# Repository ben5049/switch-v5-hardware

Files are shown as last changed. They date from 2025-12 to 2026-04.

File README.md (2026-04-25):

# Switch v5 Hardware (WIP)

KiCad design files for the 5th iteration of my single pair Ethernet (SPE) switch. It is similar to [v4](https://github.com/ben5049/switch-v4-hardware) but with more ports and an RJ45 connector so an external media converter isn't needed to connect to regular Ethernet networks.

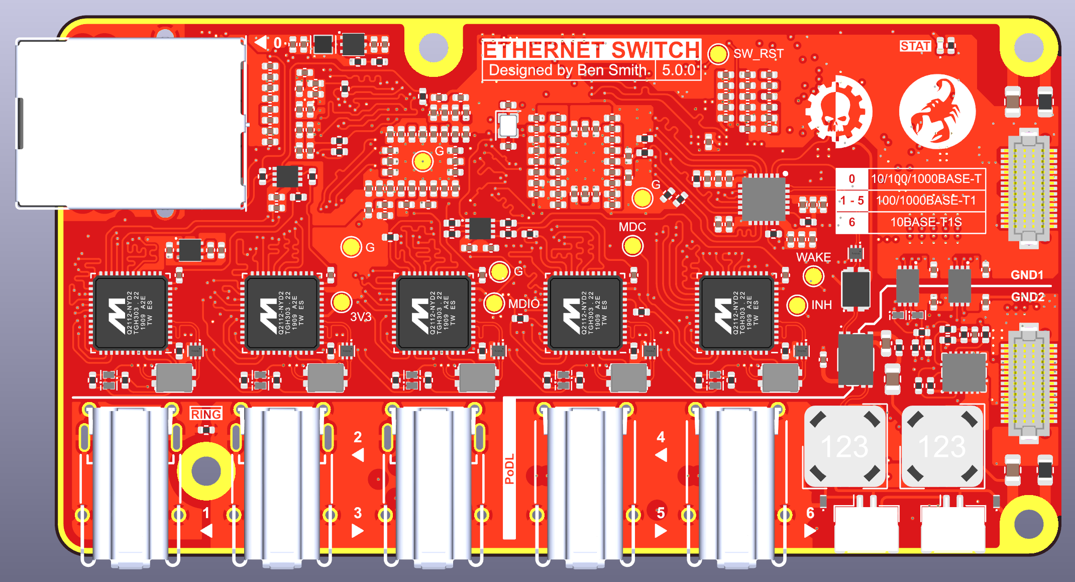
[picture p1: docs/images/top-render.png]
top-render


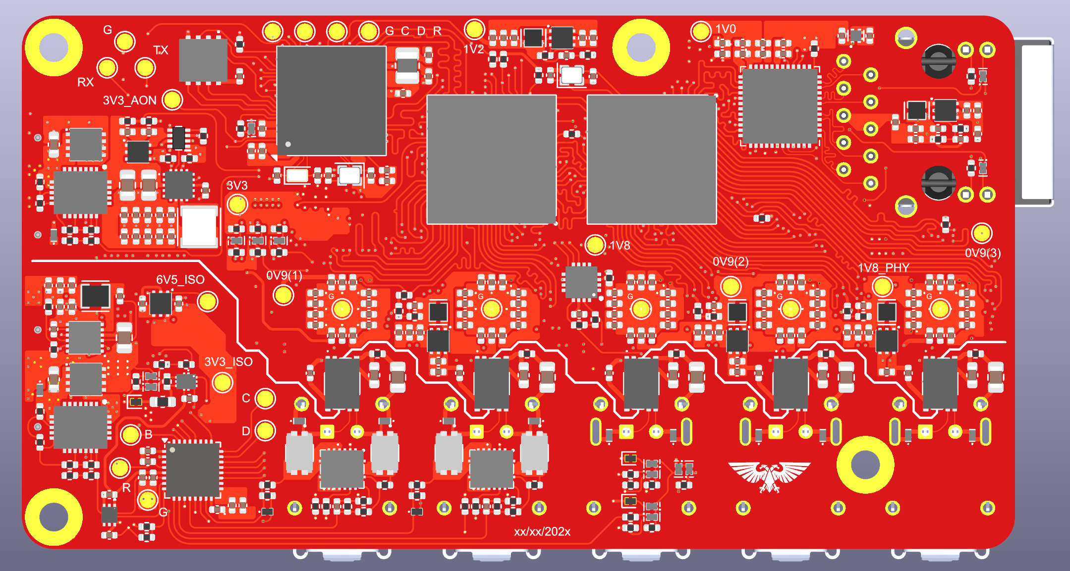
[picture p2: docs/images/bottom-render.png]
bottom-render


## Versions

| Version | Description |
| --- | --- |
| v5.1.0  | Fixed bugs from first revision |
| v5.0.0  | First release |

See the [errata](docs/errata.md) for details on bugs.

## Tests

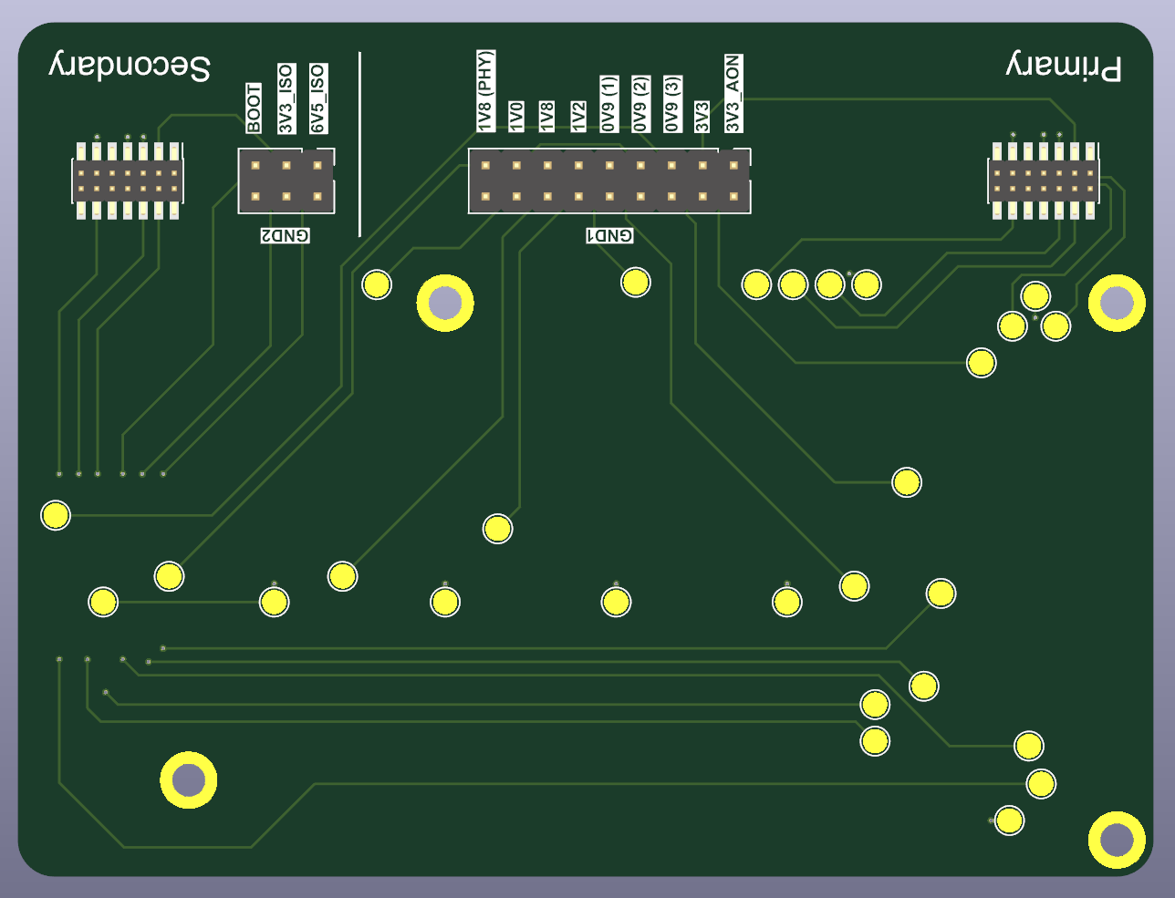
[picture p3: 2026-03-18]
docs/images/test-rig.png

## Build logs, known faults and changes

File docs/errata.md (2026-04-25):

# Switch v5 Errata

## Contents

- [1 Switch v5](#1-switch-v5)
    - [1.1 Wrong IO voltage on switch 1 ports 3 & 4](#11-wrong-io-voltage-on-switch-1-ports-3--4)

## Key

- A = limitation present, workaround available
- N = limitation present, no workaround available
- P = limitation present, partial workaround available
- "-" = limitation absent

## 1 Switch v5

| **Bug** | **5.0.0** | **5.1.0** |
|---|---|---|
| [Wrong IO voltage on switch 1 ports 3 & 4](#11-wrong-io-voltage-on-switch-1-ports-3--4) | A | - |

### 1.1 Wrong IO Voltage on Switch 1 Ports 3 & 4

The IO voltage on the SJA1105Q switch chip 1 ports 3 and 4 is incorrectly set to 3.3V when it should be set to 1.8V. This means PHY 3 doesn't work, and no data can be transferred between the left half of the switch (PHYs 0-3) and the right half of the switch (PHYs 4-6 and the host MCU). By cutting two planes and soldering on a wire between the port 3 & 4 supply capacitors and 1.8V, it is possible to fix this issue. However, PHY3 and switch 0 may be damaged if the device was turned on and traffic was sent at 3.3V.

To fix this issue two cuts need to be made. One from the top going down to inner layer 2, and one simpler one from the bottom. Both are shown in green in the images below:

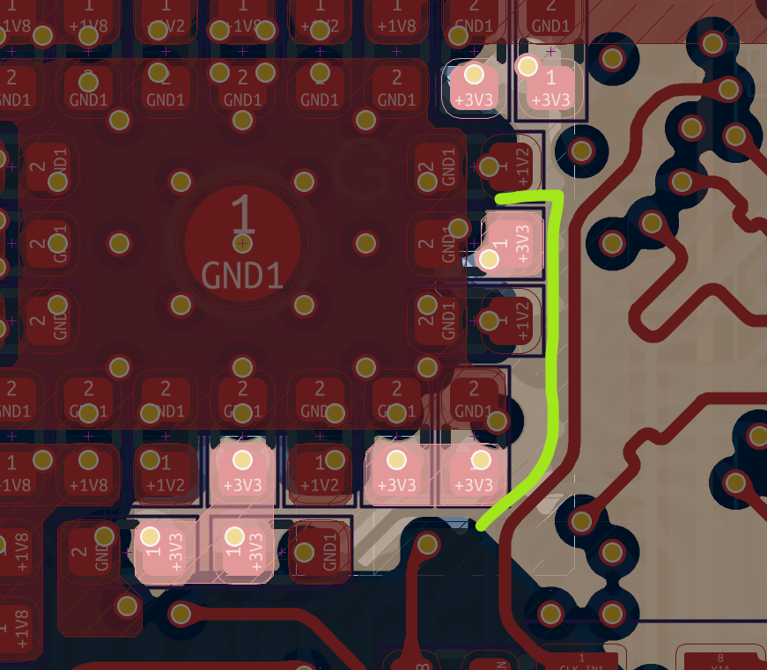
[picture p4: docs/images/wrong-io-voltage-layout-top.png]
wrong-io-voltage-layout-top

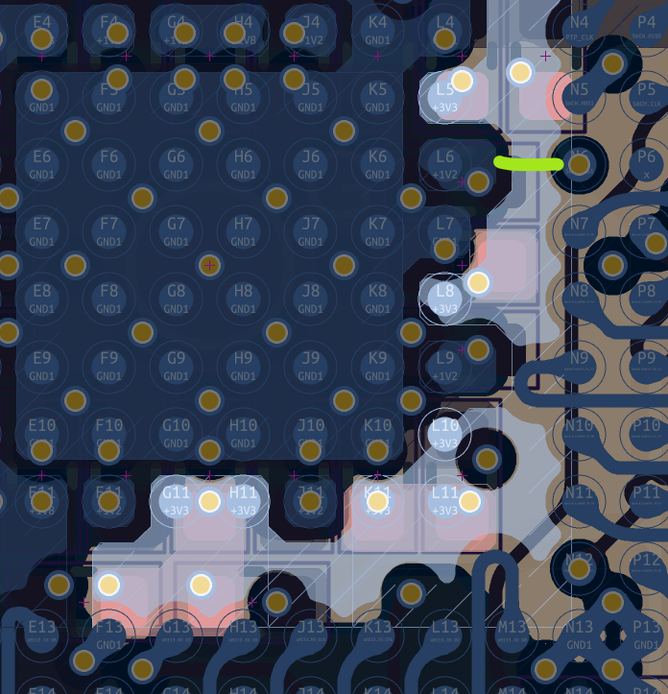
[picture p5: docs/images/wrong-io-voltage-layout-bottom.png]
wrong-io-voltage-layout-bottom


After doing these cuts, a wire needs to be soldered to connect the now floating VDDIO_MII pins to 1.8V. The final bodge can be seen below:

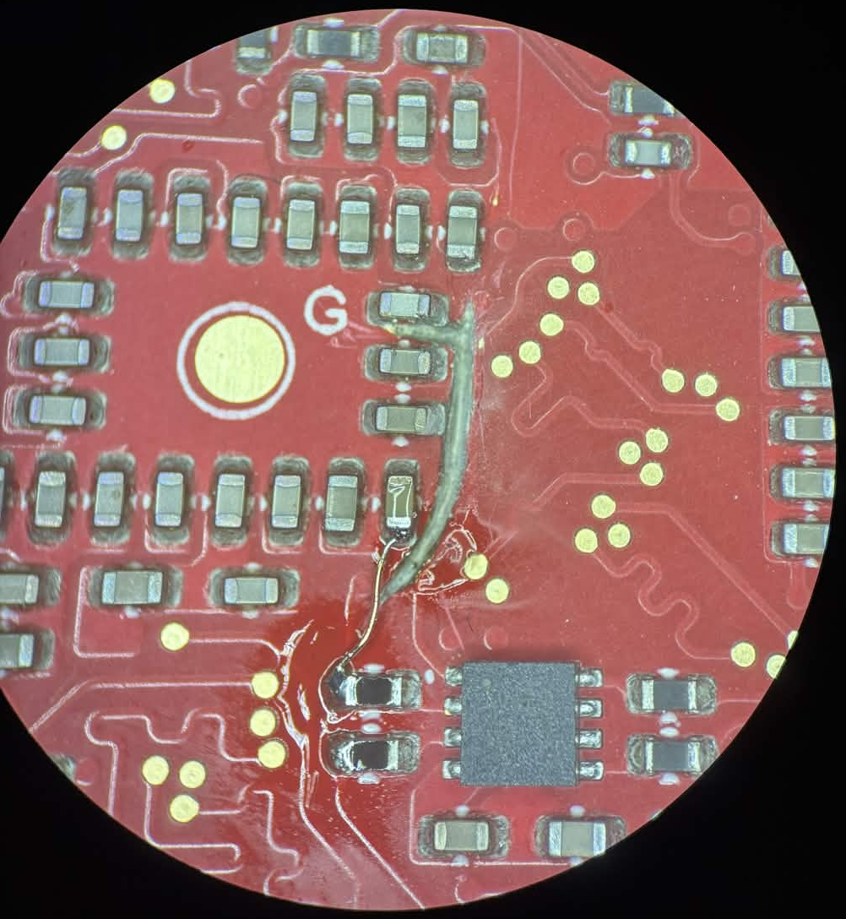
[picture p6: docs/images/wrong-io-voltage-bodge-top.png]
wrong-io-voltage-bodge-top

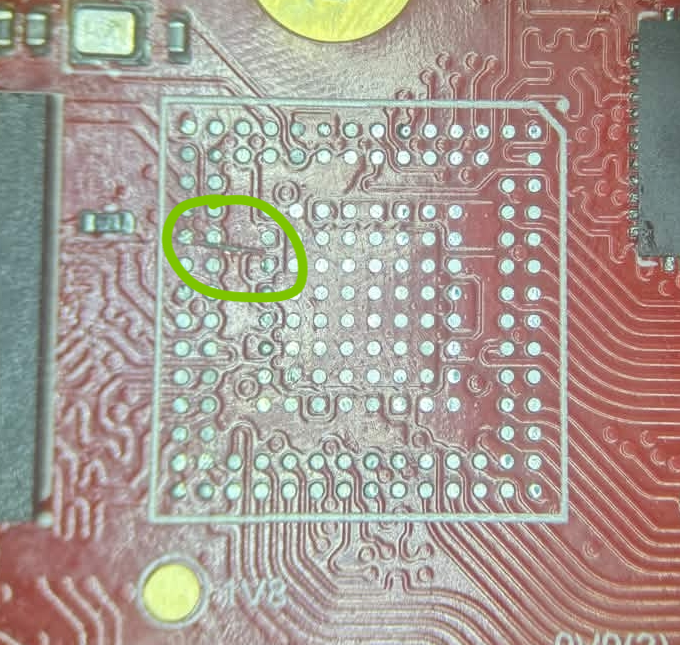
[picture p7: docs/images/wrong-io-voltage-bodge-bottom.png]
wrong-io-voltage-bodge-bottom


Note that care must be taken not to damage the trace running parallel to the top cut since it is a 50MHz clock that drives PHYs 3 to 5.

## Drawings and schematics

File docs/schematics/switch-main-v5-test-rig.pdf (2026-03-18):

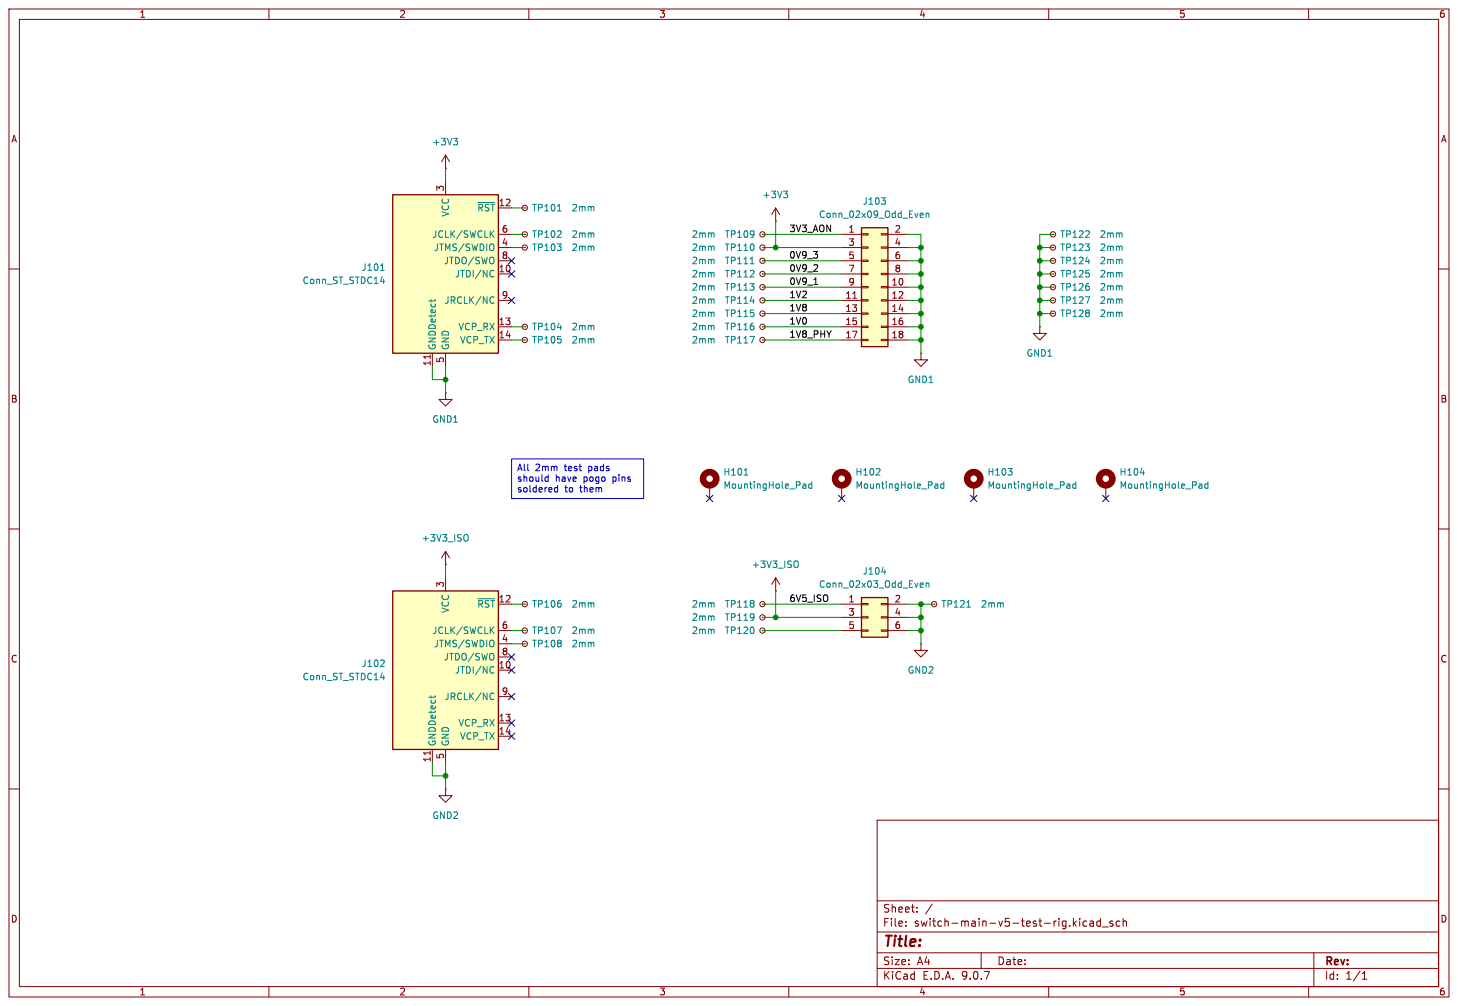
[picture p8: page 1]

All 2mm test pads
should have pogo pins

Id: 1/1 Title: File: switch-main-v5-test-rig.kicad_sch Sheet: /

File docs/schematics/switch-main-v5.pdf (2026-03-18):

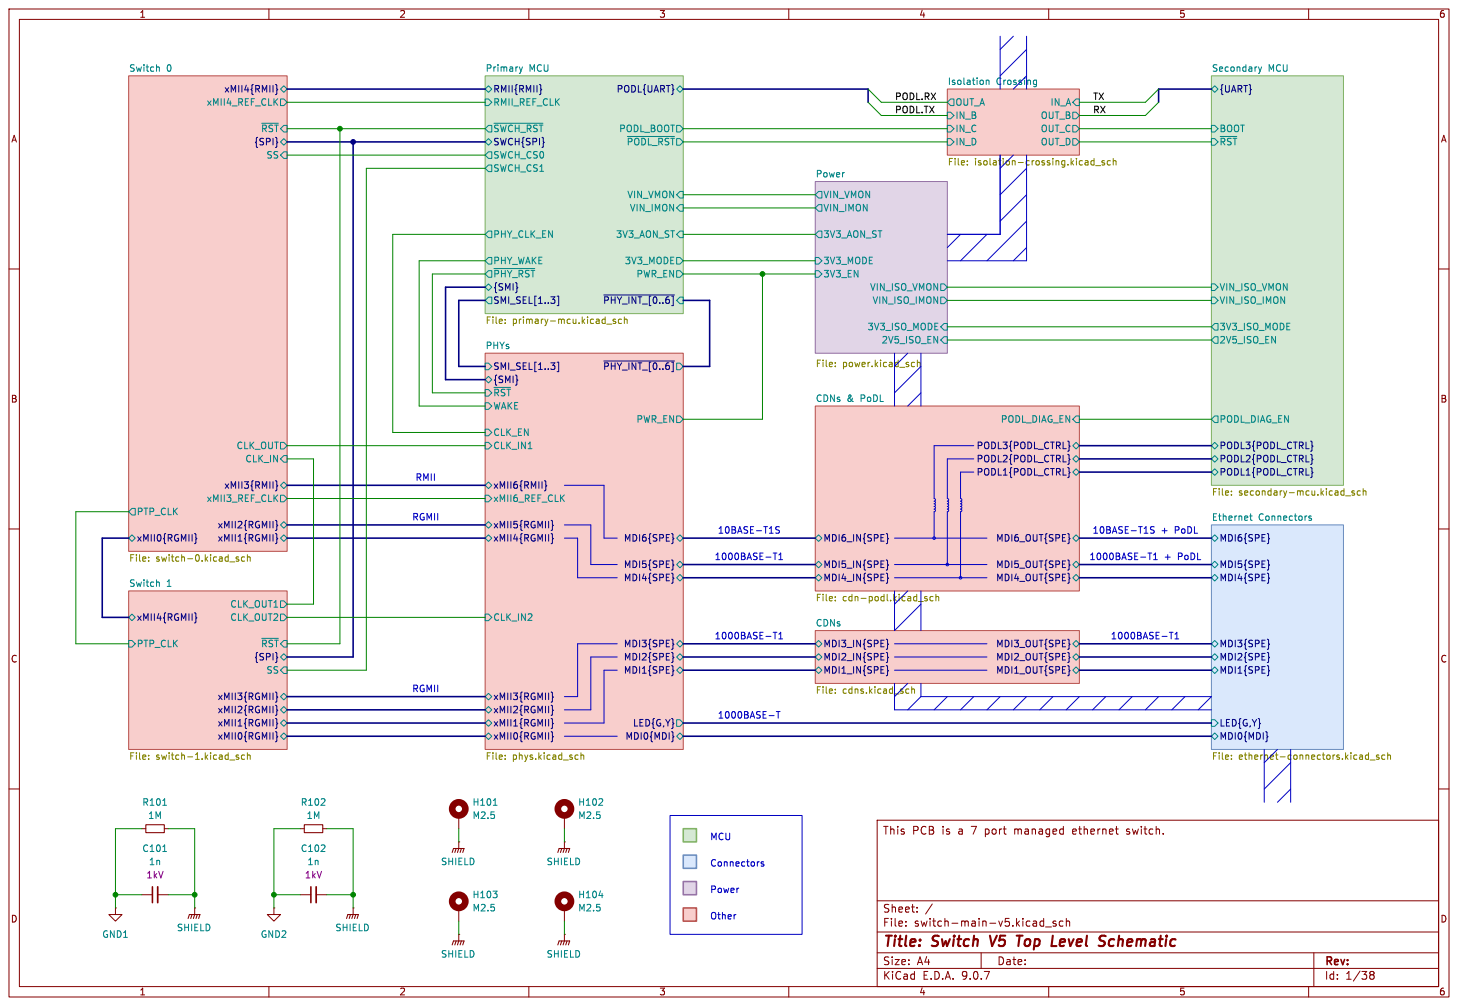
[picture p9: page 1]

LED{G,Y} Ethernet Connectors File: ethernet-connectors.kicad_sch

Id: 1/38 Title: Switch V5 Top Level Schematic

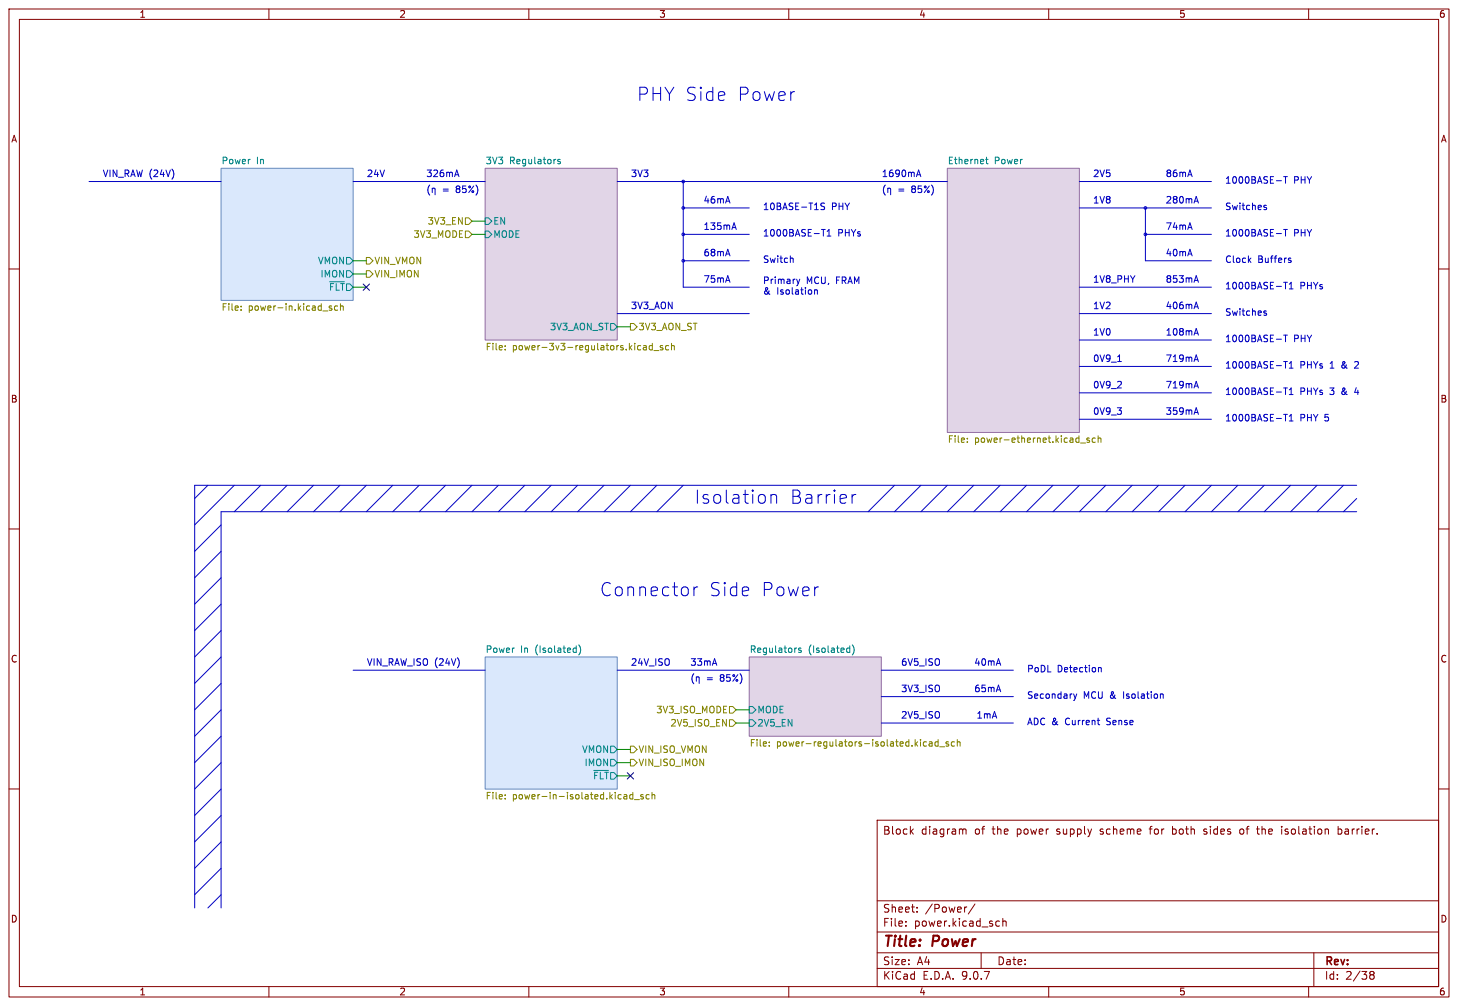
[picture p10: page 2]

46mA PHY Side Power
Ethernet Power File: power-ethernet.kicad_sch

Power In File: power-in.kicad_sch

3V3 Regulators File: power-3v3-regulators.kicad_sch

Power In (Isolated) File: power-in-isolated.kicad_sch

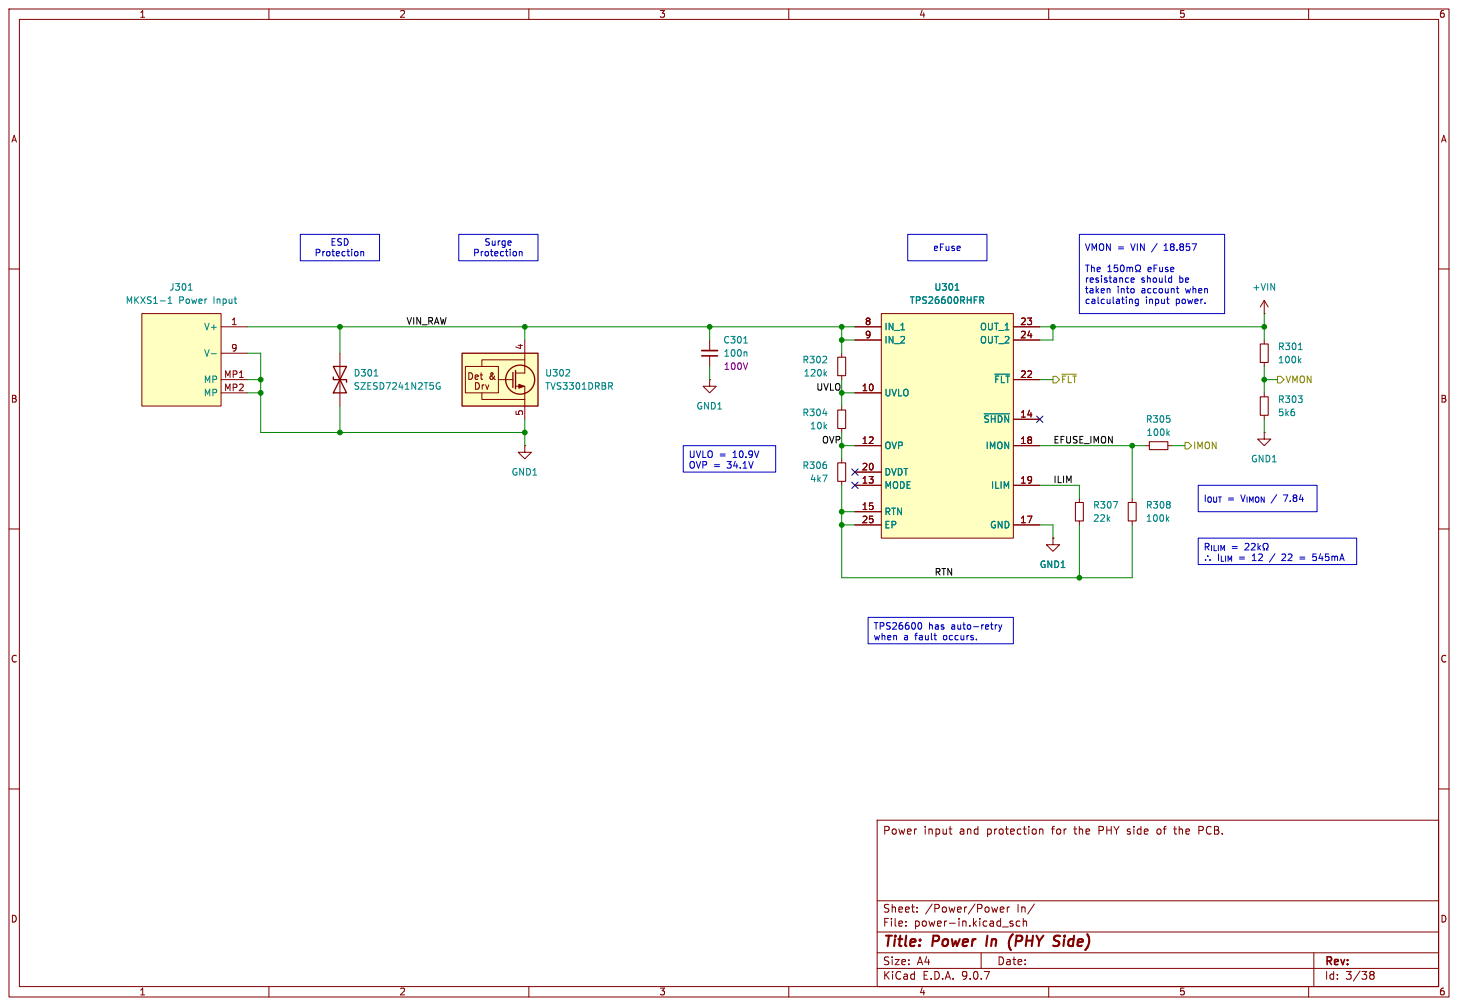
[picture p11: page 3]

I_{OUT} = V_{IMON} / 7.84 VMON = VIN / 18.857 The þÿ150m©eFuse

taken into account when

þÿ"4I_{LIM}= 12 / 22 = 545mA UVLO = 10.9V OVP = 34.1V

3V3_AON switchover
to use most efficient supply.

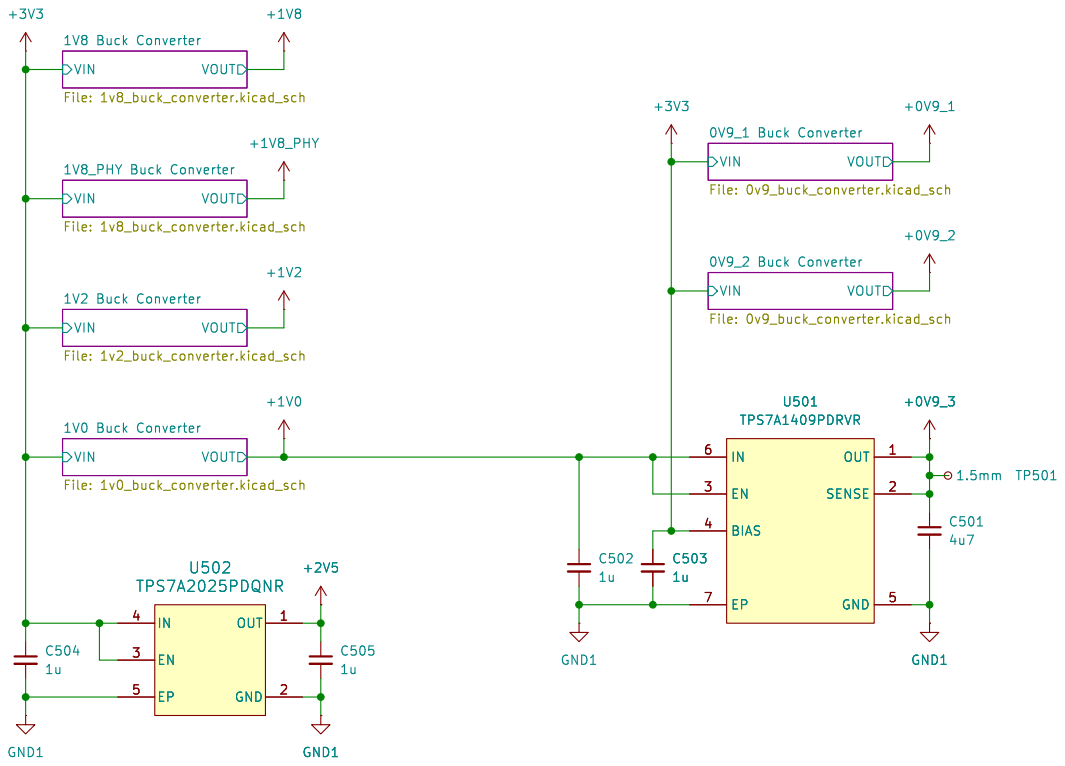
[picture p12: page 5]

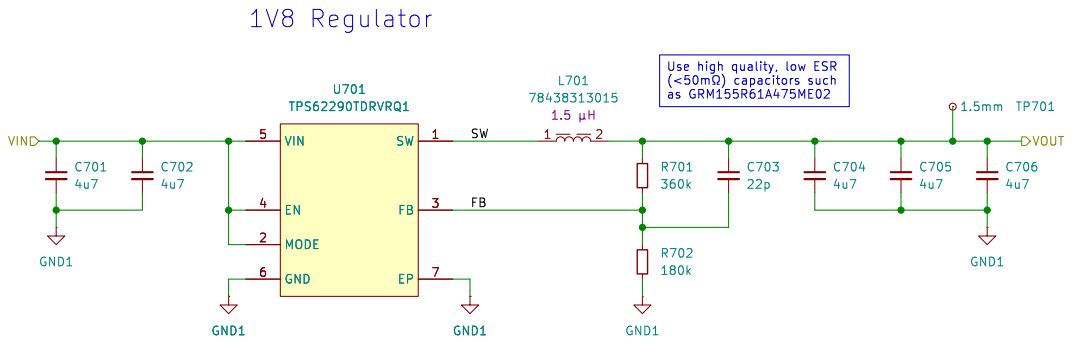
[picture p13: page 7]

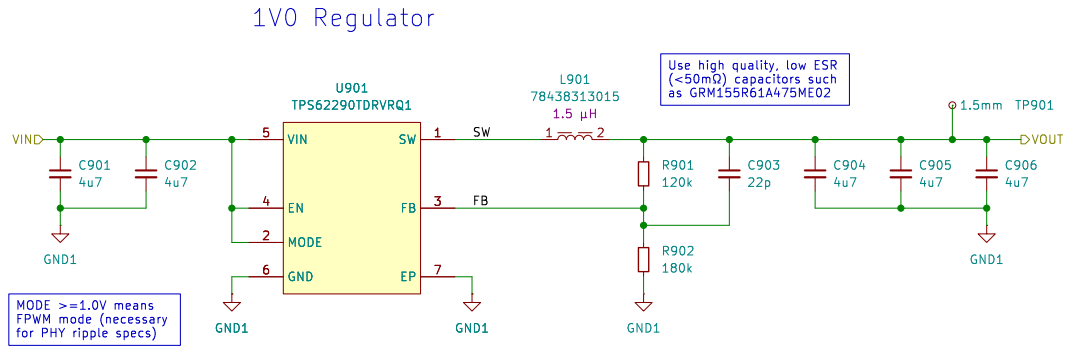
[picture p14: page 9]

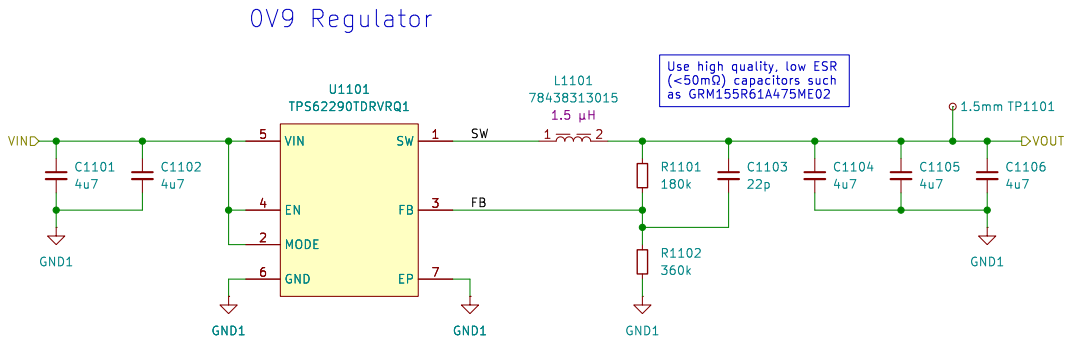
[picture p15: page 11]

taken into account when

I_{OUT} = V_{IMON} / 1.125 Can be done with integers:

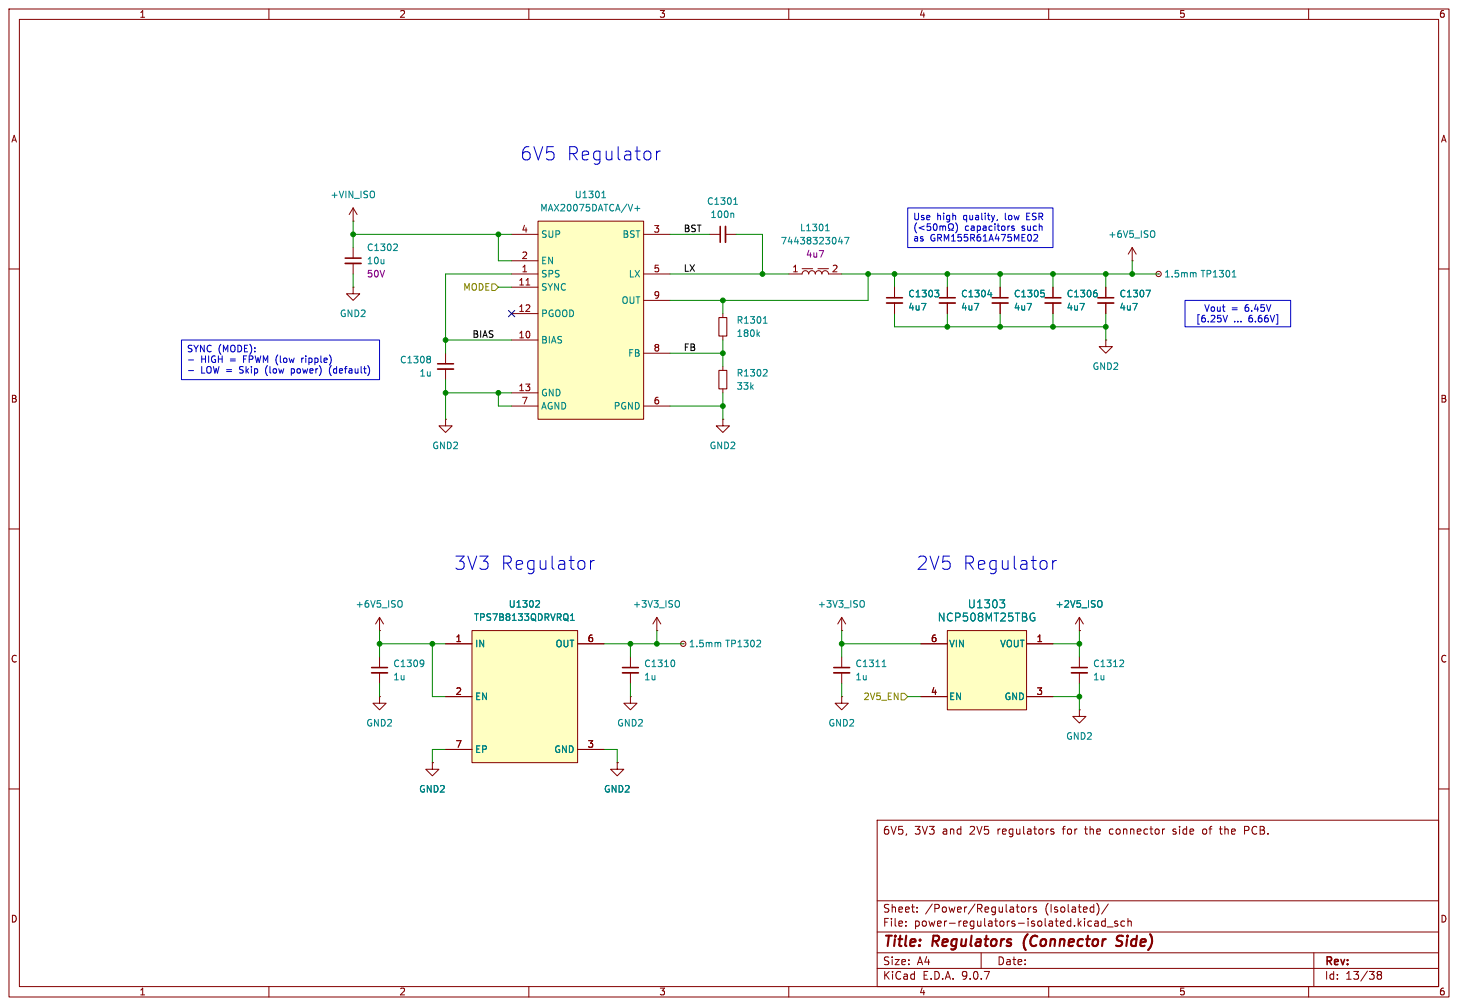
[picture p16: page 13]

[6.25V ... 6.66V] SYNC (MODE): - HIGH = FPWM (low ripple)

- LOW = Skip (low power) (default)

Id: 14/38 Title: Primary MCU

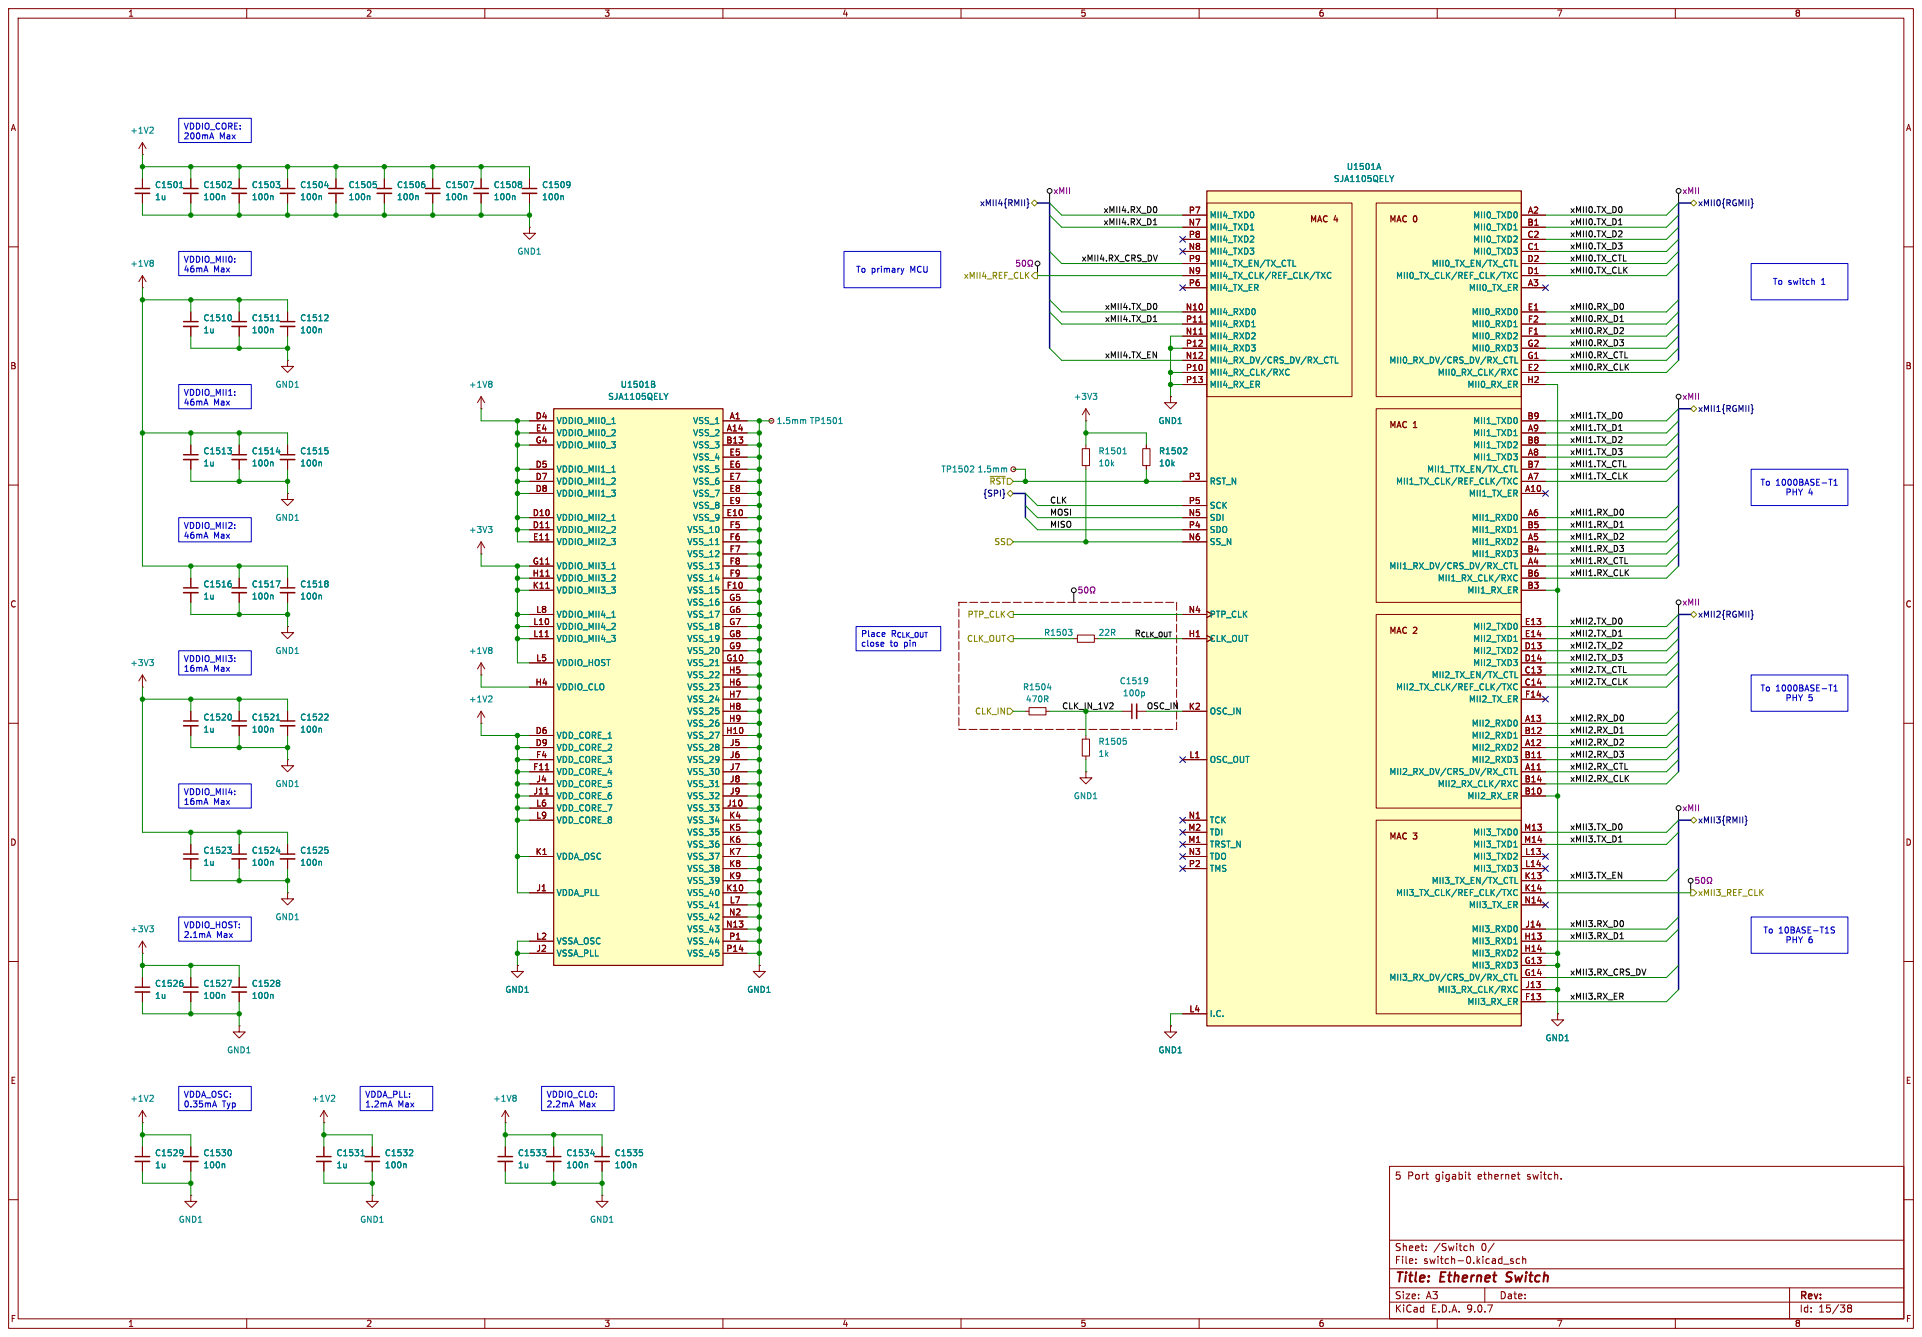
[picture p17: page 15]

Place R_{CLK_OUT} close to pin

Id: 15/38 Title: Ethernet Switch

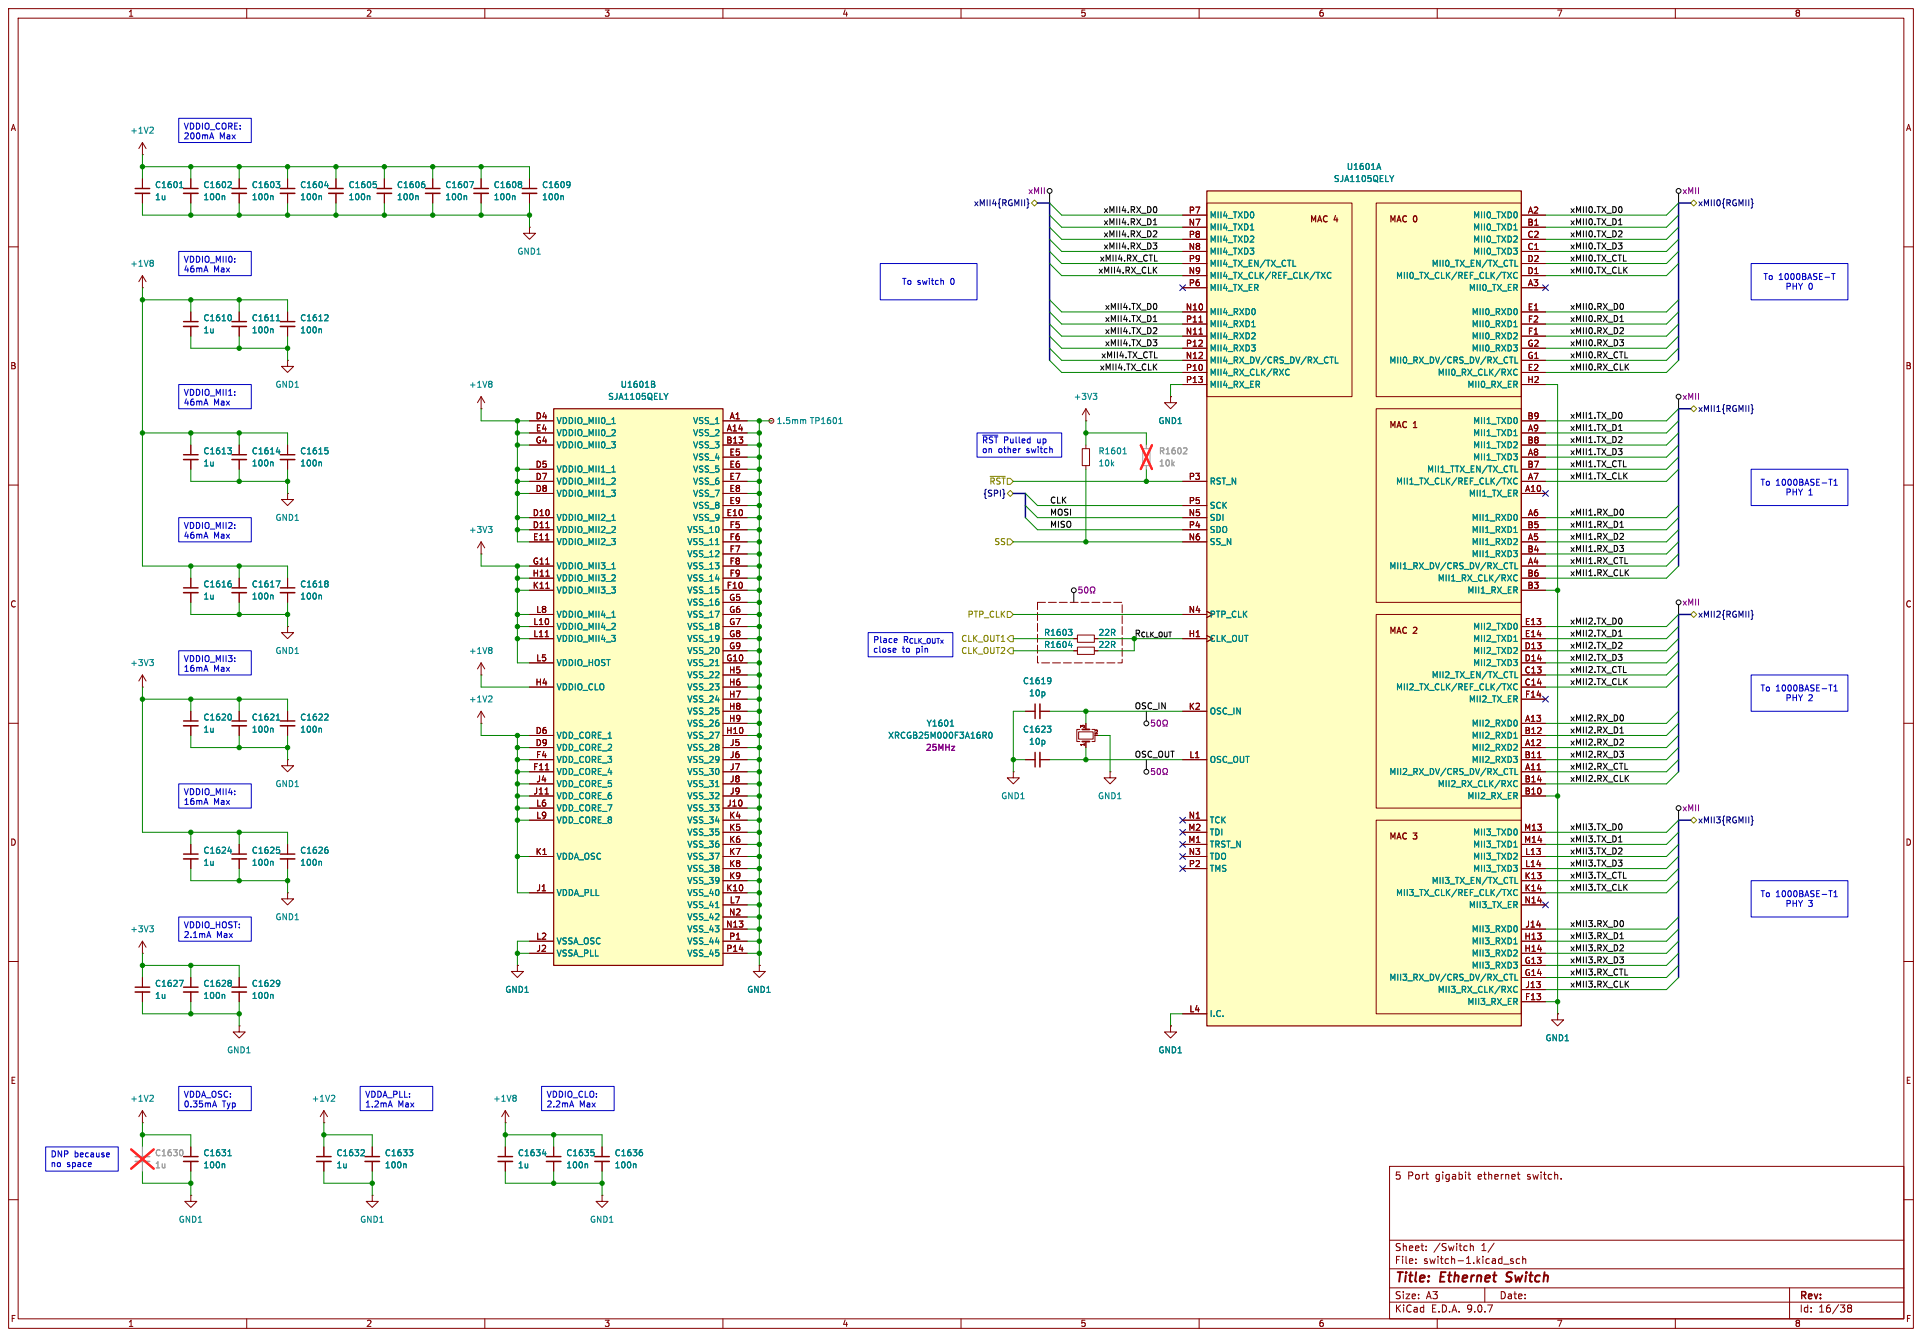
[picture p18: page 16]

Id: 16/38 Title: Ethernet Switch

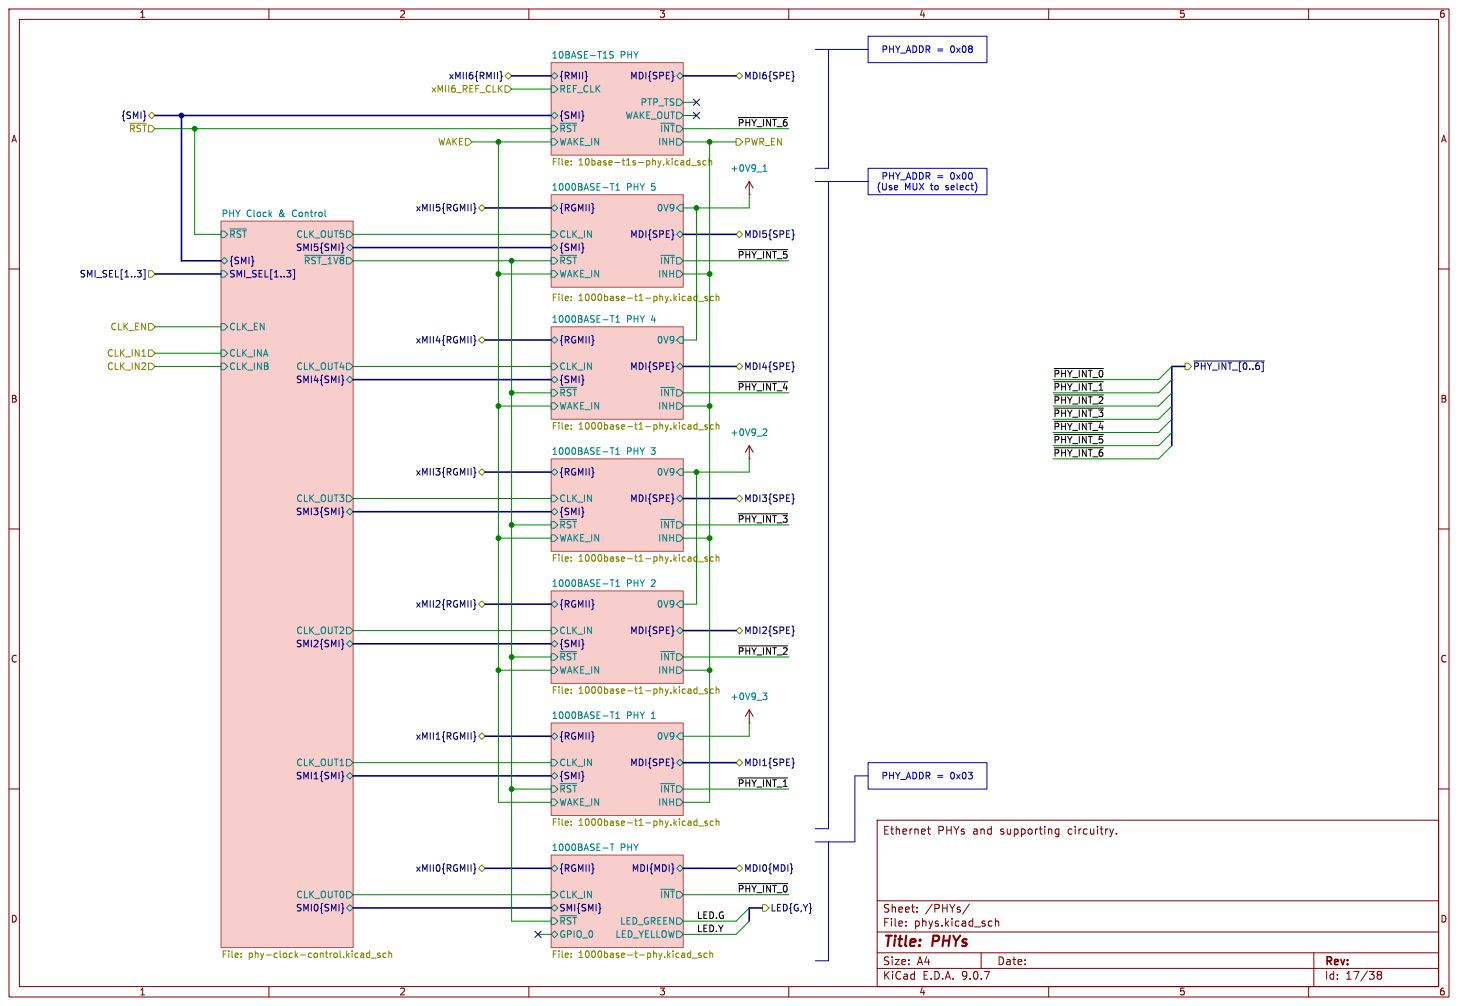
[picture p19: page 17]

PHY_ADDR = 0x00
(Use MUX to select)

File: phy-clock-control.kicad_sch


taken effect (~180ns for 3pF bus) before communicating. Source termination
1.5mm TP1803 GND1

(place close to buffer) Source termination

Id: 18/38 Title: SMI Level Shifting


MDI.TD_A_P MDI.TD_B_P MDI.TD_C_P MDI.TD_A_N

0x00. MODE[1:0] = 0x00 means
the PHY will start as a


0x00. MODE[1:0] = 0x00 means
the PHY will start as a


0x00. MODE[1:0] = 0x00 means
the PHY will start as a

0x00. MODE[1:0] = 0x00 means
the PHY will start as a


0x00. MODE[1:0] = 0x00 means
the PHY will start as a


Id: 26/38 Title: CDNs and PoDL



If the output is shorted
the current is still limited

Each channel can be enabled
devices. Since the outputs share
a current source, only one
channel can be checked at a

be withing 2.5V ADC range.

Id: 30/38 Title: PoDL Detection, Switching and Monitoring

voltage drop across the 1

IMON can go up to
limits this to be withing 2.5V ADC range.

Id: 31/38 Title: MPoE Detection, Switching and Monitoring




Id: 36/38 Title: Ethernet Connectors


Id: 37/38 Title: Isolation Crossing


open drain signal (without

Invert BOOT so it is LOW

Id: 38/38 Title: Secondary MCU

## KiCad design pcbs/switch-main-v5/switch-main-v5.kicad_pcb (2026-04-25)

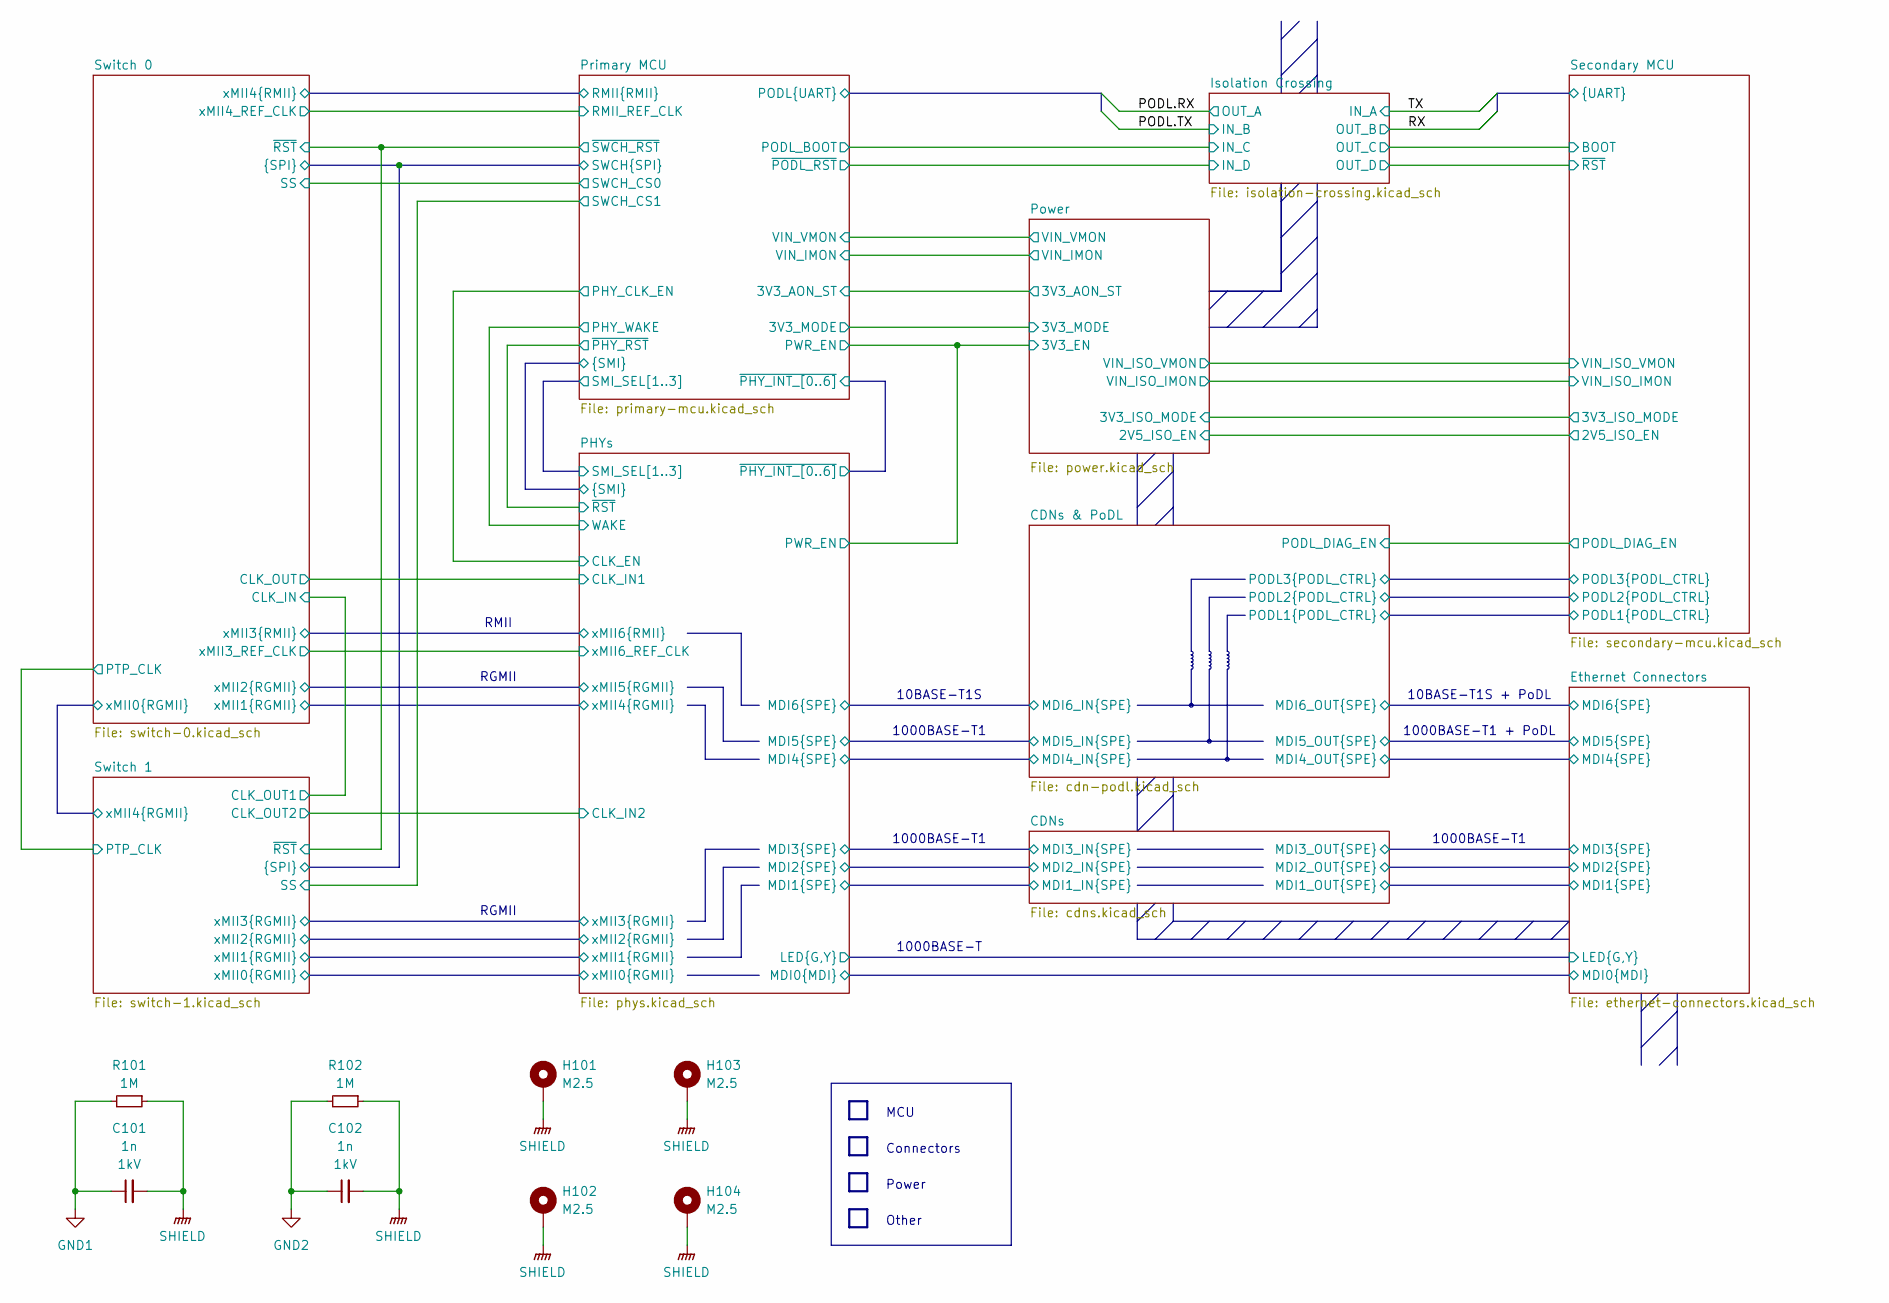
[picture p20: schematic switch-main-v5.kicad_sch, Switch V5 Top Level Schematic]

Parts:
C101, C102: 1n; C_0805; Voltage 1kV
H101, H102, H103, H104: M2.5; MountingHole_2.7mm_M2.5_Pad
R101, R102: 1M; R_0805

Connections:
GND1: C101.1, R101.2; also elsewhere on the board
GND2: C102.1, R102.2; also elsewhere on the board
SHIELD: C101.2, C102.2, H101.1 (1_1), H102.1 (1_1), H103.1 (1_1), H104.1 (1_1), R101.1, R102.1; also elsewhere on the board

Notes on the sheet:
10BASE-T1S
1000BASE-T1
Power
RGMII
Other
1000BASE-T
RMII
Connectors
1000BASE-T1 + PoDL
MCU
10BASE-T1S + PoDL

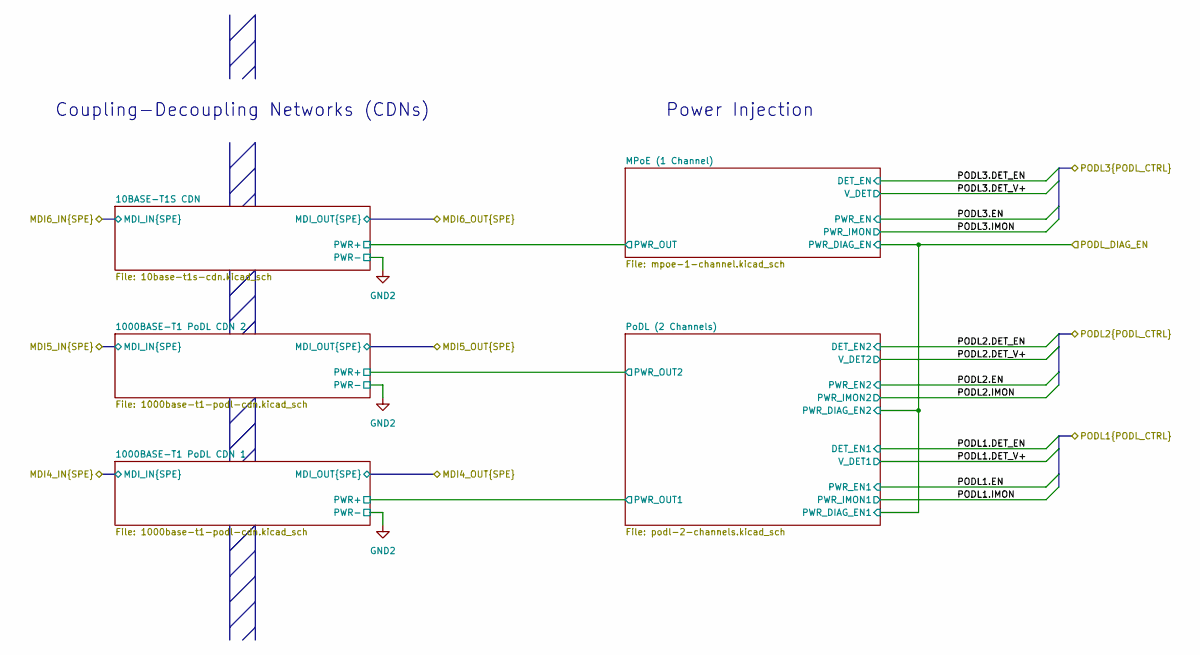
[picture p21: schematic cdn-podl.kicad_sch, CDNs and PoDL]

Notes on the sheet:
Power Injection
Coupling-Decoupling Networks (CDNs)

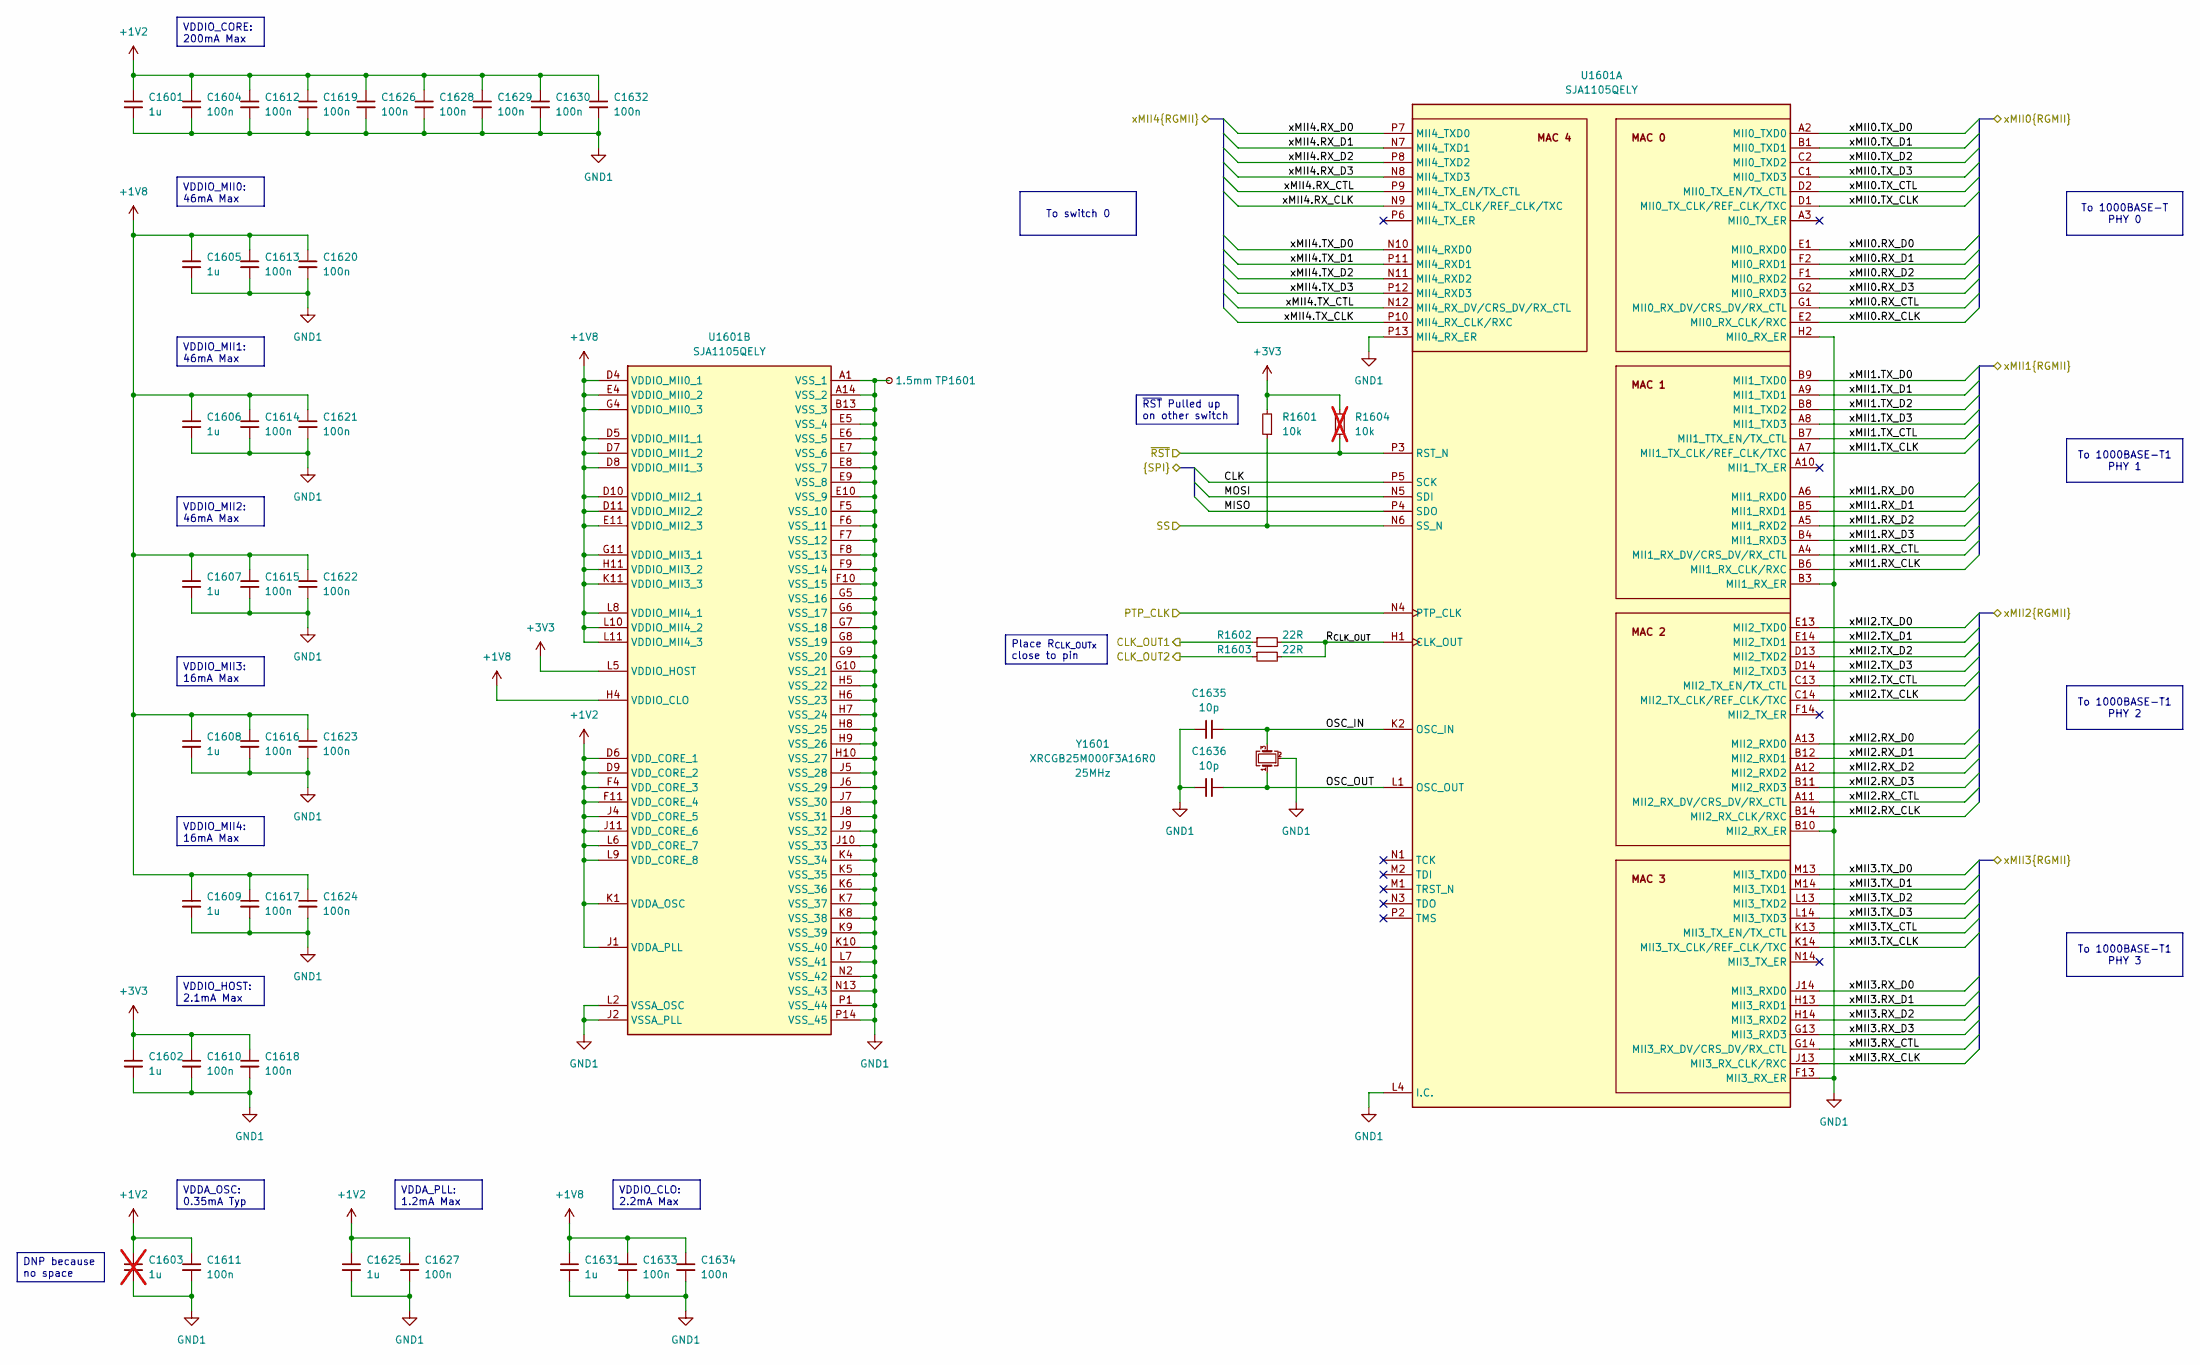
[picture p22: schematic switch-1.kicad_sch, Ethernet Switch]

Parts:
C1601, C1602, C1605, C1606, C1607, C1608, C1609, C1625, C1631: 1u; C_0402
C1603: 1u; C_0402_1005Metric; not fitted
C1604, C1610, C1611, C1612, C1613, C1614, C1615, C1616, C1617, C1618, C1619, C1620, C1621, C1622, C1623, C1624, C1626, C1627, C1628, C1629, C1630, C1632, C1633, C1634: 100n; C_0402
C1635, C1636: 10p; C_0402
R1601: 10k; R_0402
R1602, R1603: 22R; R_0402
R1604: 10k; R_0402_1005Metric; not fitted
TP1601: 1.5mm; TestPoint_Pad_D1.5mm
U1601: SJA1105QELY; BGA159C80P14X14_1200X1200X150; Mouser Part Number 771-SJA1105QELY
Y1601: XRCGB25M000F3A16R0

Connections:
+1V2: C1601.1, C1603.1, C1604.1, C1611.1, C1612.1, C1619.1, C1625.1, C1626.1, C1627.1, C1628.1, C1629.1, C1630.1, C1632.1, U1601.D6 (VDD_CORE_1), U1601.D9 (VDD_CORE_2), U1601.F4 (VDD_CORE_3), U1601.F11 (VDD_CORE_4), U1601.J1 (VDDA_PLL), U1601.J4 (VDD_CORE_5), U1601.J11 (VDD_CORE_6), U1601.K1 (VDDA_OSC), U1601.L6 (VDD_CORE_7), U1601.L9 (VDD_CORE_8); also elsewhere on the board
+1V8: C1605.1, C1606.1, C1607.1, C1608.1, C1609.1, C1613.1, C1614.1, C1615.1, C1616.1, C1617.1, C1620.1, C1621.1, C1622.1, C1623.1, C1624.1, C1631.1, C1633.1, C1634.1, U1601.D4 (VDDIO_MII0_1), U1601.D5 (VDDIO_MII1_1), U1601.D7 (VDDIO_MII1_2), U1601.D8 (VDDIO_MII1_3), U1601.D10 (VDDIO_MII2_1), U1601.D11 (VDDIO_MII2_2), U1601.E4 (VDDIO_MII0_2), U1601.E11 (VDDIO_MII2_3), U1601.G4 (VDDIO_MII0_3), U1601.G11 (VDDIO_MII3_1), U1601.H4 (VDDIO_CLO), U1601.H11 (VDDIO_MII3_2), U1601.K11 (VDDIO_MII3_3), U1601.L8 (VDDIO_MII4_1), U1601.L10 (VDDIO_MII4_2), U1601.L11 (VDDIO_MII4_3); also elsewhere on the board
+3V3: C1602.1, C1610.1, C1618.1, R1601.2, R1604.2, U1601.L5 (VDDIO_HOST); also elsewhere on the board
/PHYs/CLK_IN2: R1603.1; also elsewhere on the board
/PHYs/xMII0.RX_CLK: U1601.E2 (MII0_RX_CLK/RXC); also elsewhere on the board
/PHYs/xMII0.RX_CTL: U1601.G1 (MII0_RX_DV/CRS_DV/RX_CTL); also elsewhere on the board
/PHYs/xMII0.RX_D0: U1601.E1 (MII0_RXD0); also elsewhere on the board
/PHYs/xMII0.RX_D1: U1601.F2 (MII0_RXD1); also elsewhere on the board
/PHYs/xMII0.RX_D2: U1601.F1 (MII0_RXD2); also elsewhere on the board
/PHYs/xMII0.RX_D3: U1601.G2 (MII0_RXD3); also elsewhere on the board
/PHYs/xMII0.TX_CLK: U1601.D1 (MII0_TX_CLK/REF_CLK/TXC); also elsewhere on the board
/PHYs/xMII0.TX_CTL: U1601.D2 (MII0_TX_EN/TX_CTL); also elsewhere on the board
/PHYs/xMII0.TX_D0: U1601.A2 (MII0_TXD0); also elsewhere on the board
/PHYs/xMII0.TX_D1: U1601.B1 (MII0_TXD1); also elsewhere on the board
/PHYs/xMII0.TX_D2: U1601.C2 (MII0_TXD2); also elsewhere on the board
/PHYs/xMII0.TX_D3: U1601.C1 (MII0_TXD3); also elsewhere on the board
/PHYs/xMII1.RX_CLK: U1601.B6 (MII1_RX_CLK/RXC); also elsewhere on the board
/PHYs/xMII1.RX_CTL: U1601.A4 (MII1_RX_DV/CRS_DV/RX_CTL); also elsewhere on the board
/PHYs/xMII1.RX_D0: U1601.A6 (MII1_RXD0); also elsewhere on the board
/PHYs/xMII1.RX_D1: U1601.B5 (MII1_RXD1); also elsewhere on the board
/PHYs/xMII1.RX_D2: U1601.A5 (MII1_RXD2); also elsewhere on the board
/PHYs/xMII1.RX_D3: U1601.B4 (MII1_RXD3); also elsewhere on the board
/PHYs/xMII1.TX_CLK: U1601.A7 (MII1_TX_CLK/REF_CLK/TXC); also elsewhere on the board
/PHYs/xMII1.TX_CTL: U1601.B7 (MII1_TTX_EN/TX_CTL); also elsewhere on the board
/PHYs/xMII1.TX_D0: U1601.B9 (MII1_TXD0); also elsewhere on the board
/PHYs/xMII1.TX_D1: U1601.A9 (MII1_TXD1); also elsewhere on the board
/PHYs/xMII1.TX_D2: U1601.B8 (MII1_TXD2); also elsewhere on the board
/PHYs/xMII1.TX_D3: U1601.A8 (MII1_TXD3); also elsewhere on the board
/PHYs/xMII2.RX_CLK: U1601.B14 (MII2_RX_CLK/RXC); also elsewhere on the board
/PHYs/xMII2.RX_CTL: U1601.A11 (MII2_RX_DV/CRS_DV/RX_CTL); also elsewhere on the board
/PHYs/xMII2.RX_D0: U1601.A13 (MII2_RXD0); also elsewhere on the board
/PHYs/xMII2.RX_D1: U1601.B12 (MII2_RXD1); also elsewhere on the board
/PHYs/xMII2.RX_D2: U1601.A12 (MII2_RXD2); also elsewhere on the board
/PHYs/xMII2.RX_D3: U1601.B11 (MII2_RXD3); also elsewhere on the board
/PHYs/xMII2.TX_CLK: U1601.C14 (MII2_TX_CLK/REF_CLK/TXC); also elsewhere on the board
/PHYs/xMII2.TX_CTL: U1601.C13 (MII2_TX_EN/TX_CTL); also elsewhere on the board
/PHYs/xMII2.TX_D0: U1601.E13 (MII2_TXD0); also elsewhere on the board
/PHYs/xMII2.TX_D1: U1601.E14 (MII2_TXD1); also elsewhere on the board
/PHYs/xMII2.TX_D2: U1601.D13 (MII2_TXD2); also elsewhere on the board
/PHYs/xMII2.TX_D3: U1601.D14 (MII2_TXD3); also elsewhere on the board
/PHYs/xMII3.RX_CLK: U1601.J13 (MII3_RX_CLK/RXC); also elsewhere on the board
/PHYs/xMII3.RX_CTL: U1601.G14 (MII3_RX_DV/CRS_DV/RX_CTL); also elsewhere on the board
/PHYs/xMII3.RX_D0: U1601.J14 (MII3_RXD0); also elsewhere on the board
/PHYs/xMII3.RX_D1: U1601.H13 (MII3_RXD1); also elsewhere on the board
/PHYs/xMII3.RX_D2: U1601.H14 (MII3_RXD2); also elsewhere on the board
/PHYs/xMII3.RX_D3: U1601.G13 (MII3_RXD3); also elsewhere on the board
/PHYs/xMII3.TX_CLK: U1601.K14 (MII3_TX_CLK/REF_CLK/TXC); also elsewhere on the board
/PHYs/xMII3.TX_CTL: U1601.K13 (MII3_TX_EN/TX_CTL); also elsewhere on the board
/PHYs/xMII3.TX_D0: U1601.M13 (MII3_TXD0); also elsewhere on the board
/PHYs/xMII3.TX_D1: U1601.M14 (MII3_TXD1); also elsewhere on the board
/PHYs/xMII3.TX_D2: U1601.L13 (MII3_TXD2); also elsewhere on the board
/PHYs/xMII3.TX_D3: U1601.L14 (MII3_TXD3); also elsewhere on the board
/Primary MCU/SWCH.CLK: U1601.P5 (SCK); also elsewhere on the board
/Primary MCU/SWCH.MISO: U1601.P4 (SDO); also elsewhere on the board
/Primary MCU/SWCH.MOSI: U1601.N5 (SDI); also elsewhere on the board
/Primary MCU/SWCH_CS1: R1601.1, U1601.N6 (SS_N); also elsewhere on the board
/Primary MCU/~SWCH_RST: R1604.1, U1601.P3 (RST_N); also elsewhere on the board
/Switch 0/CLK_IN: R1602.1; also elsewhere on the board
/Switch 0/PTP_CLK: U1601.N4 (PTP_CLK); also elsewhere on the board
/Switch 0/xMII0.RX_CLK: U1601.N9 (MII4_TX_CLK/REF_CLK/TXC); also elsewhere on the board
/Switch 0/xMII0.RX_CTL: U1601.P9 (MII4_TX_EN/TX_CTL); also elsewhere on the board
/Switch 0/xMII0.RX_D0: U1601.P7 (MII4_TXD0); also elsewhere on the board
/Switch 0/xMII0.RX_D1: U1601.N7 (MII4_TXD1); also elsewhere on the board
/Switch 0/xMII0.RX_D2: U1601.P8 (MII4_TXD2); also elsewhere on the board
/Switch 0/xMII0.RX_D3: U1601.N8 (MII4_TXD3); also elsewhere on the board
/Switch 0/xMII0.TX_CLK: U1601.P10 (MII4_RX_CLK/RXC); also elsewhere on the board
/Switch 0/xMII0.TX_CTL: U1601.N12 (MII4_RX_DV/CRS_DV/RX_CTL); also elsewhere on the board
/Switch 0/xMII0.TX_D0: U1601.N10 (MII4_RXD0); also elsewhere on the board
/Switch 0/xMII0.TX_D1: U1601.P11 (MII4_RXD1); also elsewhere on the board
/Switch 0/xMII0.TX_D2: U1601.N11 (MII4_RXD2); also elsewhere on the board
/Switch 0/xMII0.TX_D3: U1601.P12 (MII4_RXD3); also elsewhere on the board
/Switch 1/OSC_IN: C1635.2, U1601.K2 (OSC_IN), Y1601.3
/Switch 1/OSC_OUT: C1636.2, U1601.L1 (OSC_OUT), Y1601.1
/Switch 1/R_{CLK_OUT}: R1602.2, R1603.2, U1601.H1 (CLK_OUT)
GND1: C1601.2, C1602.2, C1603.2, C1604.2, C1605.2, C1606.2, C1607.2, C1608.2, C1609.2, C1610.2, C1611.2, C1612.2, C1613.2, C1614.2, C1615.2, C1616.2, C1617.2, C1618.2, C1619.2, C1620.2, C1621.2, C1622.2, C1623.2, C1624.2, C1625.2, C1626.2, C1627.2, C1628.2, C1629.2, C1630.2, C1631.2, C1632.2, C1633.2, C1634.2, C1635.1, C1636.1, TP1601.1 (1_1), U1601.A1 (VSS_1), U1601.A14 (VSS_2), U1601.B3 (MII1_RX_ER), U1601.B10 (MII2_RX_ER), U1601.B13 (VSS_3), U1601.E5 (VSS_4), U1601.E6 (VSS_5), U1601.E7 (VSS_6), U1601.E8 (VSS_7), U1601.E9 (VSS_8), U1601.E10 (VSS_9), U1601.F5 (VSS_10), U1601.F6 (VSS_11), U1601.F7 (VSS_12), U1601.F8 (VSS_13), U1601.F9 (VSS_14), U1601.F10 (VSS_15), U1601.F13 (MII3_RX_ER), U1601.G5 (VSS_16), U1601.G6 (VSS_17), U1601.G7 (VSS_18), U1601.G8 (VSS_19), U1601.G9 (VSS_20), U1601.G10 (VSS_21), U1601.H2 (MII0_RX_ER), U1601.H5 (VSS_22), U1601.H6 (VSS_23), U1601.H7 (VSS_24), U1601.H8 (VSS_25), U1601.H9 (VSS_26), U1601.H10 (VSS_27), U1601.J2 (VSSA_PLL), U1601.J5 (VSS_28), U1601.J6 (VSS_29), U1601.J7 (VSS_30), U1601.J8 (VSS_31), U1601.J9 (VSS_32), U1601.J10 (VSS_33), U1601.K4 (VSS_34), U1601.K5 (VSS_35), U1601.K6 (VSS_36), U1601.K7 (VSS_37), U1601.K8 (VSS_38), U1601.K9 (VSS_39), U1601.K10 (VSS_40), U1601.L2 (VSSA_OSC), U1601.L4 (I.C.), U1601.L7 (VSS_41), U1601.N2 (VSS_42), U1601.N13 (VSS_43), U1601.P1 (VSS_44), U1601.P13 (MII4_RX_ER), U1601.P14 (VSS_45), Y1601.2 (G), Y1601.4 (G); also elsewhere on the board

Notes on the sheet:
To 1000BASE-T1 PHY 1
To 1000BASE-T1 PHY 2
VDDIO_MII3: 16mA Max
~{RST} Pulled up on other switch
To 1000BASE-T1 PHY 3
VDDIO_CLO: 2.2mA Max
VDDIO_MII2: 46mA Max
VDDIO_HOST: 2.1mA Max
VDDA_OSC: 0.35mA Typ
DNP because no space
VDDIO_MII0: 46mA Max
To switch 0
VDDA_PLL: 1.2mA Max
VDDIO_CORE: 200mA Max
Place R_{CLK_OUTx} close to pin
To 1000BASE-T PHY 0
VDDIO_MII4: 16mA Max
VDDIO_MII1: 46mA Max

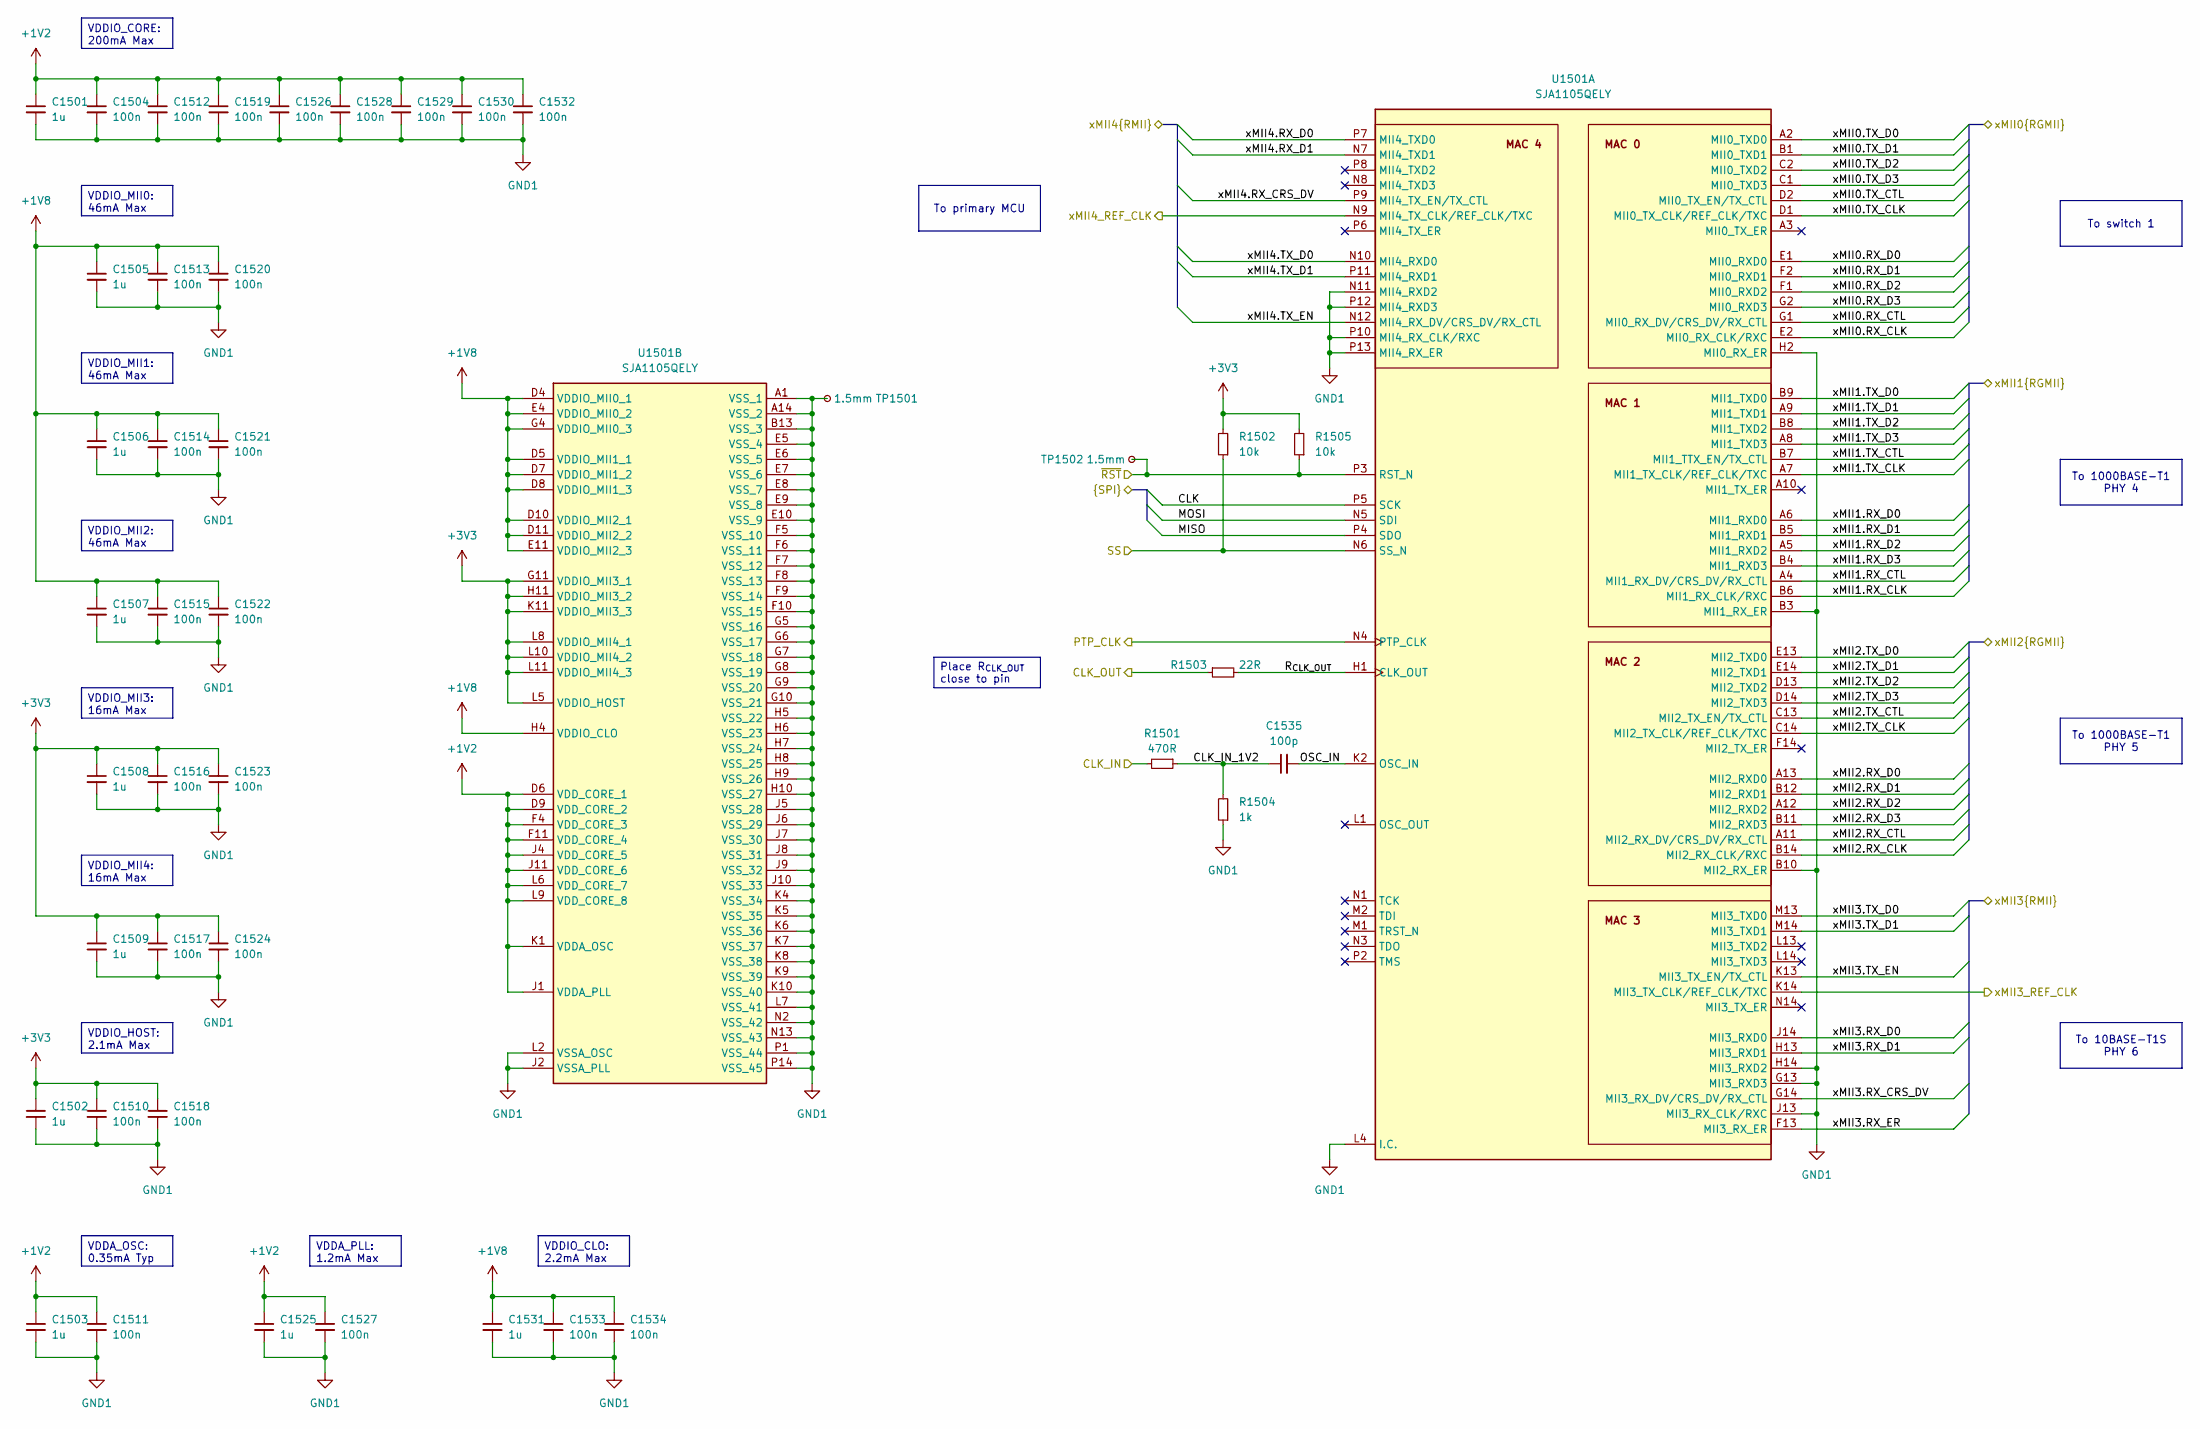
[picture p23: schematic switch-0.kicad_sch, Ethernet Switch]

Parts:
C1501, C1502, C1503, C1505, C1506, C1507, C1508, C1509, C1525, C1531: 1u; C_0402
C1504, C1510, C1511, C1512, C1513, C1514, C1515, C1516, C1517, C1518, C1519, C1520, C1521, C1522, C1523, C1524, C1526, C1527, C1528, C1529, C1530, C1532, C1533, C1534: 100n; C_0402
C1535: 100p; C_0402
R1501: 470R; R_0402
R1502, R1505: 10k; R_0402
R1503: 22R; R_0402
R1504: 1k; R_0402
TP1501, TP1502: 1.5mm; TestPoint_Pad_D1.5mm
U1501: SJA1105QELY; BGA159C80P14X14_1200X1200X150; Mouser Part Number 771-SJA1105QELY

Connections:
+1V2: C1501.1, C1503.1, C1504.1, C1511.1, C1512.1, C1519.1, C1525.1, C1526.1, C1527.1, C1528.1, C1529.1, C1530.1, C1532.1, U1501.D6 (VDD_CORE_1), U1501.D9 (VDD_CORE_2), U1501.F4 (VDD_CORE_3), U1501.F11 (VDD_CORE_4), U1501.J1 (VDDA_PLL), U1501.J4 (VDD_CORE_5), U1501.J11 (VDD_CORE_6), U1501.K1 (VDDA_OSC), U1501.L6 (VDD_CORE_7), U1501.L9 (VDD_CORE_8); also elsewhere on the board
+1V8: C1505.1, C1506.1, C1507.1, C1513.1, C1514.1, C1515.1, C1520.1, C1521.1, C1522.1, C1531.1, C1533.1, C1534.1, U1501.D4 (VDDIO_MII0_1), U1501.D5 (VDDIO_MII1_1), U1501.D7 (VDDIO_MII1_2), U1501.D8 (VDDIO_MII1_3), U1501.D10 (VDDIO_MII2_1), U1501.D11 (VDDIO_MII2_2), U1501.E4 (VDDIO_MII0_2), U1501.E11 (VDDIO_MII2_3), U1501.G4 (VDDIO_MII0_3), U1501.H4 (VDDIO_CLO); also elsewhere on the board
+3V3: C1502.1, C1508.1, C1509.1, C1510.1, C1516.1, C1517.1, C1518.1, C1523.1, C1524.1, R1502.2, R1505.2, U1501.G11 (VDDIO_MII3_1), U1501.H11 (VDDIO_MII3_2), U1501.K11 (VDDIO_MII3_3), U1501.L5 (VDDIO_HOST), U1501.L8 (VDDIO_MII4_1), U1501.L10 (VDDIO_MII4_2), U1501.L11 (VDDIO_MII4_3); also elsewhere on the board
/PHYs/CLK_IN1: R1503.1; also elsewhere on the board
/PHYs/xMII4.RX_CLK: U1501.B6 (MII1_RX_CLK/RXC); also elsewhere on the board
/PHYs/xMII4.RX_CTL: U1501.A4 (MII1_RX_DV/CRS_DV/RX_CTL); also elsewhere on the board
/PHYs/xMII4.RX_D0: U1501.A6 (MII1_RXD0); also elsewhere on the board
/PHYs/xMII4.RX_D1: U1501.B5 (MII1_RXD1); also elsewhere on the board
/PHYs/xMII4.RX_D2: U1501.A5 (MII1_RXD2); also elsewhere on the board
/PHYs/xMII4.RX_D3: U1501.B4 (MII1_RXD3); also elsewhere on the board
/PHYs/xMII4.TX_CLK: U1501.A7 (MII1_TX_CLK/REF_CLK/TXC); also elsewhere on the board
/PHYs/xMII4.TX_CTL: U1501.B7 (MII1_TTX_EN/TX_CTL); also elsewhere on the board
/PHYs/xMII4.TX_D0: U1501.B9 (MII1_TXD0); also elsewhere on the board
/PHYs/xMII4.TX_D1: U1501.A9 (MII1_TXD1); also elsewhere on the board
/PHYs/xMII4.TX_D2: U1501.B8 (MII1_TXD2); also elsewhere on the board
/PHYs/xMII4.TX_D3: U1501.A8 (MII1_TXD3); also elsewhere on the board
/PHYs/xMII5.RX_CLK: U1501.B14 (MII2_RX_CLK/RXC); also elsewhere on the board
/PHYs/xMII5.RX_CTL: U1501.A11 (MII2_RX_DV/CRS_DV/RX_CTL); also elsewhere on the board
/PHYs/xMII5.RX_D0: U1501.A13 (MII2_RXD0); also elsewhere on the board
/PHYs/xMII5.RX_D1: U1501.B12 (MII2_RXD1); also elsewhere on the board
/PHYs/xMII5.RX_D2: U1501.A12 (MII2_RXD2); also elsewhere on the board
/PHYs/xMII5.RX_D3: U1501.B11 (MII2_RXD3); also elsewhere on the board
/PHYs/xMII5.TX_CLK: U1501.C14 (MII2_TX_CLK/REF_CLK/TXC); also elsewhere on the board
/PHYs/xMII5.TX_CTL: U1501.C13 (MII2_TX_EN/TX_CTL); also elsewhere on the board
/PHYs/xMII5.TX_D0: U1501.E13 (MII2_TXD0); also elsewhere on the board
/PHYs/xMII5.TX_D1: U1501.E14 (MII2_TXD1); also elsewhere on the board
/PHYs/xMII5.TX_D2: U1501.D13 (MII2_TXD2); also elsewhere on the board
/PHYs/xMII5.TX_D3: U1501.D14 (MII2_TXD3); also elsewhere on the board
/PHYs/xMII6.RX_CRS_DV: U1501.G14 (MII3_RX_DV/CRS_DV/RX_CTL); also elsewhere on the board
/PHYs/xMII6.RX_D0: U1501.J14 (MII3_RXD0); also elsewhere on the board
/PHYs/xMII6.RX_D1: U1501.H13 (MII3_RXD1); also elsewhere on the board
/PHYs/xMII6.RX_ER: U1501.F13 (MII3_RX_ER); also elsewhere on the board
/PHYs/xMII6.TX_D0: U1501.M13 (MII3_TXD0); also elsewhere on the board
/PHYs/xMII6.TX_D1: U1501.M14 (MII3_TXD1); also elsewhere on the board
/PHYs/xMII6.TX_EN: U1501.K13 (MII3_TX_EN/TX_CTL); also elsewhere on the board
/PHYs/xMII6_REF_CLK: U1501.K14 (MII3_TX_CLK/REF_CLK/TXC); also elsewhere on the board
/Primary MCU/RMII.RX_CRS_DV: U1501.P9 (MII4_TX_EN/TX_CTL); also elsewhere on the board
/Primary MCU/RMII.RX_D0: U1501.P7 (MII4_TXD0); also elsewhere on the board
/Primary MCU/RMII.RX_D1: U1501.N7 (MII4_TXD1); also elsewhere on the board
/Primary MCU/RMII.TX_D0: U1501.N10 (MII4_RXD0); also elsewhere on the board
/Primary MCU/RMII.TX_D1: U1501.P11 (MII4_RXD1); also elsewhere on the board
/Primary MCU/RMII.TX_EN: U1501.N12 (MII4_RX_DV/CRS_DV/RX_CTL); also elsewhere on the board
/Primary MCU/RMII_REF_CLK: U1501.N9 (MII4_TX_CLK/REF_CLK/TXC); also elsewhere on the board
/Primary MCU/SWCH.CLK: U1501.P5 (SCK); also elsewhere on the board
/Primary MCU/SWCH.MISO: U1501.P4 (SDO); also elsewhere on the board
/Primary MCU/SWCH.MOSI: U1501.N5 (SDI); also elsewhere on the board
/Primary MCU/SWCH_CS0: R1502.1, U1501.N6 (SS_N); also elsewhere on the board
/Primary MCU/~SWCH_RST: R1505.1, TP1502.1 (1_1), U1501.P3 (RST_N); also elsewhere on the board
/Switch 0/CLK_IN: R1501.2; also elsewhere on the board
/Switch 0/CLK_IN_1V2: C1535.1, R1501.1, R1504.2
/Switch 0/OSC_IN: C1535.2, U1501.K2 (OSC_IN)
/Switch 0/PTP_CLK: U1501.N4 (PTP_CLK); also elsewhere on the board
/Switch 0/R_{CLK_OUT}: R1503.2, U1501.H1 (CLK_OUT)
/Switch 0/xMII0.RX_CLK: U1501.E2 (MII0_RX_CLK/RXC); also elsewhere on the board
/Switch 0/xMII0.RX_CTL: U1501.G1 (MII0_RX_DV/CRS_DV/RX_CTL); also elsewhere on the board
/Switch 0/xMII0.RX_D0: U1501.E1 (MII0_RXD0); also elsewhere on the board
/Switch 0/xMII0.RX_D1: U1501.F2 (MII0_RXD1); also elsewhere on the board
/Switch 0/xMII0.RX_D2: U1501.F1 (MII0_RXD2); also elsewhere on the board
/Switch 0/xMII0.RX_D3: U1501.G2 (MII0_RXD3); also elsewhere on the board
/Switch 0/xMII0.TX_CLK: U1501.D1 (MII0_TX_CLK/REF_CLK/TXC); also elsewhere on the board
/Switch 0/xMII0.TX_CTL: U1501.D2 (MII0_TX_EN/TX_CTL); also elsewhere on the board
/Switch 0/xMII0.TX_D0: U1501.A2 (MII0_TXD0); also elsewhere on the board
/Switch 0/xMII0.TX_D1: U1501.B1 (MII0_TXD1); also elsewhere on the board
/Switch 0/xMII0.TX_D2: U1501.C2 (MII0_TXD2); also elsewhere on the board
/Switch 0/xMII0.TX_D3: U1501.C1 (MII0_TXD3); also elsewhere on the board
GND1: C1501.2, C1502.2, C1503.2, C1504.2, C1505.2, C1506.2, C1507.2, C1508.2, C1509.2, C1510.2, C1511.2, C1512.2, C1513.2, C1514.2, C1515.2, C1516.2, C1517.2, C1518.2, C1519.2, C1520.2, C1521.2, C1522.2, C1523.2, C1524.2, C1525.2, C1526.2, C1527.2, C1528.2, C1529.2, C1530.2, C1531.2, C1532.2, C1533.2, C1534.2, R1504.1, TP1501.1 (1_1), U1501.A1 (VSS_1), U1501.A14 (VSS_2), U1501.B3 (MII1_RX_ER), U1501.B10 (MII2_RX_ER), U1501.B13 (VSS_3), U1501.E5 (VSS_4), U1501.E6 (VSS_5), U1501.E7 (VSS_6), U1501.E8 (VSS_7), U1501.E9 (VSS_8), U1501.E10 (VSS_9), U1501.F5 (VSS_10), U1501.F6 (VSS_11), U1501.F7 (VSS_12), U1501.F8 (VSS_13), U1501.F9 (VSS_14), U1501.F10 (VSS_15), U1501.G5 (VSS_16), U1501.G6 (VSS_17), U1501.G7 (VSS_18), U1501.G8 (VSS_19), U1501.G9 (VSS_20), U1501.G10 (VSS_21), U1501.G13 (MII3_RXD3), U1501.H2 (MII0_RX_ER), U1501.H5 (VSS_22), U1501.H6 (VSS_23), U1501.H7 (VSS_24), U1501.H8 (VSS_25), U1501.H9 (VSS_26), U1501.H10 (VSS_27), U1501.H14 (MII3_RXD2), U1501.J2 (VSSA_PLL), U1501.J5 (VSS_28), U1501.J6 (VSS_29), U1501.J7 (VSS_30), U1501.J8 (VSS_31), U1501.J9 (VSS_32), U1501.J10 (VSS_33), U1501.J13 (MII3_RX_CLK/RXC), U1501.K4 (VSS_34), U1501.K5 (VSS_35), U1501.K6 (VSS_36), U1501.K7 (VSS_37), U1501.K8 (VSS_38), U1501.K9 (VSS_39), U1501.K10 (VSS_40), U1501.L2 (VSSA_OSC), U1501.L4 (I.C.), U1501.L7 (VSS_41), U1501.N2 (VSS_42), U1501.N11 (MII4_RXD2), U1501.N13 (VSS_43), U1501.P1 (VSS_44), U1501.P10 (MII4_RX_CLK/RXC), U1501.P12 (MII4_RXD3), U1501.P13 (MII4_RX_ER), U1501.P14 (VSS_45); also elsewhere on the board

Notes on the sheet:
To 1000BASE-T1 PHY 4
To 1000BASE-T1 PHY 5
VDDIO_MII3: 16mA Max
VDDIO_CLO: 2.2mA Max
VDDIO_MII2: 46mA Max
VDDIO_HOST: 2.1mA Max
VDDA_OSC: 0.35mA Typ
VDDIO_MII0: 46mA Max
To 10BASE-T1S PHY 6
VDDA_PLL: 1.2mA Max
VDDIO_CORE: 200mA Max
Place R_{CLK_OUT} close to pin
To switch 1
VDDIO_MII4: 16mA Max
To primary MCU
VDDIO_MII1: 46mA Max

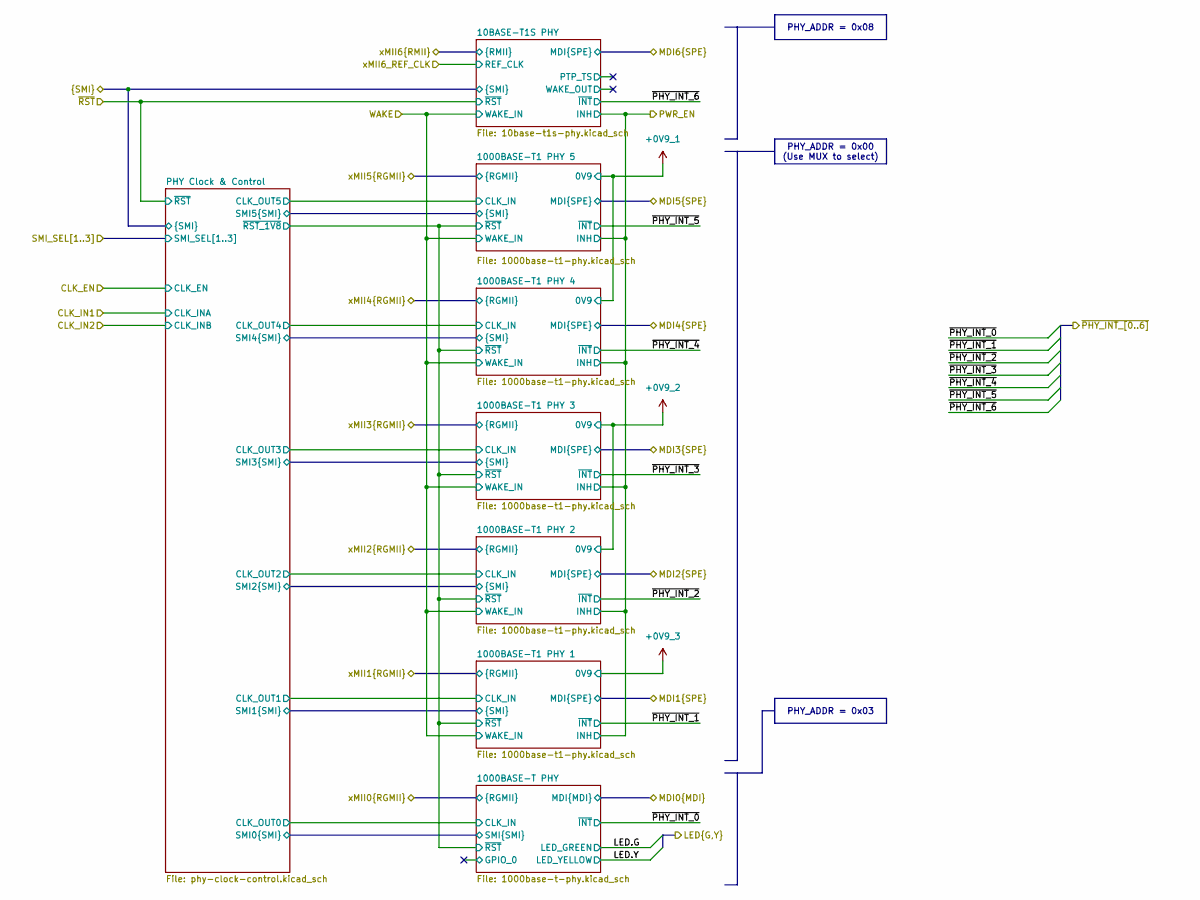
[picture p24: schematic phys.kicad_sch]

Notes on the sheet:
PHY_ADDR = 0x03
PHY_ADDR = 0x00 (Use MUX to select)
PHY_ADDR = 0x08

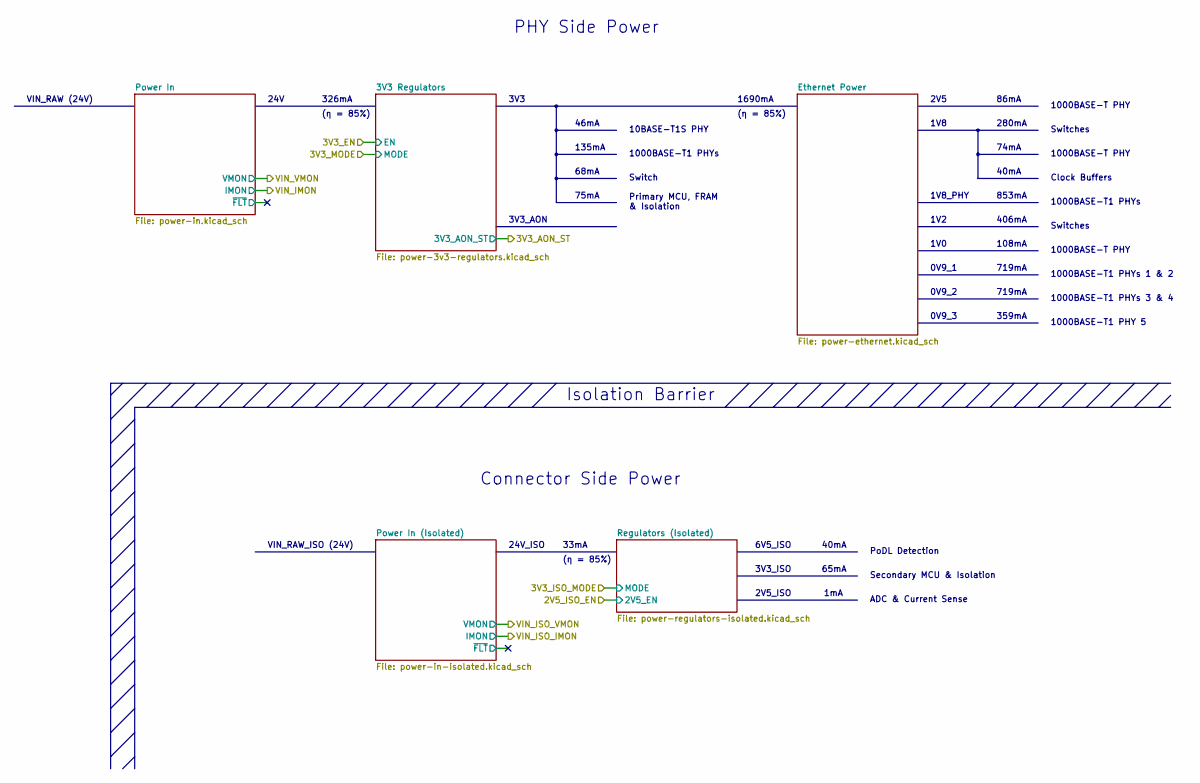
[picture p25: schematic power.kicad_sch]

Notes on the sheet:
1V2
Primary MCU, FRAM & Isolation
VIN_RAW_ISO (24V)
68mA
135mA
VIN_RAW (24V)
719mA
1V0
(η = 85%)
2V5
Clock Buffers
Switch
40mA
1V8
0V9_2
1000BASE-T PHY
10BASE-T1S PHY
3V3
853mA
280mA
24V_ISO
33mA
74mA
1mA
46mA
1000BASE-T1 PHYs
1000BASE-T1 PHYs 1 & 2
24V
Switches
1690mA
PHY Side Power
326mA
1V8_PHY
1000BASE-T1 PHY 5
6V5_ISO
359mA
Isolation Barrier
PoDL Detection
2V5_ISO
Connector Side Power

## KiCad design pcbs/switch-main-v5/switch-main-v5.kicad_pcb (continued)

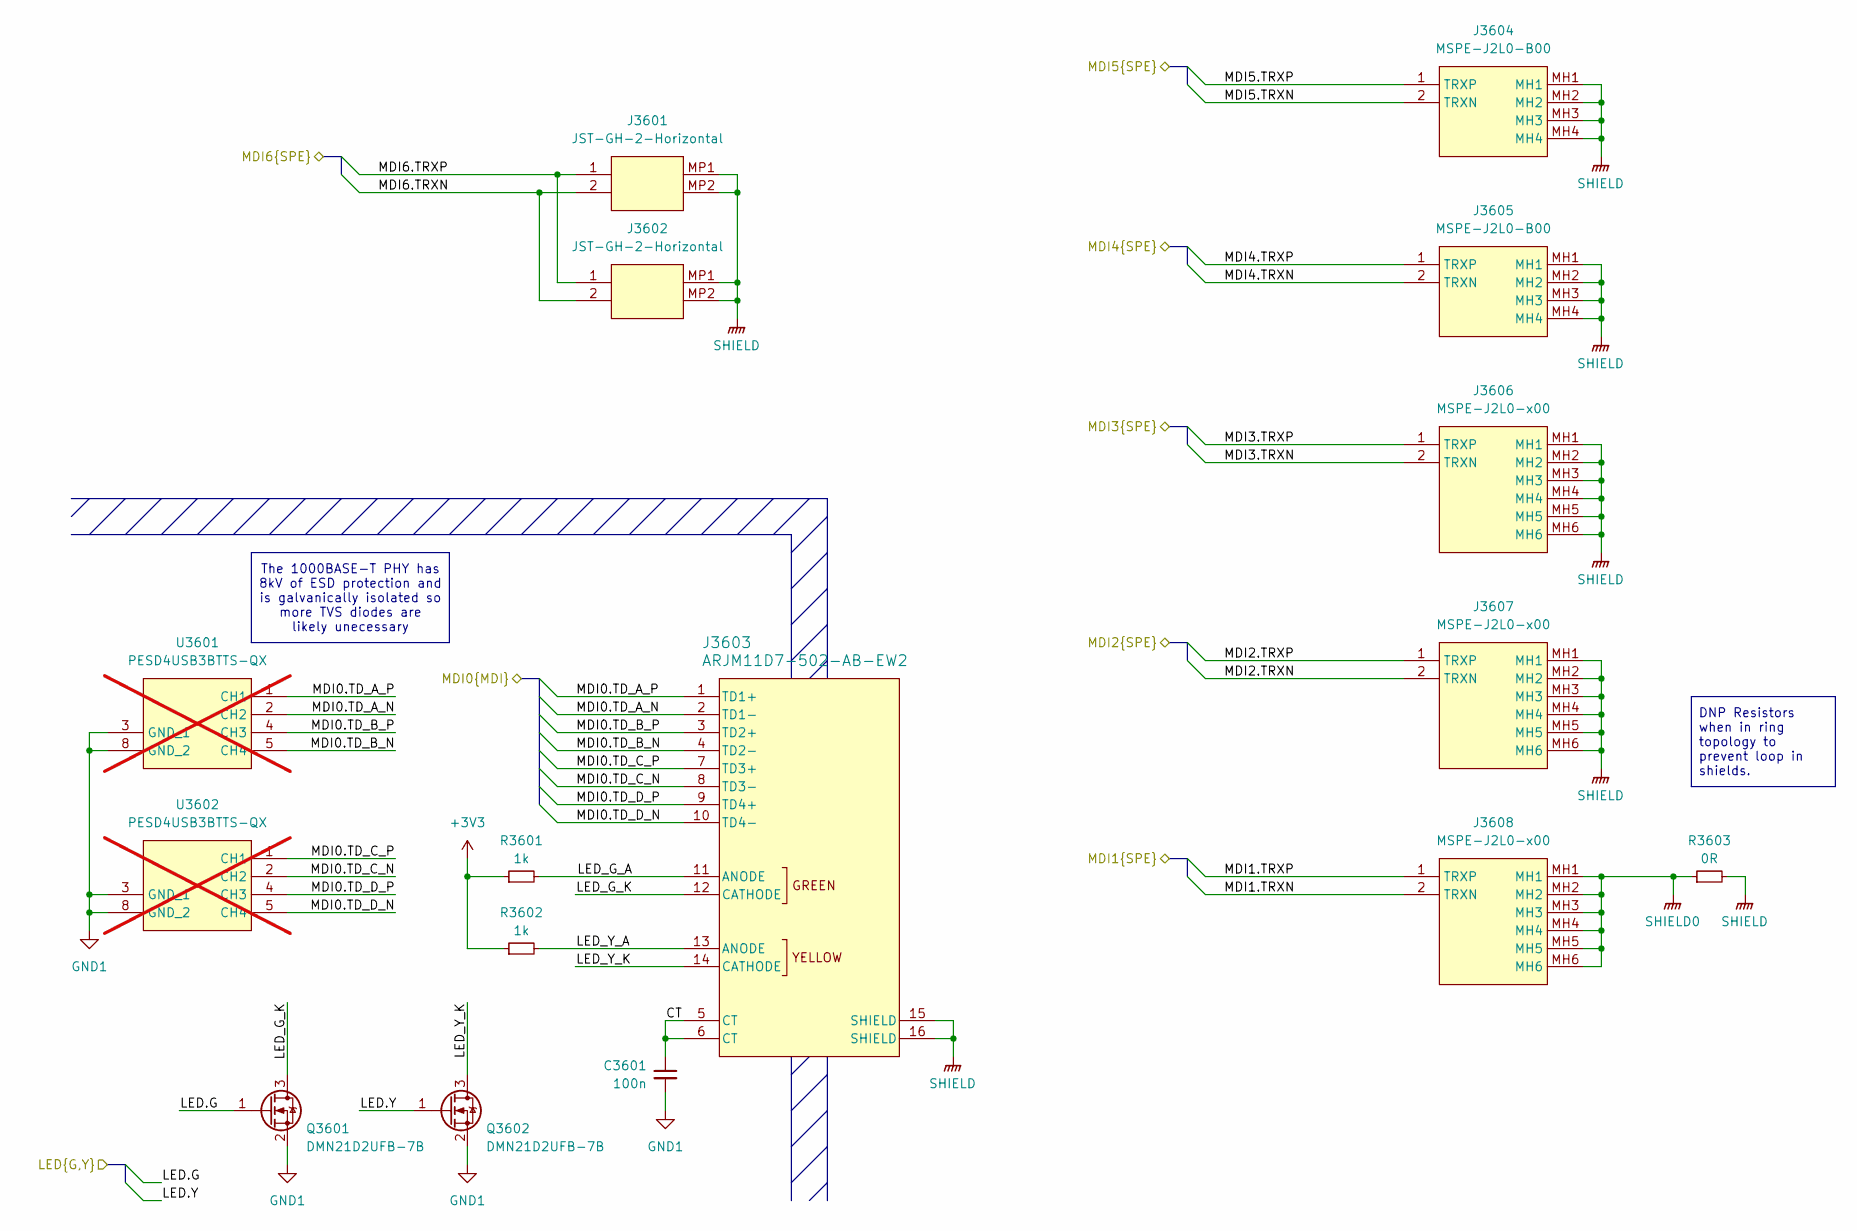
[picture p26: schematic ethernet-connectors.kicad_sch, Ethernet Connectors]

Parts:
C3601: 100n; C_0402
J3601, J3602: JST-GH-2-Horizontal; JST_GH_SM02B-GHS-TB_1x02-1MP_P1.25mm_Horizontal
J3603: ARJM11D7-502-AB-EW2; ARJM11D7-502-AB-EW2_ABR
J3604, J3605: MSPE-J2L0-B00; MSPEJ2L0B00; Mouser Part Number 523-MSPE-J2L0-B00
J3606, J3607, J3608: MSPE-J2L0-x00; MSPEJ2L0x00; Mouser Part Number 523-MSPE-J2L0-B00
Q3601, Q3602: DMN21D2UFB-7B; DMN21D2UFB7B; Mouser Part Number 621-DMN21D2UFB-7B
R3601, R3602: 1k; R_0402
R3603: 0R; R_0402
U3601, U3602: PESD4USB3BTTS-QX; PESD4USB3BTTSQX; Mouser Part Number 771-PESD4USB3BTTS-QX; not fitted

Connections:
+3V3: R3601.1, R3602.1; also elsewhere on the board
/CDNs & PoDL/MDI4_OUT.TRXN: J3605.2 (TRXN); also elsewhere on the board
/CDNs & PoDL/MDI4_OUT.TRXP: J3605.1 (TRXP); also elsewhere on the board
/CDNs & PoDL/MDI5_OUT.TRXN: J3604.2 (TRXN); also elsewhere on the board
/CDNs & PoDL/MDI5_OUT.TRXP: J3604.1 (TRXP); also elsewhere on the board
/CDNs & PoDL/MDI6_OUT.TRXN: J3601.2, J3602.2; also elsewhere on the board
/CDNs & PoDL/MDI6_OUT.TRXP: J3601.1, J3602.1; also elsewhere on the board
/CDNs/MDI1_OUT.TRXN: J3608.2 (TRXN); also elsewhere on the board
/CDNs/MDI1_OUT.TRXP: J3608.1 (TRXP); also elsewhere on the board
/CDNs/MDI2_OUT.TRXN: J3607.2 (TRXN); also elsewhere on the board
/CDNs/MDI2_OUT.TRXP: J3607.1 (TRXP); also elsewhere on the board
/CDNs/MDI3_OUT.TRXN: J3606.2 (TRXN); also elsewhere on the board
/CDNs/MDI3_OUT.TRXP: J3606.1 (TRXP); also elsewhere on the board
/Ethernet Connectors/CT: C3601.1, J3603.5 (CT), J3603.6 (CT)
/Ethernet Connectors/LED.G: Q3601.1 (G); also elsewhere on the board
/Ethernet Connectors/LED.Y: Q3602.1 (G); also elsewhere on the board
/Ethernet Connectors/LED_G_A: J3603.11 (ANODE), R3601.2
/Ethernet Connectors/LED_G_K: J3603.12 (CATHODE), Q3601.3 (D)
/Ethernet Connectors/LED_Y_A: J3603.13 (ANODE), R3602.2
/Ethernet Connectors/LED_Y_K: J3603.14 (CATHODE), Q3602.3 (D)
/Ethernet Connectors/MDI0.TD_A_N: J3603.2 (TD1-), U3601.2 (CH2), U3601.9 (NC); also elsewhere on the board
/Ethernet Connectors/MDI0.TD_A_P: J3603.1 (TD1+), U3601.1 (CH1), U3601.10 (NC); also elsewhere on the board
/Ethernet Connectors/MDI0.TD_B_N: J3603.4 (TD2-), U3601.5 (CH4), U3601.6 (NC); also elsewhere on the board
/Ethernet Connectors/MDI0.TD_B_P: J3603.3 (TD2+), U3601.4 (CH3), U3601.7 (NC); also elsewhere on the board
/Ethernet Connectors/MDI0.TD_C_N: J3603.8 (TD3-), U3602.2 (CH2), U3602.9 (NC); also elsewhere on the board
/Ethernet Connectors/MDI0.TD_C_P: J3603.7 (TD3+), U3602.1 (CH1), U3602.10 (NC); also elsewhere on the board
/Ethernet Connectors/MDI0.TD_D_N: J3603.10 (TD4-), U3602.5 (CH4), U3602.6 (NC); also elsewhere on the board
/Ethernet Connectors/MDI0.TD_D_P: J3603.9 (TD4+), U3602.4 (CH3), U3602.7 (NC); also elsewhere on the board
GND1: C3601.2, Q3601.2 (S), Q3602.2 (S), U3601.3 (GND_1), U3601.8 (GND_2), U3602.3 (GND_1), U3602.8 (GND_2); also elsewhere on the board
SHIELD: J3601.MP1, J3601.MP2, J3602.MP1, J3602.MP2, J3603.15 (SHIELD), J3603.16 (SHIELD), J3604.MH1, J3604.MH2, J3604.MH3, J3604.MH4, J3605.MH1, J3605.MH2, J3605.MH3, J3605.MH4, J3606.MH1, J3606.MH2, J3606.MH3, J3606.MH4, J3606.MH5, J3606.MH6, J3607.MH1, J3607.MH2, J3607.MH3, J3607.MH4, J3607.MH5, J3607.MH6, R3603.2; also elsewhere on the board
SHIELD0: J3608.MH1, J3608.MH2, J3608.MH3, J3608.MH4, J3608.MH5, J3608.MH6, R3603.1; also elsewhere on the board

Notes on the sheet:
The 1000BASE-T PHY has 8kV of ESD protection and is galvanically isolated so more TVS diodes are likely unecessary
DNP Resistors when in ring topology to prevent loop in shields.

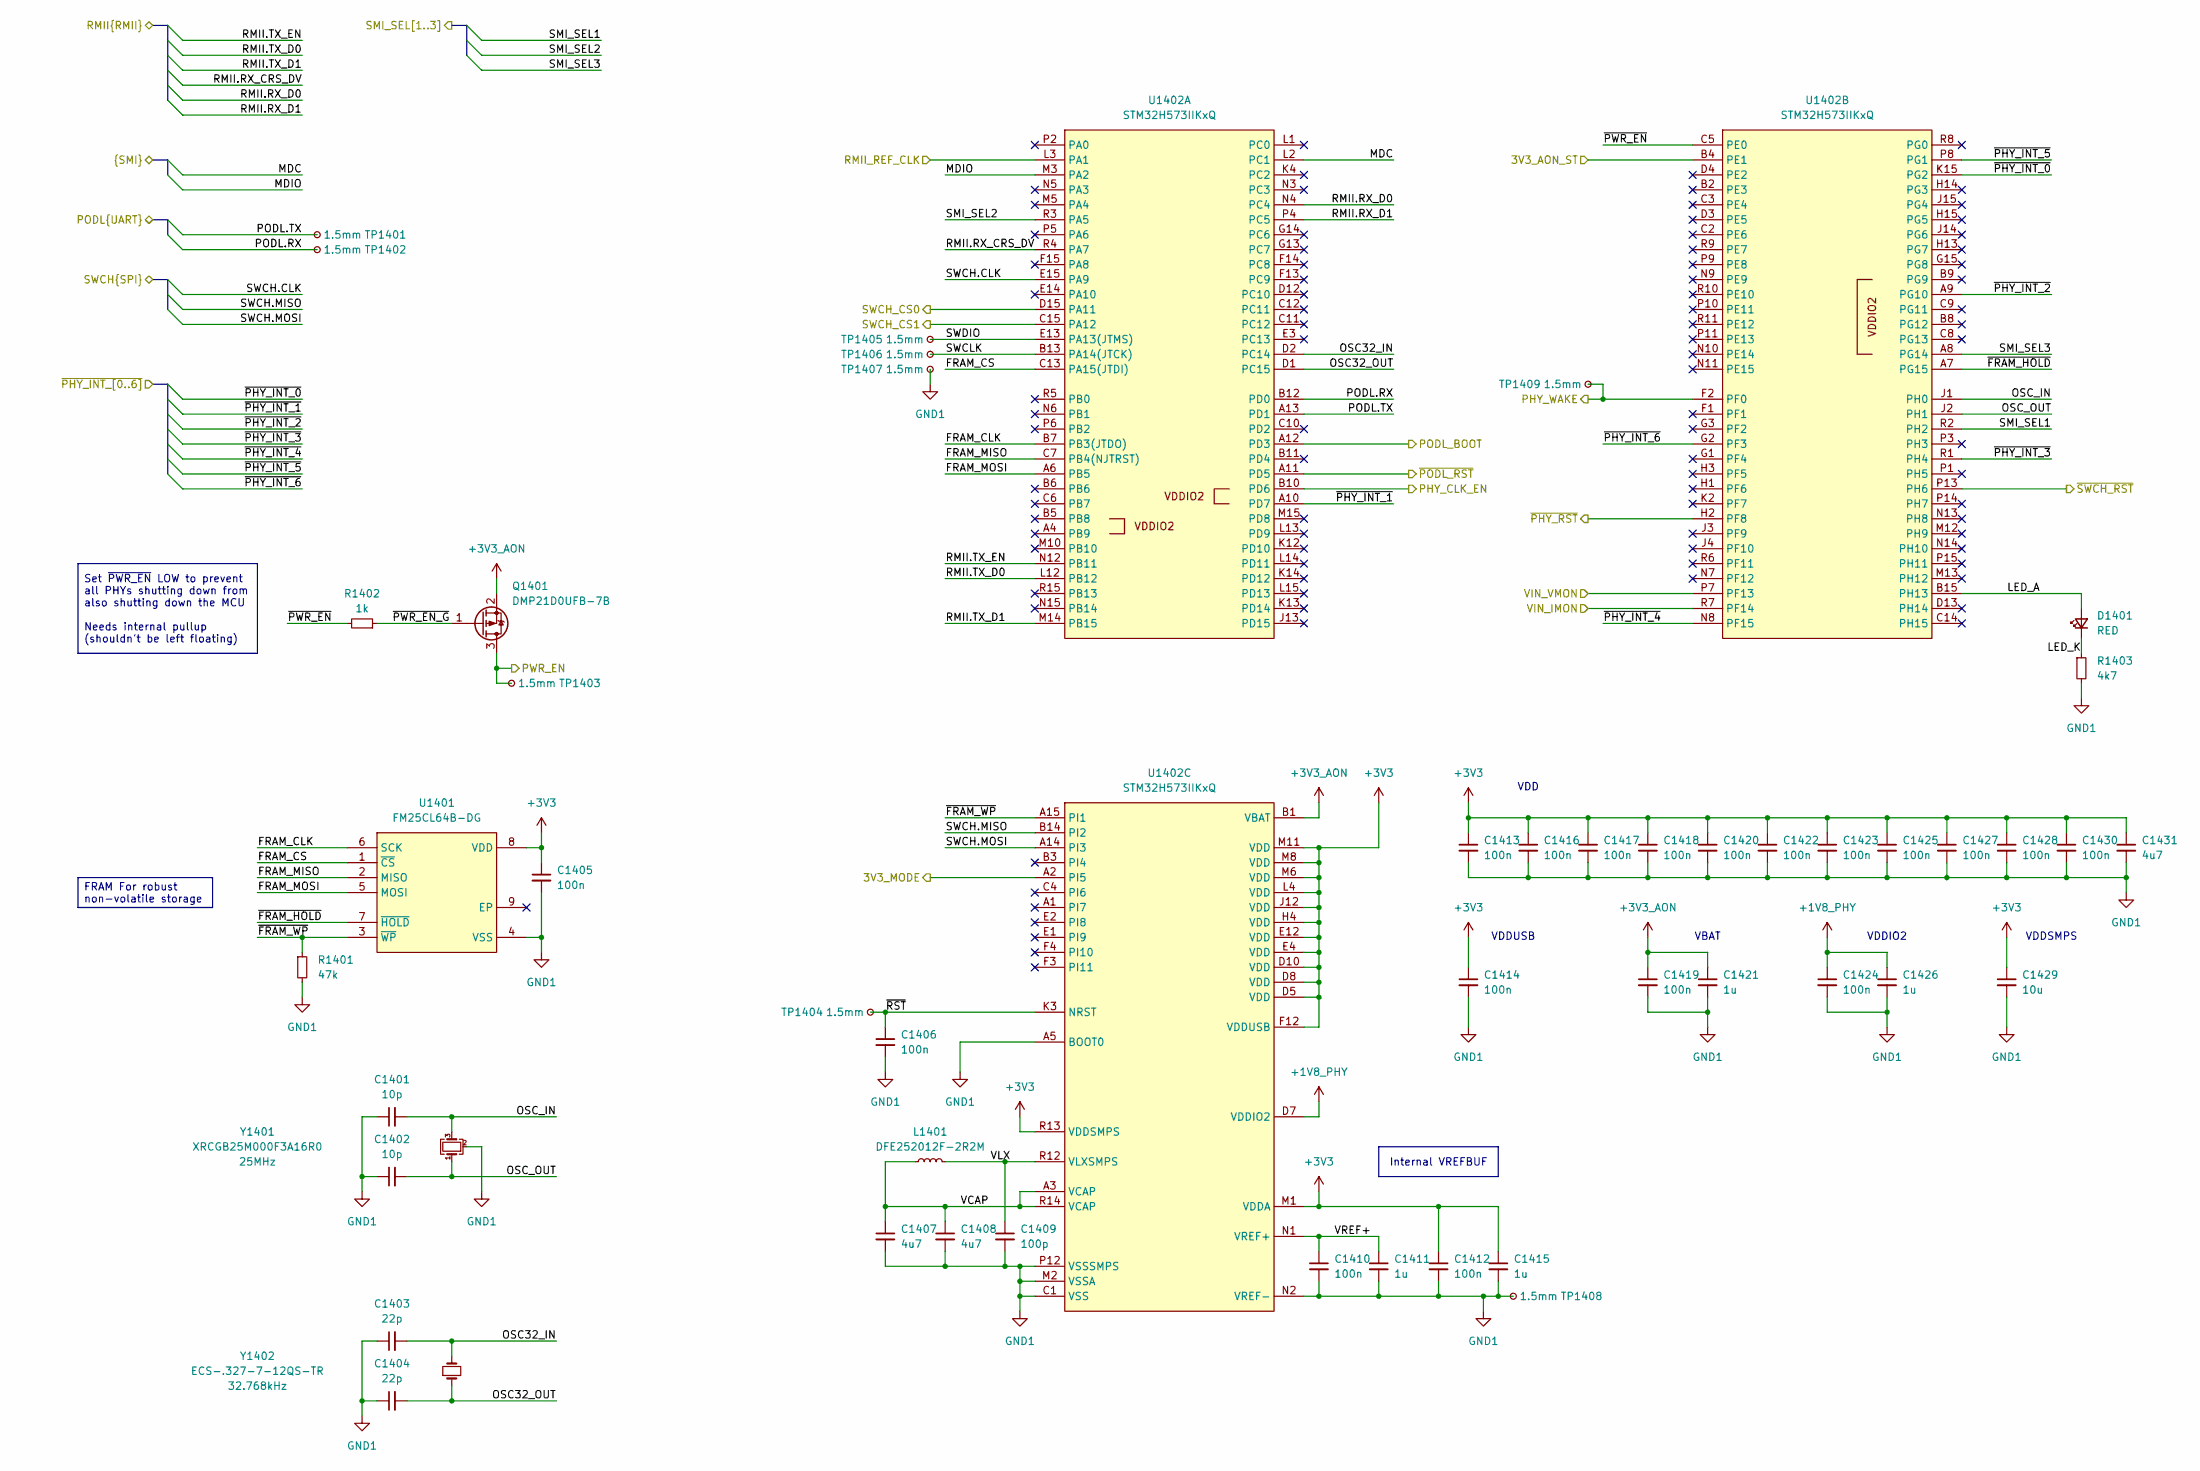
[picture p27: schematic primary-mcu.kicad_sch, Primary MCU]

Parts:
C1401, C1402: 10p; C_0402
C1403, C1404: 22p; C_0402
C1405, C1406, C1410, C1412, C1413, C1414, C1416, C1417, C1418, C1419, C1420, C1422, C1423, C1424, C1425, C1427, C1428, C1430: 100n; C_0402
C1407, C1408, C1431: 4u7; C_0402
C1409: 100p; C_0402
C1411, C1415, C1421, C1426: 1u; C_0402
C1429: 10u; C_0402
D1401: RED; LED_0402_1005Metric
L1401: DFE252012F-2R2M; L_1008_2520Metric
Q1401: DMP21D0UFB-7B; DMP21D0UFB7B; Mouser Part Number 621-DMP21D0UFB-7B
R1401: 47k; R_0402
R1402: 1k; R_0402
R1403: 4k7; R_0402
TP1401, TP1402, TP1403, TP1404, TP1405, TP1406, TP1407, TP1408, TP1409: 1.5mm; TestPoint_Pad_D1.5mm
U1401: FM25CL64B-DG; SON95P400X450X80-9N; Mouser Part Number 877-FM25CL64B-DG
U1402: STM32H573IIKxQ; UFBGA-201_10x10mm_Layout15x15_P0.65mm
Y1401: XRCGB25M000F3A16R0
Y1402: ECS-.327-7-12QS-TR

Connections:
+1V8_PHY: C1424.1, C1426.1, U1402.D7 (VDDIO2); also elsewhere on the board
+3V3: C1405.1, C1412.1, C1413.1, C1414.1, C1415.1, C1416.1, C1417.1, C1418.1, C1420.1, C1422.1, C1423.1, C1425.1, C1427.1, C1428.1, C1429.1, C1430.1, C1431.1, U1401.8 (VDD), U1402.D5 (VDD), U1402.D8 (VDD), U1402.D10 (VDD), U1402.E4 (VDD), U1402.E12 (VDD), U1402.F12 (VDDUSB), U1402.H4 (VDD), U1402.J12 (VDD), U1402.L4 (VDD), U1402.M1 (VDDA), U1402.M6 (VDD), U1402.M8 (VDD), U1402.M11 (VDD), U1402.R13 (VDDSMPS); also elsewhere on the board
+3V3_AON: C1419.1, C1421.1, Q1401.2 (S), U1402.B1 (VBAT); also elsewhere on the board
/Isolation Crossing/IN_C: U1402.A12 (PD3); also elsewhere on the board
/Isolation Crossing/IN_D: U1402.A11 (PD5); also elsewhere on the board
/PHYs/CLK_EN: U1402.B10 (PD6); also elsewhere on the board
/PHYs/MDC: U1402.L2 (PC1); also elsewhere on the board
/PHYs/MDIO: U1402.M3 (PA2); also elsewhere on the board
/PHYs/PWR_EN: Q1401.3 (D), TP1403.1 (1_1); also elsewhere on the board
/PHYs/SMI_SEL1: U1402.R2 (PH2); also elsewhere on the board
/PHYs/SMI_SEL2: U1402.R3 (PA5); also elsewhere on the board
/PHYs/SMI_SEL3: U1402.A8 (PG14); also elsewhere on the board
/PHYs/WAKE: TP1409.1 (1_1), U1402.F2 (PF0); also elsewhere on the board
/PHYs/~PHY_INT_0: U1402.K15 (PG2); also elsewhere on the board
/PHYs/~PHY_INT_1: U1402.A10 (PD7); also elsewhere on the board
/PHYs/~PHY_INT_2: U1402.A9 (PG10); also elsewhere on the board
/PHYs/~PHY_INT_3: U1402.R1 (PH4); also elsewhere on the board
/PHYs/~PHY_INT_4: U1402.N8 (PF15); also elsewhere on the board
/PHYs/~PHY_INT_5: U1402.P8 (PG1); also elsewhere on the board
/PHYs/~PHY_INT_6: U1402.G2 (PF3); also elsewhere on the board
/PHYs/~RST: U1402.H2 (PF8); also elsewhere on the board
/Power/3V3_AON_ST: U1402.B4 (PE1); also elsewhere on the board
/Power/3V3_MODE: U1402.A2 (PI5); also elsewhere on the board
/Power/VIN_IMON: U1402.R7 (PF14); also elsewhere on the board
/Power/VIN_VMON: U1402.P7 (PF13); also elsewhere on the board
/Primary MCU/FRAM_CLK: U1401.6 (SCK), U1402.B7 (PB3(JTDO))
/Primary MCU/FRAM_CS: U1401.1 (~CS), U1402.C13 (PA15(JTDI))
/Primary MCU/FRAM_MISO: U1401.2 (MISO), U1402.C7 (PB4(NJTRST))
/Primary MCU/FRAM_MOSI: U1401.5 (MOSI), U1402.A6 (PB5)
/Primary MCU/LED_A: D1401.2 (A), U1402.B15 (PH13)
/Primary MCU/LED_K: D1401.1 (K), R1403.1
/Primary MCU/OSC32_IN: C1403.2, U1402.D2 (PC14), Y1402.2
/Primary MCU/OSC32_OUT: C1404.2, U1402.D1 (PC15), Y1402.1
/Primary MCU/OSC_IN: C1401.2, U1402.J1 (PH0), Y1401.3
/Primary MCU/OSC_OUT: C1402.2, U1402.J2 (PH1), Y1401.1
/Primary MCU/PODL.RX: TP1402.1 (1_1), U1402.B12 (PD0); also elsewhere on the board
/Primary MCU/PODL.TX: TP1401.1 (1_1), U1402.A13 (PD1); also elsewhere on the board
/Primary MCU/RMII.RX_CRS_DV: U1402.R4 (PA7); also elsewhere on the board
/Primary MCU/RMII.RX_D0: U1402.N4 (PC4); also elsewhere on the board
/Primary MCU/RMII.RX_D1: U1402.P4 (PC5); also elsewhere on the board
/Primary MCU/RMII.TX_D0: U1402.L12 (PB12); also elsewhere on the board
/Primary MCU/RMII.TX_D1: U1402.M14 (PB15); also elsewhere on the board
/Primary MCU/RMII.TX_EN: U1402.N12 (PB11); also elsewhere on the board
/Primary MCU/RMII_REF_CLK: U1402.L3 (PA1); also elsewhere on the board
/Primary MCU/SWCH.CLK: U1402.E15 (PA9); also elsewhere on the board
/Primary MCU/SWCH.MISO: U1402.B14 (PI2); also elsewhere on the board
/Primary MCU/SWCH.MOSI: U1402.A14 (PI3); also elsewhere on the board
/Primary MCU/SWCH_CS0: U1402.D15 (PA11); also elsewhere on the board
/Primary MCU/SWCH_CS1: U1402.C15 (PA12); also elsewhere on the board
/Primary MCU/SWCLK: TP1406.1 (1_1), U1402.B13 (PA14(JTCK))
/Primary MCU/SWDIO: TP1405.1 (1_1), U1402.E13 (PA13(JTMS))
/Primary MCU/VCAP: C1407.1, C1408.1, L1401.2, U1402.A3 (VCAP), U1402.R14 (VCAP)
/Primary MCU/VLX: C1409.1, L1401.1, U1402.R12 (VLXSMPS)
/Primary MCU/VREF+: C1410.1, C1411.1, U1402.N1 (VREF+)
/Primary MCU/~FRAM_HOLD: U1401.7 (~HOLD), U1402.A7 (PG15)
/Primary MCU/~FRAM_WP: R1401.1, U1401.3 (~WP), U1402.A15 (PI1)
/Primary MCU/~PWR_EN_G: Q1401.1 (G), R1402.1
/Primary MCU/~PWR_EN: R1402.2, U1402.C5 (PE0)
/Primary MCU/~RST: C1406.1, TP1404.1 (1_1), U1402.K3 (NRST)
/Primary MCU/~SWCH_RST: U1402.P13 (PH6); also elsewhere on the board
GND1: C1401.1, C1402.1, C1403.1, C1404.1, C1405.2, C1406.2, C1407.2, C1408.2, C1409.2, C1410.2, C1411.2, C1412.2, C1413.2, C1414.2, C1415.2, C1416.2, C1417.2, C1418.2, C1419.2, C1420.2, C1421.2, C1422.2, C1423.2, C1424.2, C1425.2, C1426.2, C1427.2, C1428.2, C1429.2, C1430.2, C1431.2, R1401.2, R1403.2, TP1407.1 (1_1), TP1408.1 (1_1), U1401.4 (VSS), U1402.A5 (BOOT0), U1402.C1 (VSS), U1402.D6 (VSS), U1402.D9 (VSS), U1402.D11 (VSS), U1402.D14 (VSS), U1402.F6 (VSS), U1402.F7 (VSS), U1402.F8 (VSS), U1402.F9 (VSS), U1402.F10 (VSS), U1402.G4 (VSS), U1402.G6 (VSS), U1402.G7 (VSS), U1402.G8 (VSS), U1402.G9 (VSS), U1402.G10 (VSS), U1402.G12 (VSS), U1402.H6 (VSS), U1402.H7 (VSS), U1402.H8 (VSS), U1402.H9 (VSS), U1402.H10 (VSS), U1402.H12 (VSS), U1402.J6 (VSS), U1402.J7 (VSS), U1402.J8 (VSS), U1402.J9 (VSS), U1402.J10 (VSS), U1402.K1 (VSS), U1402.K6 (VSS), U1402.K7 (VSS), U1402.K8 (VSS), U1402.K9 (VSS), U1402.K10 (VSS), U1402.M2 (VSSA), U1402.M4 (VSS), U1402.M7 (VSS), U1402.M9 (VSS), U1402.N2 (VREF-), U1402.P12 (VSSSMPS), Y1401.2 (G), Y1401.4 (G); also elsewhere on the board

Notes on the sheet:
VBAT
VDDSMPS
VDDIO2
VDDUSB
VDD
FRAM For robust non-volatile storage
Internal VREFBUF
Set ~{PWR_EN} LOW to prevent all PHYs shutting down from also shutting down the MCU Needs internal pullup (shouldn't be left floating)

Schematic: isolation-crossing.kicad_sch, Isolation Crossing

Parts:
C3701, C3702, C3703, C3704: 100n; C_0402
U3701: ISO6521REUR; SON50P300X200X105-8N-D; Mouser Part Number 595-ISO6521REUR
U3702: ISO6520REUR; SON50P300X200X105-8N-D

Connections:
+3V3: C3701.1, C3702.1, U3701.1 (VCC1), U3702.1 (VCC1); also elsewhere on the board
+3V3_ISO: C3703.1, C3704.1, U3701.8 (VCC2), U3702.8 (VCC2); also elsewhere on the board
/Isolation Crossing/IN_C: U3702.2 (INA); also elsewhere on the board
/Isolation Crossing/IN_D: U3702.3 (INB); also elsewhere on the board
/Isolation Crossing/OUT_C: U3702.7 (OUTA); also elsewhere on the board
/Isolation Crossing/OUT_D: U3702.6 (OUTB); also elsewhere on the board
/Primary MCU/PODL.RX: U3701.2 (OUTA); also elsewhere on the board
/Primary MCU/PODL.TX: U3701.3 (INB); also elsewhere on the board
/Secondary MCU/RX: U3701.6 (OUTB); also elsewhere on the board
/Secondary MCU/TX: U3701.7 (INA); also elsewhere on the board
GND1: C3701.2, C3702.2, U3701.4 (GND1), U3702.4 (GND1); also elsewhere on the board
GND2: C3703.2, C3704.2, U3701.5 (GND2), U3702.5 (GND2); also elsewhere on the board

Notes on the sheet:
Channels C & D are default HIGH output Secondary MCU will run automatically (BOOT is inverted later)
Channels A & B are default HIGH output Prevents accidental UART transmission

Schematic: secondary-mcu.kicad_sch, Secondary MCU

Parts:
C3801, C3802, C3803, C3804: 100n; C_0402
C3805, C3806, C3807: 4u7; C_0402
Q3801, Q3802: DMN21D2UFB-7B; DMN21D2UFB7B; Mouser Part Number 621-DMN21D2UFB-7B
R3801: 47k; R_0402
R3802, R3803: 4k7; R_0402
TP3801, TP3802, TP3803, TP3804, TP3805: 1.5mm; TestPoint_Pad_D1.5mm
U3801: STM32H503KBUx; QFN-32-1EP_5x5mm_P0.5mm_EP3.45x3.45mm

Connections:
+2V5_ISO: C3803.1, C3805.1, U3801.5 (VDDA); also elsewhere on the board
+3V3_ISO: C3802.1, C3804.1, C3806.1, Q3802.1 (G), R3801.2, R3802.2, U3801.1 (VDD), U3801.17 (VDD); also elsewhere on the board
/CDNs & PoDL/PODL1.DET_EN: U3801.20 (PA9); also elsewhere on the board
/CDNs & PoDL/PODL1.DET_V+: U3801.10 (PA4); also elsewhere on the board
/CDNs & PoDL/PODL1.EN: U3801.19 (PA8); also elsewhere on the board
/CDNs & PoDL/PODL1.IMON: U3801.9 (PA3); also elsewhere on the board
/CDNs & PoDL/PODL2.DET_EN: U3801.2 (PC14); also elsewhere on the board
/CDNs & PoDL/PODL2.DET_V+: U3801.15 (PB1); also elsewhere on the board
/CDNs & PoDL/PODL2.EN: U3801.22 (PA12); also elsewhere on the board
/CDNs & PoDL/PODL2.IMON: U3801.12 (PA6); also elsewhere on the board
/CDNs & PoDL/PODL3.DET_EN: U3801.29 (PB6); also elsewhere on the board
/CDNs & PoDL/PODL3.DET_V+: U3801.14 (PB0); also elsewhere on the board
/CDNs & PoDL/PODL3.EN: U3801.30 (PB7); also elsewhere on the board
/CDNs & PoDL/PODL3.IMON: U3801.13 (PA7); also elsewhere on the board
/CDNs & PoDL/PODL_DIAG_EN: U3801.21 (PA11); also elsewhere on the board
/Isolation Crossing/OUT_C: Q3801.1 (G); also elsewhere on the board
/Isolation Crossing/OUT_D: Q3802.3 (D); also elsewhere on the board
/Power/2V5_ISO_EN: U3801.7 (PA1); also elsewhere on the board
/Power/3V3_ISO_MODE: U3801.28 (PB5); also elsewhere on the board
/Power/VIN_ISO_IMON: U3801.6 (PA0); also elsewhere on the board
/Power/VIN_ISO_VMON: U3801.8 (PA2); also elsewhere on the board
/Secondary MCU/NRST: C3801.1, R3803.1, TP3804.1 (1_1), U3801.4 (NRST)
/Secondary MCU/RX: U3801.25 (PA15(JTDI)); also elsewhere on the board
/Secondary MCU/SWCLK: TP3802.1 (1_1), U3801.24 (PA14(JTCK))
/Secondary MCU/SWDIO: TP3801.1 (1_1), U3801.23 (PA13(JTMS))
/Secondary MCU/TX: U3801.11 (PA5); also elsewhere on the board
/Secondary MCU/VCAP: C3807.1, U3801.16 (VCAP)
/Secondary MCU/~BOOT: Q3801.3 (D), R3801.1, TP3805.1 (1_1), U3801.31 (BOOT0)
/Secondary MCU/~RST_OD: Q3802.2 (S), R3802.1, R3803.2
GND2: C3801.2, C3802.2, C3803.2, C3804.2, C3805.2, C3806.2, C3807.2, Q3801.2 (S), TP3803.1 (1_1), U3801.33 (VSS); also elsewhere on the board

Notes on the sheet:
Invert BOOT so it is LOW by default (flash boot)
Convert ~{RST} from a push-pull signal to an open drain signal (without inversion)

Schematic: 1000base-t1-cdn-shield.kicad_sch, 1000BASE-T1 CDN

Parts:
C3301: 100n; C_0402
C3302: 100n; C_0603; Voltage 100V
C3303: 1n; C_0805; Voltage 1kV
D3301: 824012823; Mouser Part Number 710-824012823
D3302, D3303: SZESD7241N2T5G; SZESD7462N2T5G; Mouser Part Number 863-SZESD7241N2T5G
FL3301: ACT1210G-800-2P-TL10; ACT1210G; Mouser Part Number 810-ACT1210G8002PTL1
R3301: 100R; R_0402
T3301: 74930100

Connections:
/CDNs/1000BASE-T1 CDN 1/CTP: C3301.1, T3301.5 (PM)
/CDNs/1000BASE-T1 CDN 1/CTS1: C3302.2, T3301.4 (OUT1B)
/CDNs/1000BASE-T1 CDN 1/CTS2: C3302.1, R3301.2, T3301.3 (OUT2A)
/CDNs/1000BASE-T1 CDN 1/TERM: C3303.1, R3301.1
/CDNs/1000BASE-T1 CDN 1/TRXN: FL3301.2, T3301.2 (IN-)
/CDNs/1000BASE-T1 CDN 1/TRXP: FL3301.1, T3301.1 (IN+)
/CDNs/MDI1_IN.TRXN: D3301.1, D3301.6, FL3301.3; also elsewhere on the board
/CDNs/MDI1_IN.TRXP: D3301.2, D3301.5, FL3301.4; also elsewhere on the board
/CDNs/MDI1_OUT.TRXN: D3303.2 (A2), T3301.7 (OUT2B); also elsewhere on the board
/CDNs/MDI1_OUT.TRXP: D3302.2 (A2), T3301.6 (OUT1A); also elsewhere on the board
GND1: C3301.2, D3301.3, D3301.4; also elsewhere on the board
SHIELD0: C3303.2, D3302.1 (A1), D3303.1 (A1); also elsewhere on the board

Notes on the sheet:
Termination
ESD Protection
CMC

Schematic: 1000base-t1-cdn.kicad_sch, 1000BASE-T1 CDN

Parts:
C3401: 100n; C_0402
C3402: 100n; C_0603; Voltage 100V
C3403: 1n; C_0805; Voltage 1kV
D3401: 824012823; Mouser Part Number 710-824012823
D3402, D3403: SZESD7241N2T5G; SZESD7462N2T5G; Mouser Part Number 863-SZESD7241N2T5G
FL3401: ACT1210G-800-2P-TL10; ACT1210G; Mouser Part Number 810-ACT1210G8002PTL1
R3401: 100R; R_0402
T3401: 74930100

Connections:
/CDNs/1000BASE-T1 CDN 2/CTP: C3401.1, T3401.5 (PM)
/CDNs/1000BASE-T1 CDN 2/CTS1: C3402.2, T3401.4 (OUT1B)
/CDNs/1000BASE-T1 CDN 2/CTS2: C3402.1, R3401.2, T3401.3 (OUT2A)
/CDNs/1000BASE-T1 CDN 2/TERM: C3403.1, R3401.1
/CDNs/1000BASE-T1 CDN 2/TRXN: FL3401.2, T3401.2 (IN-)
/CDNs/1000BASE-T1 CDN 2/TRXP: FL3401.1, T3401.1 (IN+)
/CDNs/MDI2_IN.TRXN: D3401.1, D3401.6, FL3401.3; also elsewhere on the board
/CDNs/MDI2_IN.TRXP: D3401.2, D3401.5, FL3401.4; also elsewhere on the board
/CDNs/MDI2_OUT.TRXN: D3403.2 (A2), T3401.7 (OUT2B); also elsewhere on the board
/CDNs/MDI2_OUT.TRXP: D3402.2 (A2), T3401.6 (OUT1A); also elsewhere on the board
GND1: C3401.2, D3401.3, D3401.4; also elsewhere on the board
SHIELD: C3403.2, D3402.1 (A1), D3403.1 (A1); also elsewhere on the board

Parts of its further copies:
C3501: 100n; C_0402
C3502: 100n; C_0603; Voltage 100V
C3503: 1n; C_0805; Voltage 1kV
D3501: 824012823; Mouser Part Number 710-824012823
D3502, D3503: SZESD7241N2T5G; SZESD7462N2T5G; Mouser Part Number 863-SZESD7241N2T5G
FL3501: ACT1210G-800-2P-TL10; ACT1210G; Mouser Part Number 810-ACT1210G8002PTL1
R3501: 100R; R_0402
T3501: 74930100

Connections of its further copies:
/CDNs/1000BASE-T1 CDN 3/CTP: C3501.1, T3501.5 (PM)
/CDNs/1000BASE-T1 CDN 3/CTS1: C3502.2, T3501.4 (OUT1B)
/CDNs/1000BASE-T1 CDN 3/CTS2: C3502.1, R3501.2, T3501.3 (OUT2A)
/CDNs/1000BASE-T1 CDN 3/TERM: C3503.1, R3501.1
/CDNs/1000BASE-T1 CDN 3/TRXN: FL3501.2, T3501.2 (IN-)
/CDNs/1000BASE-T1 CDN 3/TRXP: FL3501.1, T3501.1 (IN+)
/CDNs/MDI3_IN.TRXN: D3501.1, D3501.6, FL3501.3; also elsewhere on the board
/CDNs/MDI3_IN.TRXP: D3501.2, D3501.5, FL3501.4; also elsewhere on the board
/CDNs/MDI3_OUT.TRXN: D3503.2 (A2), T3501.7 (OUT2B); also elsewhere on the board
/CDNs/MDI3_OUT.TRXP: D3502.2 (A2), T3501.6 (OUT1A); also elsewhere on the board
GND1: C3501.2, D3501.3, D3501.4; also elsewhere on the board
SHIELD: C3503.2, D3502.1 (A1), D3503.1 (A1); also elsewhere on the board

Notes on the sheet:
Termination
ESD Protection
CMC

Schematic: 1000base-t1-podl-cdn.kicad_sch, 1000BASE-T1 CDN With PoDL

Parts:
C2701: 100n; C_0402
C2702: 100n; C_0603; Voltage 100V
C2703: 1n; C_0805; Voltage 1kV
D2701: 824012823; Mouser Part Number 710-824012823
D2702, D2703: SZESD7241N2T5G; SZESD7462N2T5G; Mouser Part Number 863-SZESD7241N2T5G
FL2701: ACT1210G-800-2P-TL10; ACT1210G; Mouser Part Number 810-ACT1210G8002PTL1
L2701, L2702: ADL3225VT-4R7M-TL000; ADL3225VT4R7MTL000; Mouser Part Number 810-ADL3225VT4R7MTL0
R2701: 100R; R_0402
T2701: 74930100

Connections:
/CDNs & PoDL/1000BASE-T1 PoDL CDN 1/CTP: C2701.1, T2701.5 (PM)
/CDNs & PoDL/1000BASE-T1 PoDL CDN 1/CTS1: C2702.2, T2701.4 (OUT1B)
/CDNs & PoDL/1000BASE-T1 PoDL CDN 1/CTS2: C2702.1, R2701.2, T2701.3 (OUT2A)
/CDNs & PoDL/1000BASE-T1 PoDL CDN 1/PWR+: L2702.3, L2702.4; also elsewhere on the board
/CDNs & PoDL/1000BASE-T1 PoDL CDN 1/TERM: C2703.1, R2701.1
/CDNs & PoDL/1000BASE-T1 PoDL CDN 1/TRXN: FL2701.2, T2701.2 (IN-)
/CDNs & PoDL/1000BASE-T1 PoDL CDN 1/TRXP: FL2701.1, T2701.1 (IN+)
/CDNs & PoDL/MDI4_IN.TRXN: D2701.1, D2701.6, FL2701.3; also elsewhere on the board
/CDNs & PoDL/MDI4_IN.TRXP: D2701.2, D2701.5, FL2701.4; also elsewhere on the board
/CDNs & PoDL/MDI4_OUT.TRXN: D2703.2 (A2), L2701.1, L2701.2, T2701.7 (OUT2B); also elsewhere on the board
/CDNs & PoDL/MDI4_OUT.TRXP: D2702.2 (A2), L2702.1, L2702.2, T2701.6 (OUT1A); also elsewhere on the board
GND1: C2701.2, D2701.3, D2701.4; also elsewhere on the board
GND2: L2701.3, L2701.4; also elsewhere on the board
SHIELD: C2703.2, D2702.1 (A1), D2703.1 (A1); also elsewhere on the board

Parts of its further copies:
C2801: 100n; C_0402
C2802: 100n; C_0603; Voltage 100V
C2803: 1n; C_0805; Voltage 1kV
D2801: 824012823; Mouser Part Number 710-824012823
D2802, D2803: SZESD7241N2T5G; SZESD7462N2T5G; Mouser Part Number 863-SZESD7241N2T5G
FL2801: ACT1210G-800-2P-TL10; ACT1210G; Mouser Part Number 810-ACT1210G8002PTL1
L2801, L2802: ADL3225VT-4R7M-TL000; ADL3225VT4R7MTL000; Mouser Part Number 810-ADL3225VT4R7MTL0
R2801: 100R; R_0402
T2801: 74930100

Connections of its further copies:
/CDNs & PoDL/1000BASE-T1 PoDL CDN 2/CTP: C2801.1, T2801.5 (PM)
/CDNs & PoDL/1000BASE-T1 PoDL CDN 2/CTS1: C2802.2, T2801.4 (OUT1B)
/CDNs & PoDL/1000BASE-T1 PoDL CDN 2/CTS2: C2802.1, R2801.2, T2801.3 (OUT2A)
/CDNs & PoDL/1000BASE-T1 PoDL CDN 2/PWR+: L2802.3, L2802.4; also elsewhere on the board
/CDNs & PoDL/1000BASE-T1 PoDL CDN 2/TERM: C2803.1, R2801.1
/CDNs & PoDL/1000BASE-T1 PoDL CDN 2/TRXN: FL2801.2, T2801.2 (IN-)
/CDNs & PoDL/1000BASE-T1 PoDL CDN 2/TRXP: FL2801.1, T2801.1 (IN+)
/CDNs & PoDL/MDI5_IN.TRXN: D2801.1, D2801.6, FL2801.3; also elsewhere on the board
/CDNs & PoDL/MDI5_IN.TRXP: D2801.2, D2801.5, FL2801.4; also elsewhere on the board
/CDNs & PoDL/MDI5_OUT.TRXN: D2803.2 (A2), L2801.1, L2801.2, T2801.7 (OUT2B); also elsewhere on the board
/CDNs & PoDL/MDI5_OUT.TRXP: D2802.2 (A2), L2802.1, L2802.2, T2801.6 (OUT1A); also elsewhere on the board
GND1: C2801.2, D2801.3, D2801.4; also elsewhere on the board
GND2: L2801.3, L2801.4; also elsewhere on the board
SHIELD: C2803.2, D2802.1 (A1), D2803.1 (A1); also elsewhere on the board

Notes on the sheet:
CMC
2x 100mΩ 720mA Max
Can also use LQH32NH3R3J23L
Termination
ESD Protection

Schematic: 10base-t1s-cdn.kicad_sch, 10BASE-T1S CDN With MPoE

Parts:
C2901: 100n; C_0402
C2902: 100n; C_0603; Voltage 100V
C2903: 1n; C_0805; Voltage 1kV
D2901: 824012823; Mouser Part Number 710-824012823
D2902, D2903: SZESD7241N2T5G; SZESD7462N2T5G; Mouser Part Number 863-SZESD7241N2T5G
FL2901: ACT1210E-131-2P-TL00; ACT1210E; Mouser Part Number 810-ACT1210E1312PTL0
L2901: MSD7342-333MLC_DM; MSD7342
L2902: MSD7342-333MLC; MSD7342
R2901: 3k3; R_0402
T2901: 74930100

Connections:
/CDNs & PoDL/10BASE-T1S CDN/CTP: C2901.1, T2901.5 (PM)
/CDNs & PoDL/10BASE-T1S CDN/CTS1: C2902.2, T2901.4 (OUT1B)
/CDNs & PoDL/10BASE-T1S CDN/CTS2: C2902.1, R2901.2, T2901.3 (OUT2A)
/CDNs & PoDL/10BASE-T1S CDN/MDI_PWR+: L2901.4 (2), L2902.3
/CDNs & PoDL/10BASE-T1S CDN/MDI_PWR-: L2901.1, L2902.4 (2)
/CDNs & PoDL/10BASE-T1S CDN/PWR+: L2902.1; also elsewhere on the board
/CDNs & PoDL/10BASE-T1S CDN/TERM: C2903.1, R2901.1
/CDNs & PoDL/10BASE-T1S CDN/TRXN: FL2901.2, T2901.2 (IN-)
/CDNs & PoDL/10BASE-T1S CDN/TRXP: FL2901.1, T2901.1 (IN+)
/CDNs & PoDL/MDI6_IN.TRXN: D2901.1, D2901.6, FL2901.3; also elsewhere on the board
/CDNs & PoDL/MDI6_IN.TRXP: D2901.2, D2901.5, FL2901.4; also elsewhere on the board
/CDNs & PoDL/MDI6_OUT.TRXN: D2903.2 (A2), L2901.3, T2901.7 (OUT2B); also elsewhere on the board
/CDNs & PoDL/MDI6_OUT.TRXP: D2902.2 (A2), L2901.2 (4), T2901.6 (OUT1A); also elsewhere on the board
GND1: C2901.2, D2901.3, D2901.4; also elsewhere on the board
GND2: L2902.2 (4); also elsewhere on the board
SHIELD: C2903.2, D2902.1 (A1), D2903.1 (A1); also elsewhere on the board

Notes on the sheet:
ESD Protection
Change termination resistor to 100Ω for end node
CMC
Termination
4x 270mΩ 760mA Max

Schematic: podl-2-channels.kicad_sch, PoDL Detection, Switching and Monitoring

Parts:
C3001, C3002: 100n; C_0402
D3001, D3002: PMEG4002EL-QYL
Q3001, Q3002, Q3004, Q3006: DMP21D0UFB-7B; DMP21D0UFB7B; Mouser Part Number 621-DMP21D0UFB-7B
Q3003, Q3005: DMN21D2UFB-7B; DMN21D2UFB7B; Mouser Part Number 621-DMN21D2UFB-7B
R3001, R3002, R3003, R3004, R3013, R3014, R3015, R3016: 4k7; R_0402
R3005: 470R; R_0402
R3006, R3010, R3017, R3021: 2k2; R_0402
R3007, R3009, R3012, R3018, R3020, R3023: 10k; R_0402
R3008, R3019: 1k; R_0402
R3011, R3022: 100k; R_0402
U3001, U3002: TPS27S100BRRK; TPS27S100ARRKR
Z3001, Z3002: BZX884-C3V3,315; BZX884; Mouser Part Number 771-BZX884-C3V9315

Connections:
+6V5_ISO: Q3001.2 (S), Q3002.2 (S), R3009.1, R3020.1; also elsewhere on the board
+VIN_ISO: U3001.9 (IN), U3001.10 (IN), U3001.11 (IN), U3001.12 (IN), U3002.9 (IN), U3002.10 (IN), U3002.11 (IN), U3002.12 (IN); also elsewhere on the board
/CDNs & PoDL/1000BASE-T1 PoDL CDN 1/PWR+: D3001.1 (K), R3011.1, U3001.5 (OUT), U3001.6 (OUT), U3001.7 (OUT), U3001.8 (OUT); also elsewhere on the board
/CDNs & PoDL/1000BASE-T1 PoDL CDN 2/PWR+: D3002.1 (K), R3022.1, U3002.5 (OUT), U3002.6 (OUT), U3002.7 (OUT), U3002.8 (OUT); also elsewhere on the board
/CDNs & PoDL/PODL1.DET_EN: R3007.1, R3008.1; also elsewhere on the board
/CDNs & PoDL/PODL1.DET_V+: R3011.2, R3012.1, Z3001.1 (K); also elsewhere on the board
/CDNs & PoDL/PODL1.EN: R3002.1; also elsewhere on the board
/CDNs & PoDL/PODL1.IMON: C3001.1, R3001.2, R3004.1; also elsewhere on the board
/CDNs & PoDL/PODL2.DET_EN: R3018.1, R3019.1; also elsewhere on the board
/CDNs & PoDL/PODL2.DET_V+: R3022.2, R3023.1, Z3002.1 (K); also elsewhere on the board
/CDNs & PoDL/PODL2.EN: R3014.1; also elsewhere on the board
/CDNs & PoDL/PODL2.IMON: C3002.1, R3013.2, R3016.1; also elsewhere on the board
/CDNs & PoDL/PODL_DIAG_EN: R3003.1, R3015.1; also elsewhere on the board
/CDNs & PoDL/PoDL (2 Channels)/CURRENT_MIRROR_GATE: Q3001.1 (G), Q3001.3 (D), Q3002.1 (G), R3005.1
/CDNs & PoDL/PoDL (2 Channels)/CURRENT_MIRROR_OUT: Q3002.3 (D), Q3004.2 (S), Q3006.2 (S)
/CDNs & PoDL/PoDL (2 Channels)/DIAG_EN1: R3003.2, U3001.14 (DIAG_EN)
/CDNs & PoDL/PoDL (2 Channels)/DIAG_EN2: R3015.2, U3002.14 (DIAG_EN)
/CDNs & PoDL/PoDL (2 Channels)/EN1: R3002.2, U3001.3 (EN)
/CDNs & PoDL/PoDL (2 Channels)/EN2: R3014.2, U3002.3 (EN)
/CDNs & PoDL/PoDL (2 Channels)/G1: Q3003.1 (G), R3008.2
/CDNs & PoDL/PoDL (2 Channels)/G2: Q3003.3 (D), Q3004.1 (G), R3009.2
/CDNs & PoDL/PoDL (2 Channels)/G3: Q3005.1 (G), R3019.2
/CDNs & PoDL/PoDL (2 Channels)/G4: Q3005.3 (D), Q3006.1 (G), R3020.2
/CDNs & PoDL/PoDL (2 Channels)/ILIM1: R3010.2, U3001.15 (ILIM)
/CDNs & PoDL/PoDL (2 Channels)/ILIM2: R3021.2, U3002.15 (ILIM)
/CDNs & PoDL/PoDL (2 Channels)/IMON1: R3004.2, R3006.2, U3001.16 (IMON)
/CDNs & PoDL/PoDL (2 Channels)/IMON2: R3016.2, R3017.2, U3002.16 (IMON)
/CDNs & PoDL/PoDL (2 Channels)/I_PODL1: D3001.2 (A), Q3004.3 (D)
/CDNs & PoDL/PoDL (2 Channels)/I_PODL2: D3002.2 (A), Q3006.3 (D)
GND2: C3001.2, C3002.2, Q3003.2 (S), Q3005.2 (S), R3001.1, R3005.2, R3006.1, R3007.2, R3010.1, R3012.2, R3013.1, R3017.1, R3018.2, R3021.1, R3023.2, U3001.2 (GND), U3001.17 (EP), U3002.2 (GND), U3002.17 (EP), Z3001.2 (A), Z3002.2 (A); also elsewhere on the board

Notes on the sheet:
Power Switch 2
Current Source (Mirror)
Current Switches
Power Switch 1
1.1A Maximum output current 1.1A Maximum measurable current
If the output is shorted the current is still limited to 14mA, and 91mW will be dissapated (in spec)
Each channel can be enabled individually to check for PoDL devices. Since the outputs share a current source, only one channel can be checked at a time.
I_{OUT} = 0.28046 * V_{MON}
6.5 / 470 = ~14mA Within the 9-16mA PoDL spec
1/11 Potential divider and zener clamp to protect the 3V3 microcontroller IO.
During the detection phase, 9-16mA is sent into TRXP and the resulting voltage is measured. If a PoDL compatible device is detected on the other end (indicated by a 4.05-4.55V zener diode) then the full 24V is enabled.
IMON can go up to 4.75V, potential divider limits this to be withing 2.5V ADC range.

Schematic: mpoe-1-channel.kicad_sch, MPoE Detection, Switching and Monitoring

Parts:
C3101, C3102: 100n; C_0402
D3101: PMEG4002EL-QYL
F3101: 0603L008YR; Fuse_0603_1608Metric
Q3101: DMN21D2UFB-7B; DMN21D2UFB7B; Mouser Part Number 621-DMN21D2UFB-7B
Q3102: DMP21D0UFB-7B; DMP21D0UFB7B; Mouser Part Number 621-DMP21D0UFB-7B
R3101: 10k; R_0402
R3102: 1k; R_0402
R3103: 100k; R_0402
R3104, R3106, R3107, R3108: 4k7; R_0402
R3105: 1R; R_0402
R3109, R3110: 2k2; R_0402
U3101: NCS213RMUTAG; Mouser Part Number 863-NCS213RMUTAG
U3102: TPS27S100BRRK; TPS27S100ARRKR

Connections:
+2V5_ISO: C3102.2, U3101.6 (VS); also elsewhere on the board
+6V5_ISO: Q3102.2 (S), R3103.2; also elsewhere on the board
+VIN_ISO: U3102.9 (IN), U3102.10 (IN), U3102.11 (IN), U3102.12 (IN); also elsewhere on the board
/CDNs & PoDL/10BASE-T1S CDN/PWR+: D3101.1 (K), U3102.5 (OUT), U3102.6 (OUT), U3102.7 (OUT), U3102.8 (OUT); also elsewhere on the board
/CDNs & PoDL/MPoE (1 Channel)/DET: Q3101.1 (G), R3102.1
/CDNs & PoDL/MPoE (1 Channel)/DET+: Q3102.3 (D), R3105.1, U3101.2 (IN+), U3101.3 (IN+)
/CDNs & PoDL/MPoE (1 Channel)/DET-: F3101.2, R3105.2, U3101.4 (IN-), U3101.5 (IN-)
/CDNs & PoDL/MPoE (1 Channel)/DET_FUSED: D3101.2 (A), F3101.1
/CDNs & PoDL/MPoE (1 Channel)/DIAG_EN: R3107.2, U3102.14 (DIAG_EN)
/CDNs & PoDL/MPoE (1 Channel)/EN: R3106.2, U3102.3 (EN)
/CDNs & PoDL/MPoE (1 Channel)/ILIM: R3110.2, U3102.15 (ILIM)
/CDNs & PoDL/MPoE (1 Channel)/IMON: R3108.2, R3109.2, U3102.16 (IMON)
/CDNs & PoDL/MPoE (1 Channel)/~DET: Q3101.3 (D), Q3102.1 (G), R3103.1
/CDNs & PoDL/PODL3.DET_EN: R3101.2, R3102.2; also elsewhere on the board
/CDNs & PoDL/PODL3.DET_V+: U3101.10 (OUT); also elsewhere on the board
/CDNs & PoDL/PODL3.EN: R3106.1; also elsewhere on the board
/CDNs & PoDL/PODL3.IMON: C3101.1, R3104.2, R3108.1; also elsewhere on the board
/CDNs & PoDL/PODL_DIAG_EN: R3107.1; also elsewhere on the board
GND2: C3101.2, C3102.1, Q3101.2 (S), R3101.1, R3104.1, R3109.1, R3110.1, U3101.8 (REF), U3101.9 (GND), U3102.2 (GND), U3102.17 (EP); also elsewhere on the board

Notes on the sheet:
IMON can go up to 4.75V, potential divider limits this to be withing 2.5V ADC range.
Fuse protects against short circuit output
During detection, the bus is powered at 6.5V, and each PD draws 1mA for every watt they require. This is detected as a voltage drop across the 1 ohm resistor.
1.1A Maximum output current 1.1A Maximum measurable current
I_{OUT} = 0.28046 * V_{MON}

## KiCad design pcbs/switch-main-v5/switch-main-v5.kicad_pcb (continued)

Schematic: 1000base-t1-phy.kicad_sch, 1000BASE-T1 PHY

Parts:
C2001, C2002, C2003, C2004, C2005, C2007, C2008, C2009, C2010, C2011, C2012, C2013, C2014: 100n; C_0402
C2006, C2015: 10u; C_0402
C2016: 10u; C_0402_1005Metric; not fitted
Q2001: DMN21D2UFB-7B; DMN21D2UFB7B; Mouser Part Number 621-DMN21D2UFB-7B
Q2002: DMP21D0UFB-7B; DMP21D0UFB7B; Mouser Part Number 621-DMP21D0UFB-7B
R2001: 10k; R_0402_1005Metric; not fitted
R2002: 4k7; R_0402
R2003: 4k7; R_0402_1005Metric; not fitted
R2004: 4k99; R_0402
R2005: 1k; R_0402
R2006: 47k; R_0402
TP2001: 1.5mm; TestPoint_Pad_D1.5mm
U2001: 88Q2112-A2-NYD2A000-P123; 88Q2112

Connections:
+0V9_3: C2010.1, C2012.1, C2014.1, U2001.17 (DVDD), U2001.43 (DVDD); also elsewhere on the board
+1V8_PHY: C2003.1, C2005.1, C2006.1, C2007.1, C2009.1, C2011.1, C2013.1, C2015.1, R2001.2, U2001.9 (AVDD18), U2001.24 (VDDO), U2001.33 (AVDD18), U2001.40 (VDDO); also elsewhere on the board
+3V3: C2002.1, C2004.1, U2001.6 (AVDD33); also elsewhere on the board
+3V3_AON: C2008.1, Q2002.2 (S), R2006.2, U2001.46 (VLPR); also elsewhere on the board
/CDNs/MDI1_IN.TRXN: U2001.5 (MDIN); also elsewhere on the board
/CDNs/MDI1_IN.TRXP: U2001.4 (MDIP); also elsewhere on the board
/PHYs/1000BASE-T1 PHY 1/CLK_IN: C2001.2; also elsewhere on the board
/PHYs/1000BASE-T1 PHY 1/GPIO: U2001.42 (GPIO/PHYAD2)
/PHYs/1000BASE-T1 PHY 1/INH_G: Q2001.1 (G), R2005.1
/PHYs/1000BASE-T1 PHY 1/INH_OUT: R2005.2, U2001.45 (INH)
/PHYs/1000BASE-T1 PHY 1/MDC: U2001.38 (MDC); also elsewhere on the board
/PHYs/1000BASE-T1 PHY 1/MDIO: U2001.39 (MDIO); also elsewhere on the board
/PHYs/1000BASE-T1 PHY 1/RSET: R2004.2, U2001.1 (RSET)
/PHYs/1000BASE-T1 PHY 1/XTAL_IN: C2001.1, U2001.12 (XTAL_IN)
/PHYs/1000BASE-T1 PHY 1/~INH: Q2001.3 (D), Q2002.1 (G), R2006.1
/PHYs/1000BASE-T PHY/~RST: U2001.36 (~RST); also elsewhere on the board
/PHYs/PWR_EN: Q2002.3 (D); also elsewhere on the board
/PHYs/WAKE: U2001.44 (WAKE_IN); also elsewhere on the board
/PHYs/xMII1.RX_CLK: U2001.23 (RCLK); also elsewhere on the board
/PHYs/xMII1.RX_CTL: R2002.2, U2001.22 (RXC); also elsewhere on the board
/PHYs/xMII1.RX_D0: U2001.21 (RXD0/PHYAD0); also elsewhere on the board
/PHYs/xMII1.RX_D1: U2001.20 (RXD1/PHYAD1); also elsewhere on the board
/PHYs/xMII1.RX_D2: U2001.19 (RXD2/MODE0); also elsewhere on the board
/PHYs/xMII1.RX_D3: U2001.18 (RXD3/MODE1); also elsewhere on the board
/PHYs/xMII1.TX_CLK: U2001.25 (TCLK); also elsewhere on the board
/PHYs/xMII1.TX_CTL: U2001.26 (TXC); also elsewhere on the board
/PHYs/xMII1.TX_D0: U2001.27 (TXD0); also elsewhere on the board
/PHYs/xMII1.TX_D1: U2001.28 (TXD1); also elsewhere on the board
/PHYs/xMII1.TX_D2: U2001.29 (TXD2); also elsewhere on the board
/PHYs/xMII1.TX_D3: U2001.30 (TXD3); also elsewhere on the board
/PHYs/~PHY_INT_1: U2001.37 (~INT); also elsewhere on the board
GND1: C2002.2, C2003.2, C2004.2, C2005.2, C2006.2, C2007.2, C2008.2, C2009.2, C2010.2, C2011.2, C2012.2, C2013.2, C2014.2, C2015.2, C2016.2, Q2001.2 (S), R2002.1, R2003.1, R2004.1, TP2001.1 (1_1), U2001.11 (VSSC), U2001.49 (VSS); also elsewhere on the board

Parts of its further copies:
C2101, C2102, C2103, C2104, C2105, C2107, C2108, C2109, C2110, C2111, C2112, C2113, C2114, C2201, C2202, C2203, C2204, C2205, C2207, C2208, C2209, C2210, C2211, C2212, C2213, C2214, C2301, C2302, C2303, C2304, C2305, C2307, C2308, C2309, C2310, C2311, C2312, C2313, C2314, C2401, C2402, C2403, C2404, C2405, C2407, C2408, C2409, C2410, C2411, C2412, C2413, C2414: 100n; C_0402
C2106, C2115, C2206, C2215, C2306, C2315, C2406, C2415: 10u; C_0402
Q2101, Q2201, Q2301, Q2401: DMN21D2UFB-7B; DMN21D2UFB7B; Mouser Part Number 621-DMN21D2UFB-7B
Q2102, Q2202, Q2302, Q2402: DMP21D0UFB-7B; DMP21D0UFB7B; Mouser Part Number 621-DMP21D0UFB-7B
R2102, R2202, R2302, R2402: 4k7; R_0402
R2104, R2204, R2304, R2404: 4k99; R_0402
R2105, R2205, R2305, R2405: 1k; R_0402
R2106, R2206, R2306, R2406: 47k; R_0402
TP2101, TP2201, TP2301, TP2401: 1.5mm; TestPoint_Pad_D1.5mm
U2101, U2201, U2301, U2401: 88Q2112-A2-NYD2A000-P123; 88Q2112

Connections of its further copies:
+0V9_1: C2310.1, C2312.1, C2314.1, C2410.1, C2412.1, C2414.1, U2301.17 (DVDD), U2301.43 (DVDD), U2401.17 (DVDD), U2401.43 (DVDD); also elsewhere on the board
+0V9_2: C2110.1, C2112.1, C2114.1, C2210.1, C2212.1, C2214.1, U2101.17 (DVDD), U2101.43 (DVDD), U2201.17 (DVDD), U2201.43 (DVDD); also elsewhere on the board
+1V8_PHY: C2103.1, C2105.1, C2106.1, C2107.1, C2109.1, C2111.1, C2113.1, C2115.1, C2203.1, C2205.1, C2206.1, C2207.1, C2209.1, C2211.1, C2213.1, C2215.1, C2303.1, C2305.1, C2306.1, C2307.1, C2309.1, C2311.1, C2313.1, C2315.1, C2403.1, C2405.1, C2406.1, C2407.1, C2409.1, C2411.1, C2413.1, C2415.1, U2101.9 (AVDD18), U2101.24 (VDDO), U2101.33 (AVDD18), U2101.40 (VDDO), U2201.9 (AVDD18), U2201.24 (VDDO), U2201.33 (AVDD18), U2201.40 (VDDO), U2301.9 (AVDD18), U2301.24 (VDDO), U2301.33 (AVDD18), U2301.40 (VDDO), U2401.9 (AVDD18), U2401.24 (VDDO), U2401.33 (AVDD18), U2401.40 (VDDO); also elsewhere on the board
+3V3: C2102.1, C2104.1, C2202.1, C2204.1, C2302.1, C2304.1, C2402.1, C2404.1, U2101.6 (AVDD33), U2201.6 (AVDD33), U2301.6 (AVDD33), U2401.6 (AVDD33); also elsewhere on the board
+3V3_AON: C2108.1, C2208.1, C2308.1, C2408.1, Q2102.2 (S), Q2202.2 (S), Q2302.2 (S), Q2402.2 (S), R2106.2, R2206.2, R2306.2, R2406.2, U2101.46 (VLPR), U2201.46 (VLPR), U2301.46 (VLPR), U2401.46 (VLPR); also elsewhere on the board
/CDNs & PoDL/MDI4_IN.TRXN: U2301.5 (MDIN); also elsewhere on the board
/CDNs & PoDL/MDI4_IN.TRXP: U2301.4 (MDIP); also elsewhere on the board
/CDNs & PoDL/MDI5_IN.TRXN: U2401.5 (MDIN); also elsewhere on the board
/CDNs & PoDL/MDI5_IN.TRXP: U2401.4 (MDIP); also elsewhere on the board
/CDNs/MDI2_IN.TRXN: U2101.5 (MDIN); also elsewhere on the board
/CDNs/MDI2_IN.TRXP: U2101.4 (MDIP); also elsewhere on the board
/CDNs/MDI3_IN.TRXN: U2201.5 (MDIN); also elsewhere on the board
/CDNs/MDI3_IN.TRXP: U2201.4 (MDIP); also elsewhere on the board
/PHYs/1000BASE-T1 PHY 2/CLK_IN: C2101.2; also elsewhere on the board
/PHYs/1000BASE-T1 PHY 2/GPIO: U2101.42 (GPIO/PHYAD2)
/PHYs/1000BASE-T1 PHY 2/INH_G: Q2101.1 (G), R2105.1
/PHYs/1000BASE-T1 PHY 2/INH_OUT: R2105.2, U2101.45 (INH)
/PHYs/1000BASE-T1 PHY 2/MDC: U2101.38 (MDC); also elsewhere on the board
/PHYs/1000BASE-T1 PHY 2/MDIO: U2101.39 (MDIO); also elsewhere on the board
/PHYs/1000BASE-T1 PHY 2/RSET: R2104.2, U2101.1 (RSET)
/PHYs/1000BASE-T1 PHY 2/XTAL_IN: C2101.1, U2101.12 (XTAL_IN)
/PHYs/1000BASE-T1 PHY 2/~INH: Q2101.3 (D), Q2102.1 (G), R2106.1
/PHYs/1000BASE-T1 PHY 3/CLK_IN: C2201.2; also elsewhere on the board
/PHYs/1000BASE-T1 PHY 3/GPIO: U2201.42 (GPIO/PHYAD2)
/PHYs/1000BASE-T1 PHY 3/INH_G: Q2201.1 (G), R2205.1
/PHYs/1000BASE-T1 PHY 3/INH_OUT: R2205.2, U2201.45 (INH)
/PHYs/1000BASE-T1 PHY 3/MDC: U2201.38 (MDC); also elsewhere on the board
/PHYs/1000BASE-T1 PHY 3/MDIO: U2201.39 (MDIO); also elsewhere on the board
/PHYs/1000BASE-T1 PHY 3/RSET: R2204.2, U2201.1 (RSET)
/PHYs/1000BASE-T1 PHY 3/XTAL_IN: C2201.1, U2201.12 (XTAL_IN)
/PHYs/1000BASE-T1 PHY 3/~INH: Q2201.3 (D), Q2202.1 (G), R2206.1
/PHYs/1000BASE-T1 PHY 4/CLK_IN: C2301.2; also elsewhere on the board
/PHYs/1000BASE-T1 PHY 4/GPIO: U2301.42 (GPIO/PHYAD2)
/PHYs/1000BASE-T1 PHY 4/INH_G: Q2301.1 (G), R2305.1
/PHYs/1000BASE-T1 PHY 4/INH_OUT: R2305.2, U2301.45 (INH)
/PHYs/1000BASE-T1 PHY 4/MDC: U2301.38 (MDC); also elsewhere on the board
/PHYs/1000BASE-T1 PHY 4/MDIO: U2301.39 (MDIO); also elsewhere on the board
/PHYs/1000BASE-T1 PHY 4/RSET: R2304.2, U2301.1 (RSET)
/PHYs/1000BASE-T1 PHY 4/XTAL_IN: C2301.1, U2301.12 (XTAL_IN)
/PHYs/1000BASE-T1 PHY 4/~INH: Q2301.3 (D), Q2302.1 (G), R2306.1
/PHYs/1000BASE-T1 PHY 5/CLK_IN: C2401.2; also elsewhere on the board
/PHYs/1000BASE-T1 PHY 5/GPIO: U2401.42 (GPIO/PHYAD2)
/PHYs/1000BASE-T1 PHY 5/INH_G: Q2401.1 (G), R2405.1
/PHYs/1000BASE-T1 PHY 5/INH_OUT: R2405.2, U2401.45 (INH)
/PHYs/1000BASE-T1 PHY 5/MDC: U2401.38 (MDC); also elsewhere on the board
/PHYs/1000BASE-T1 PHY 5/MDIO: U2401.39 (MDIO); also elsewhere on the board
/PHYs/1000BASE-T1 PHY 5/RSET: R2404.2, U2401.1 (RSET)
/PHYs/1000BASE-T1 PHY 5/XTAL_IN: C2401.1, U2401.12 (XTAL_IN)
/PHYs/1000BASE-T1 PHY 5/~INH: Q2401.3 (D), Q2402.1 (G), R2406.1
/PHYs/1000BASE-T PHY/~RST: U2101.36 (~RST), U2201.36 (~RST), U2301.36 (~RST), U2401.36 (~RST); also elsewhere on the board
/PHYs/PWR_EN: Q2102.3 (D), Q2202.3 (D), Q2302.3 (D), Q2402.3 (D); also elsewhere on the board
/PHYs/WAKE: U2101.44 (WAKE_IN), U2201.44 (WAKE_IN), U2301.44 (WAKE_IN), U2401.44 (WAKE_IN); also elsewhere on the board
/PHYs/xMII2.RX_CLK: U2101.23 (RCLK); also elsewhere on the board
/PHYs/xMII2.RX_CTL: R2102.2, U2101.22 (RXC); also elsewhere on the board
/PHYs/xMII2.RX_D0: U2101.21 (RXD0/PHYAD0); also elsewhere on the board
/PHYs/xMII2.RX_D1: U2101.20 (RXD1/PHYAD1); also elsewhere on the board
/PHYs/xMII2.RX_D2: U2101.19 (RXD2/MODE0); also elsewhere on the board
/PHYs/xMII2.RX_D3: U2101.18 (RXD3/MODE1); also elsewhere on the board
/PHYs/xMII2.TX_CLK: U2101.25 (TCLK); also elsewhere on the board
/PHYs/xMII2.TX_CTL: U2101.26 (TXC); also elsewhere on the board
/PHYs/xMII2.TX_D0: U2101.27 (TXD0); also elsewhere on the board
/PHYs/xMII2.TX_D1: U2101.28 (TXD1); also elsewhere on the board
/PHYs/xMII2.TX_D2: U2101.29 (TXD2); also elsewhere on the board
/PHYs/xMII2.TX_D3: U2101.30 (TXD3); also elsewhere on the board
/PHYs/xMII3.RX_CLK: U2201.23 (RCLK); also elsewhere on the board
/PHYs/xMII3.RX_CTL: R2202.2, U2201.22 (RXC); also elsewhere on the board
/PHYs/xMII3.RX_D0: U2201.21 (RXD0/PHYAD0); also elsewhere on the board
/PHYs/xMII3.RX_D1: U2201.20 (RXD1/PHYAD1); also elsewhere on the board
/PHYs/xMII3.RX_D2: U2201.19 (RXD2/MODE0); also elsewhere on the board
/PHYs/xMII3.RX_D3: U2201.18 (RXD3/MODE1); also elsewhere on the board
/PHYs/xMII3.TX_CLK: U2201.25 (TCLK); also elsewhere on the board
/PHYs/xMII3.TX_CTL: U2201.26 (TXC); also elsewhere on the board
/PHYs/xMII3.TX_D0: U2201.27 (TXD0); also elsewhere on the board
/PHYs/xMII3.TX_D1: U2201.28 (TXD1); also elsewhere on the board
/PHYs/xMII3.TX_D2: U2201.29 (TXD2); also elsewhere on the board
/PHYs/xMII3.TX_D3: U2201.30 (TXD3); also elsewhere on the board
/PHYs/xMII4.RX_CLK: U2301.23 (RCLK); also elsewhere on the board
/PHYs/xMII4.RX_CTL: R2302.2, U2301.22 (RXC); also elsewhere on the board
/PHYs/xMII4.RX_D0: U2301.21 (RXD0/PHYAD0); also elsewhere on the board
/PHYs/xMII4.RX_D1: U2301.20 (RXD1/PHYAD1); also elsewhere on the board
/PHYs/xMII4.RX_D2: U2301.19 (RXD2/MODE0); also elsewhere on the board
/PHYs/xMII4.RX_D3: U2301.18 (RXD3/MODE1); also elsewhere on the board
/PHYs/xMII4.TX_CLK: U2301.25 (TCLK); also elsewhere on the board
/PHYs/xMII4.TX_CTL: U2301.26 (TXC); also elsewhere on the board
/PHYs/xMII4.TX_D0: U2301.27 (TXD0); also elsewhere on the board
/PHYs/xMII4.TX_D1: U2301.28 (TXD1); also elsewhere on the board
/PHYs/xMII4.TX_D2: U2301.29 (TXD2); also elsewhere on the board
/PHYs/xMII4.TX_D3: U2301.30 (TXD3); also elsewhere on the board
/PHYs/xMII5.RX_CLK: U2401.23 (RCLK); also elsewhere on the board
/PHYs/xMII5.RX_CTL: R2402.2, U2401.22 (RXC); also elsewhere on the board
/PHYs/xMII5.RX_D0: U2401.21 (RXD0/PHYAD0); also elsewhere on the board
/PHYs/xMII5.RX_D1: U2401.20 (RXD1/PHYAD1); also elsewhere on the board
/PHYs/xMII5.RX_D2: U2401.19 (RXD2/MODE0); also elsewhere on the board
/PHYs/xMII5.RX_D3: U2401.18 (RXD3/MODE1); also elsewhere on the board
/PHYs/xMII5.TX_CLK: U2401.25 (TCLK); also elsewhere on the board
/PHYs/xMII5.TX_CTL: U2401.26 (TXC); also elsewhere on the board
/PHYs/xMII5.TX_D0: U2401.27 (TXD0); also elsewhere on the board
/PHYs/xMII5.TX_D1: U2401.28 (TXD1); also elsewhere on the board
/PHYs/xMII5.TX_D2: U2401.29 (TXD2); also elsewhere on the board
/PHYs/xMII5.TX_D3: U2401.30 (TXD3); also elsewhere on the board
/PHYs/~PHY_INT_2: U2101.37 (~INT); also elsewhere on the board
/PHYs/~PHY_INT_3: U2201.37 (~INT); also elsewhere on the board
/PHYs/~PHY_INT_4: U2301.37 (~INT); also elsewhere on the board
/PHYs/~PHY_INT_5: U2401.37 (~INT); also elsewhere on the board
GND1: C2102.2, C2103.2, C2104.2, C2105.2, C2106.2, C2107.2, C2108.2, C2109.2, C2110.2, C2111.2, C2112.2, C2113.2, C2114.2, C2115.2, C2202.2, C2203.2, C2204.2, C2205.2, C2206.2, C2207.2, C2208.2, C2209.2, C2210.2, C2211.2, C2212.2, C2213.2, C2214.2, C2215.2, C2302.2, C2303.2, C2304.2, C2305.2, C2306.2, C2307.2, C2308.2, C2309.2, C2310.2, C2311.2, C2312.2, C2313.2, C2314.2, C2315.2, C2402.2, C2403.2, C2404.2, C2405.2, C2406.2, C2407.2, C2408.2, C2409.2, C2410.2, C2411.2, C2412.2, C2413.2, C2414.2, C2415.2, Q2101.2 (S), Q2201.2 (S), Q2301.2 (S), Q2401.2 (S), R2102.1, R2104.1, R2202.1, R2204.1, R2302.1, R2304.1, R2402.1, R2404.1, TP2101.1 (1_1), TP2201.1 (1_1), TP2301.1 (1_1), TP2401.1 (1_1), U2101.11 (VSSC), U2101.49 (VSS), U2201.11 (VSSC), U2201.49 (VSS), U2301.11 (VSSC), U2301.49 (VSS), U2401.11 (VSSC), U2401.49 (VSS); also elsewhere on the board

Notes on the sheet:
AVDD18: 145mA Typ 152mA Max
RSET Must be 1% tolerance
No pulldowns on PHYADx means address will be 0x00.
AVDD33: 25mA Typ 27mA Max
VDDO: 18.6mA Typ
DVDD: 202mA Typ 359mA Max
This INH circuit is non-standard, and requires testing.
MODE[1:0] = 0x00 means the PHY will start as a 100BASE-T1 master, 0x01 means 100BASE-T1 slave.
Maximum allowed noise on any supply is 50mV peak to peak
Internal GPIO pullups needed for ~{INT}.
Pulldown on RXC means RGMII is selected as the interface.

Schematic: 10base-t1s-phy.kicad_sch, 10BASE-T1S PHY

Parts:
C2501, C2502, C2503: 10u; C_0402
C2504, C2505, C2506, C2510: 100n; C_0402
C2507, C2508, C2509, C2511: 10n; C_0402
R2501, R2502, R2504, R2505, R2506, R2507: 10k; R_0402
R2503: 10k; R_0402_1005Metric; not fitted
R2508: 12k4; R_0402
U2501: LAN8671C2-E_U3B; QFN50P400X400X100-25N-D; Mouser Part Number 579-LAN8671C2-E/U3B
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

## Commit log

2025-10-09 Added WIP files & component library
    [1000base-t-phy.kicad_sch, 1000base-t1-cdn.kicad_sch, 1000base-t1-phy.kicad_sch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]
2025-10-11 MDIO multiplexing
    [1000base-t-phy.kicad_sch, 1000base-t1-cdn.kicad_sch, 1000base-t1-phy.kicad_sch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]
2025-10-11 Started updating regulators for v5
    [0v9_buck_converter.kicad_sch, 1v0_buck_converter.kicad_sch, 1v2_buck_converter.kicad_sch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]
2025-11-07 Updated 1v0_buck_converter feedback resistors
    [1000base-t-phy.kicad_sch, 1000base-t1-cdn.kicad_sch, 1000base-t1-phy.kicad_sch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]
2025-11-13 Changed main 3V3 regulator to 3A, added switch 2 crystal & other changes
    [0v9_buck_converter.kicad_sch, 1000base-t-phy.kicad_sch, 1000base-t1-cdn-shield.kicad_sch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]
2025-11-15 Routed and length matched inter-switch RGMII
2025-11-15 Routed switch 1 clocking
    [phy-clock-control.kicad_sch]
2025-11-16 PHY3 RGMII routed and length matched
    [1000base-t1-phy.kicad_sch, phys.kicad_sch]
2025-11-17 PHY 1 & 2 routing progress and passive placement
    [phy-clock-control.kicad_sch, switch_main_v5.kicad_sch]
2025-11-17 Placed 1000BASE-T PHY decoupling capacitors
    [cdns.kicad_sch, ethernet-connectors.kicad_sch, power-in-isolated.kicad_sch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]
2025-11-19 Fixed test points
    [1000base-t-phy.kicad_sch, 2v5_buck_converter.kicad_sch, phy-clock-control.kicad_sch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]
2025-11-19 Moved 0V9 regulators
    [1v8_buck_converter.kicad_sch, phy-clock-control.kicad_sch, power-ethernet.kicad_sch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]
2025-11-20 1V0 Rail done
    [1v0_buck_converter.kicad_sch, 1v2_buck_converter.kicad_sch, 1v8_buck_converter.kicad_sch]
2025-11-21 Placed most remaining passives and test points
    [1000base-t-phy.kicad_sch, 1v0_buck_converter.kicad_sch, 1v2_buck_converter.kicad_sch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]
2025-11-23 All signals routed, need to do power still
    [1000base-t1-phy.kicad_sch, 10base-t1s-phy.kicad_sch, phy-clock-control.kicad_sch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]
2025-11-24 1V8 Power routed
    [switch_main_v5.kicad_pcb]
2025-11-25 1V8_PHY Power routed
    [switch_main_v5.kicad_pcb]
2025-11-26 0 Unrouted
    [switch_main_v5.kicad_pcb]
2025-11-27 PHY 4 & 5 Length matching
    [switch_main_v5.kicad_pcb]
2025-11-28 PHY 3 Length matching
    [switch_main_v5.kicad_pcb]
2025-11-29 PHY 2 Length matching
    [switch_main_v5.kicad_pcb]
2025-11-30 PHY 0 & 1 Length matching
    [switch_main_v5.kicad_pcb]
2025-11-30 Fixed DRC issues and filleted outer layer traces
    [power-ethernet.kicad_sch, switch_main_v5.kicad_pcb]
2025-12-01 Added PoDL indicator to silkscreen
    [switch_main_v5.kicad_pcb]
2025-12-02 Added & updated media
    [switch_main_v5.kicad_pcb]
2025-12-04 Made 10BASE-T1S PoDL tracks wider and untented certain viewers
    [switch_main_v5.kicad_pcb]
2025-12-22 Added test rig PCB
    [switch_main_v5_test_rig.kicad_pcb, switch_main_v5_test_rig.kicad_sch]
2025-12-22 Changed primary side input current limit to 545mA (from 255mA which is less than the max possible load current of 326mA)
    [power-in-isolated.kicad_sch, power-in.kicad_sch, switch_main_v5.kicad_pcb]
2025-12-23 Tidied schematic and PCB
    [0v9_buck_converter.kicad_sch, 1000base-t-phy.kicad_sch, 1000base-t1-cdn-shield.kicad_sch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]
2025-12-25 Updated crystal load capacitors
    [primary-mcu.kicad_sch, switch_main_v5.kicad_pcb, switch_main_v5_test_rig.kicad_pcb]
2025-12-27 Removed tenting from bottom side via pads
    [switch_main_v5.kicad_pcb]
2025-12-29 Removed one switch crystal so both are now clocked from the same source and timestamps won't drift
    [switch-0.kicad_sch, switch-1.kicad_sch, switch_main_v5.kicad_pcb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]
2026-01-01 Updated schematic comments
    [switch-0.kicad_sch, switch-1.kicad_sch]
2026-01-03 Updated reference designators
    [switch-0.kicad_sch, switch-1.kicad_sch, switch_main_v5.kicad_pcb]
2026-01-26 Minor schematic label update
    [switch-0.kicad_sch, switch-1.kicad_sch]
2026-03-18 Cleaned up repository
    [0v9_buck_converter.kicad_sch, 1000base-t-phy.kicad_sch, 1000base-t1-cdn-shield.kicad_sch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]
2026-04-24 Fixed bug with IO voltage of connection between switch 0 and switch 1
    [0v9_buck_converter.kicad_sch, 1000base-t-phy.kicad_sch, 1000base-t1-cdn-shield.kicad_sch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]
2026-04-25 Added errata
    [switch-1.kicad_sch, switch-main-v5.kicad_pcb]
2026-04-25 Documented fix for wrong IO voltage errata
2026-04-25 Tidied up PCB
    [switch-main-v5.kicad_pcb]
